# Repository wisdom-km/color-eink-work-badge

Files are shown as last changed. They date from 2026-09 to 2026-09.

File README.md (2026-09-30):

# P36 当前入口（2026-09-30）

当前新设计为3.6寸六色400×600、手机+USB更新、一体66×109×11.1mm工牌。先读[中文开始说明](docs/portrait/START_HERE.md)。源码评审候选仍有PH/SW3、FPC/C118–C121装配阻断，NFC功能尚未设计完成，未做实体测试，不可制造放行。

P36路径：hardware/portrait/、firmware/portrait36/、docs/portrait/。最终已布线KiCad10原生PCB是铜线权威源；不得运行generate.py/gen_pcb.py/旧import_route.py覆盖铜线，不用pcbnew9保存。新电气修订必须备份并重新完整验证；当前报告仅绑定当前SHA。用户已授权此次重新选型、设计和当前文档同步。

## 以下为H2历史基线范围

以下旧4.2寸/ST25/6.3mm/F2未实现及旧流程仅适用历史H2，不覆盖P36新需求/入口/证据。保留原文供追溯；不要按旧生成命令操作P36。通用中文回复、禁止未经要求PR及许可证要求仍有效。

# chroma-badge（BADGE-42C）：4.2 寸四色墨水屏 NFC 工牌

> **当前：** [状态](docs/06-current-status.md) · [交接](docs/03-handoff.md) · [流程](docs/09-process.md)（许可证 / CI / 贴胶 / 生产包）。2026-09-14 复审是**旧 564 段板**档案，不要当现板。

仓库：https://github.com/wisdom-km/chroma-badge

一块 **6.3 mm 厚**的电子工牌：4.2" 黑白红黄四色墨水屏 + ESP32-C3（Wi-Fi/BLE/原生 USB）+ ST25DV64KC NFC + ≤2 mm 超薄锂电 + USB-C。固件目前是 v0.2 上电自检；手机传图（F2）未写。

| 背面 PCB 渲染 | 外壳（FreeCAD） |
|---|---|
| pcb | 见 `hardware/enclosure/output/badge_assembly.step` |

## 在本地接着做

```bash
git clone https://github.com/wisdom-km/chroma-badge.git
cd chroma-badge
```

用 Cursor **打开这个文件夹**（本地 Agent）。根目录 `AGENTS.md` 和 `.cursor/rules/badge.mdc` 会带上约定。

## 仓库

- `LICENSE.md`：硬件 CERN-OHL-P-2.0，固件/脚本 MIT
- `AGENTS.md`：硬性约定与当前进度
- `docs/01-architecture-decisions.md`：选型
- `docs/02-bom-and-cost.md`：BOM；屏贴胶 3M 467MP
- `docs/03-handoff.md`：复现步骤与**当前板**指纹
- `docs/09-process.md`：CI、生产包、贴胶
- `hardware/pcb/`：由 `scripts/design.py` 生成
- `firmware/README.md`：v0.2 自检；不要覆盖 `output/badge-42c-v0.1*.bin`

## 快速开始

全量 ERC/DRC 需要 KiCad **10.0.6**。不要把 `gen_pcb.py` 当日常命令（会清布线）。日常检查：

```bash
cd hardware/pcb
python3 scripts/check_netlist.py
./scripts/export.sh --check-only
```

自动布线流程见 `docs/03-handoff.md` 第 3 节。

## 状态

**H2（2026-09-15）：** 58 封装，PCB **680 段 / 115 过孔**，J1.7 NC。KiCad 10.0.6 全量 ERC/DRC 0。USB **0.8 mm**。固件 **v0.2 F1**。没有生产 zip。

下一步：打样实机；F2 须选定一条传图路线。

## 第三方内容

- 乐鑫 KiCad 库（ESP32-C3-MINI-1）：CC-BY-SA 4.0
- HRO TYPE-C-31-M-14 封装：jenschr/USB-C-Connectors，公有领域
- 其余符号/封装来自 KiCad 官方库

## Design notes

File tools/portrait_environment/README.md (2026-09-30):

# 云端工具链安装与验证（2026-09-30）

本目录记录对已提交的 BADGE-42C H2 基线和本次工具安装的验证。它不是竖版新板的验证报告，也不是生产放行。

## 使用

从仓库根目录执行：

```sh
source tools/portrait_environment/env.sh
kicad-cli version
pio --version
java --version
freerouting -help
freecad-python -c 'import FreeCAD,Part; print(FreeCAD.Version())'
cadquery-python -c 'import cadquery; print(cadquery.__version__)'
```

实际程序安装在 `/workspace/scratch/200245c5fbc3/toolchain`，HOME/XDG/PlatformIO 包与构建缓存也都在该工作区内；不改系统路径、原固件输出或系统安全配置。`env.sh` 绑定当前云端路径，转移到另一台机器须重新安装并调整路径。

## 已验证

| 工具 / 检查 | 版本 / 结果 | 证据 |
|---|---|---|
| KiCad CLI | 官方 Linux Lite AppImage 10.0.6，版本命令 exit 0 | `logs/kicad10-version.log` |
| KiCad pcbnew | 系统 9.0.2，导入成功 | `logs/inventory-initial.log` |
| 原板全量 ERC | 0 violations，exit 0 | `erc-baseline-configured.json` |
| 原板全量 DRC | 0 violations / unconnected / schematic parity，exit 0 | `drc-baseline-configured.json` |
| 网表 vs design.py | 63 nets，exit 0 | `logs/netlist.log` |
| EPD 主机探针 | g++ 14.2.0，20/20 case，exit 0 | `host-probes/epd-probes.json`, `logs/host-probes.log` |
| FreeCAD Part | 1.0.0，立方体有效性、STEP 导出/回读与体积，exit 0 | `logs/freecad-part-smoke.log` |
| CadQuery | 2.7.0，实体体积/有效性，exit 0 | `logs/cadquery-smoke.log` |
| OpenSCAD | 2021.01，STL 导出，exit 0 | `logs/openscad-smoke.log` |
| Java | Temurin JRE 25.0.4.1+1，版本命令 exit 0 | `logs/java25-version.log` |
| Freerouting | 官方 2.4.1，`-help` exit 0 | `logs/freerouting-help.log` |

全量 KiCad 检查包含 warnings、errors、exclusions；DRC 开启 schematic parity。初次未初始化全局 symbol/footprint table 的运行出现配置缺库 warnings，保留在 `*-baseline.json`，**最终结果以 `*-baseline-configured.json` 为准**。全局表已从同一 KiCad 10.0.6 AppImage 自带模板复制到隔离配置目录。

FreeCAD 的 `freecadcmd` 启动在此环境崩溃；已改用官方已安装模块的系统 `/usr/bin/python3` 入口（`freecad-python` 包装器）。CadQuery 使用预装的 Python 3.12；不要与 FreeCAD 的 Python 3.13 混用。

KiCad 使用 Lite 包，不包含官方全套 3D 模型；本次 ERC/DRC 不需要这些模型。机械外观检查必须另外确认所需模型覆盖率，不能以此冒充 3D 全覆盖。

## 固件构建

PlatformIO Core 6.2.0 安装成功；安装日志为 `logs/platformio-install.log`，Python 依赖锁定快照为 `platformio-python-requirements.txt`。工程固定 espressif32@7.1.3。

两次完整编译均通过 exit 0：

1. 当前工作目录构建（包括新 `portrait_frame.cpp` 的当时版本）：`logs/platformio-build.log`
2. 从 HEAD `84f226487c97b10a132f7f11740d5ee0b5bd14c0` 导出的原固件隔离快照：`logs/platformio-baseline-build.log`

两次大小均为 RAM 15320 / 327680 B（4.7%）、Flash 284324 / 1310720 B（21.7%）。未使用的新增代码可被链接器移除，因此大小相同不代表新屏硬件行为已验证。

复现当前固件：`source tools/portrait_environment/env.sh && pio run -d firmware`。原快照使用独立 `PLATFORMIO_BUILD_DIR=$BADGE_TOOLCHAIN_ROOT/platformio-build-baseline`。实际包版本见 `platformio-packages.json`。

首次安装的部分首选包镜像下载校验不匹配，PlatformIO 拒绝后自动改用备用镜像成功；未禁用或跳过完整性校验。完整原始记录保留在构建日志。

`baseline-bin-sha256.txt` 保存原 `firmware/output/badge-42c-v0.1*.bin` 的 SHA256。原 v0.1 应用大小保持 296512 字节；三份文件构建后 SHA256 复核全部 OK，见 `logs/baseline-bin-recheck.log`。

## 来源与完整性

`download-provenance.json` 保存官方来源和哈希。Java 与 Freerouting 下载内容已与官方 API 发布 SHA256 逐字匹配。KiCad 下载自官方页面列出的 CERN 镜像，并记录本地 SHA256；该记录不是独立签名校验。

- KiCad：https://www.kicad.org/download/linux/
- Freerouting：https://github.com/freerouting/freerouting/releases/tag/v2.4.1
- Java：https://adoptium.net/temurin/releases/
- PlatformIO：https://pypi.org/project/platformio/6.2.0/

## 没有做 / 不代表通过

- 未操作实物，未烧录；USB、充电、屏幕 BUSY、NFC、休眠电流仍需真实样机
- 未运行真正 Freerouting 路由任务；后续严格遵守仓库交互 shell、相对路径、日志重定向约定
- 未生成生产 Gerber、生产 ZIP 或下单文件
- 原板 ERC/DRC 通过不意味着竖版新板通过

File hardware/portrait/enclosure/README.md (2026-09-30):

# C1 一体工牌机械评审候选

当前66×109×11.1mm，FreeCAD直接打开output/portrait_assembly_revisionB.FCStd。已保存颜色并关闭/重开验证，116对象，111显示/5审计预留隐藏。历史8.1mm A文件不是当前交付。不要再次保存已冻结native仅为截图，避免SHA链失效。

## 验证及实际范围

七个真实stage完成，execution-provenance.json状态EXECUTED_REVIEW_REQUIRED_C1_PIPELINE；STEP/STL拓扑和原生BREP有效。116对象=36机械/材料/审计/预留+80器件高度代理，81位号中J3为有来源USB盒；不是全厂家装配，不含真实FPC/电池导线/门禁凭证/螺钉实体。PCB core来自最终已布线KiCad板，名义完整0.8审计体预算铜/阻焊；不能假定每个蚀刻边缘承压高度一致。

assembly_review_gates.json保留PH插头预留与SW3、全块FPC预留与C118–C121的5条装配阻断。TP2/TP3庭院笔宽微交叠原样保留，真实铜pad bbox为0交叠。不能缩预留盒掩盖冲突。全1.2mm屏审计与前垫保守交叠仍保留；局部上部0.85/底9mm1.2模型不代表厂家批准压持。制造放行始终blocked。

实际图：portrait_native_C1_iso/front/internal.png、portrait_actual_section.png（厚度显示5倍）、portrait_layer_stack.png。旧portrait_review_overview.png文案可能误读门禁已集成，因此不交付；NFC电路/inlay当前未集成，制式和位置待设计。

## 材料候选与采购数量

- 前框1、齐平后盖1：烟灰半透PETG或经过验证的韧性聚合物，打印方向/收缩/疲劳未合格
- M2×10螺钉4枚，M2六角螺母4枚：名义对边4.0/厚1.6，槽宽4.2/高1.8；实际头部、盲孔和公差需实配，拆卸防散落
- 屏PSA：3M468MP标称0.13mm，3条；左右各0.9×70mm，上50×0.9mm，仅非AA边缘，屏厂胶相容与夹持许可未取得
- 前垫：PORON4790-92PL-09020标称0.50±0.10mm，3条；另3条0.06mm PSA为厚度预算，未锁定可买胶料MPN
- 后垫4处：各0.05mm post PSA +0.15mm PET +0.05mm foam PSA +PORON4701-30密度400、自由0.79±15%压至0.60mm（名义24.05%）。两个0.05胶层为受控预算，不能假称已锁采购MPN

25层名称/坐标在c1_config.OBJECTS和mechanical_expectation.json。后垫均2×2mm，PCB坐标[1,1,3,3]、[55,18,57,20]、[1,89.64,3,91.64]、[41.6,90.14,43.6,92.14]。原厂材料来源链接见c1_config.SOURCES；JST原图sources/JST-PH-official.pdf。

## 首件测量，不可强装

回流后先测PCB平整度、每点承压完成厚度；不要靠螺钉把翘板或玻璃压平。前垫实际间隙目标0.10–0.25mm；名义0.18/最大局部屏厚0.11，示例公差会降到−0.04，未测不可放行。座Z候选2.30..2.60且剩壁≥0.90；超范围重做。

后选PET：实测肩台到支柱H、当地板厚T、两胶a1/a2、自由泡棉f，PET=H−T−a1−a2−0.75f。名义H1.65/T0.8/a总0.10/f0.79得0.1575mm。选垫0..0.40、增量0.025/0.05候选，目标压缩20–30%；达不到则返工支柱/换受控料，不加螺钉力压板。

在全部肩台/玻璃角测含偏转侧游隙，不只中心平移。UPDATE梁0.65厚×13长×4宽、槽0.45；实际静态间隙0.10–0.20，验证行程/止挡/释放/疲劳。0.6名义止挡不证明安全过行程。原配100–102mm电池线和PH配对、FPC弯折/锁扣、USB实物均须试装。RF、温升、跌落、挂绳和磨损仍未测。

## 复现

有效配置为c1_config.configure(只读H2 PORTRAIT)。本次迁移--setup已执行。常规重新生成先c1_pipeline.py --run，再在真实FreeCAD中运行OpenC1RevisionB.FCMacro，最后--finalize。宏只用于该次headless输出，不可对已样式化文件反复执行。任何源修改都要重新验证全链；不得改冻结电气板后沿用旧报告。日常查看直接打开当前FCStd，无需宏。

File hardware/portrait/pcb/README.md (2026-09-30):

# P36 当前电气工程

KiCad10.0.6打开badge.kicad_pro。3.6E六色50针参考电路，非H2旧24针屏。原生已布线badge.kicad_pcb是最终铜线权威源；81封装、968线段、115过孔、10区，板58×92.64×0.8mm，元件B面。

最终证据在仓库根verification/visible-final：DRC/未连/原理图parity0，ignored为空；ERC0错误9条逐项审阅single_global_label警告。81元件/259连接pin/28NC对源一致，warning-review.json保留线端点证据。五页为主索引、usb_mcu、power、boost、display。

设计源scripts/design.py、readable_schematic.py与pinned库均可编辑；不要为检查调用generate.py/gen_pcb.py/import_route.py，它们可能清布线。不要用系统pcbnew9保存本10版板。任何新电气/布线修订须新备份及全量ERC/DRC/parity，原证据不能沿用。

屏关电后SPI控制脚停LOW，BUSY无上拉。独立逻辑/boost磁珠，C100在V_B。电池PH pin1GND/pin2VBAT，仍必须量来料；USB HRO额定1A、0.75对0.8板厚实配待测。充电100mA无电芯NTC。完整采购MPN候选见docs/portrait/procurement_candidates.csv；candidate_bom.csv只是五列工程导出。

当前NFC功能未设计/未集成。PH/SW3和FPC/C118–121空间阻断仍需修订或实物几何证明，EDA0不能放行制造。参见docs/portrait/START_HERE.md。

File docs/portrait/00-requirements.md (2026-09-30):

# P36 已确认需求与决策

2026-09-30；原仓库基线84f2264。用户明确旧显示/尺寸/稳定性不满意，重新选型；选定3.6英寸六色竖向400×600；中等科技公司工牌尺寸；参考一体透明结构，无外卡套；手机与USB均可更新；所有建模、PCB和测试在云电脑可见操作。希望合法门禁但不知道系统。

工程方案为Waveshare32651裸屏、50P0.5FPC、ESP32-C3-MINI-1-N4X、保护500mAh原型电池；板58×92.64×0.8，C1外壳66×109×11.1。厚度从历史8.1增加以容纳有来源保护电池和空间预算；不照抄参考TFT/麦克风/扬声器/50g指标。

放弃旋转旧4.2屏、规格矛盾的GDEH037E01以及外卡套方案。当前NFC功能尚未设计完成，无电路或inlay集成；待确定系统和合法发行方式，不能承诺通用门禁。完整现状和制造阻断见START_HERE.md。

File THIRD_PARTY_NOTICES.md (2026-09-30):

# 第三方归属与修改

补充根LICENSE.md，项目硬件CERN-OHL-P-2.0，项目固件/脚本MIT，第三方保持原许可。

KiCad Community符号/封装来自本机官方库快照，安装资料登记Copyright2025，CC-BY-SA4.0附KiCad Libraries Exception。设计例外不把再分发库集合改成MIT；保留LICENSES的原版权许可。P36修改了Connector过滤器等，不能称未修改官方库。https://www.kicad.org/libraries/license/

Espressif符号/ESP32-C3封装和STEP继承自项目快照，CC-BY-SA4.0及上游KiCad例外，含工程net-tie/路径适配；原获取commit未知，只记录实际文件SHA。https://github.com/espressif/kicad-libraries 。当前官方许可另附，不捏造原下载版本。

HRO TYPE-C-31-M-14封装源jenschr/USB-C-Connectors为Unlicense，现有courtyard/属性/工程路径修改；USB/JST简化STEP为尺寸工程包络，不是厂商精细CAD或实配证据。https://github.com/jenschr/USB-C-Connectors

Waveshare3.6E序列按其MIT许可适配，原版权和固定SHA见firmware/portrait36/THIRD_PARTY_NOTICES.md及随包vendor源。Freerouting补丁保持GPL3，全文/commit/重建见tools/portrait_environment/freerouting-offline；不附router JAR。厂家规格书/商标归原权利人，不构成背书或制造认证。

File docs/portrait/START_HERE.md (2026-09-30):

# P36 六色竖版工牌：先读这里

2026-09-30。当前交付是可编辑源码评审候选，仍有明确装配阻断，禁止据此下单或强行装配。没有实屏、无线、电池、门禁或实体试装通过的声明。

## 当前设计

用户选定 Waveshare 3.6英寸六色裸屏 SKU32651，竖向400×600，50针FPC。显示为静态工牌用途，厂家预计全刷约15秒。屏外形56×86.6mm；新PCB58×92.64×0.8mm；C1一体烟灰外壳名义66×109×11.1mm，无外部卡套。Adafruit1578保护500mAh电池为原型选型，31×38×5.6mm只是工程预算，非供应商最大值/老化膨胀保证。

NFC/门禁功能尚未设计完成：系统制式、合法发行凭证及安装位置均未知；当前没有NFC电路或内置inlay集成，普通NDEF不等于门禁卡。历史overview图及其生成文案不代表已实现门禁，本次不交付该图。

## 打开文件

- KiCad10.0.6：hardware/portrait/pcb/badge.kicad_pro；主图加四子页，已布线board是铜线权威源
- FreeCAD1.0：hardware/portrait/enclosure/output/portrait_assembly_revisionB.FCStd，已保存颜色/可见性，直接打开；不要选历史A文件
- CAD尺寸源：hardware/portrait/enclosure/c1_config.py、c1_geometry.py、build_enclosure.py
- 固件：firmware/portrait36；手机页面：tools/portrait_display/phone
- 采购：docs/portrait/procurement_candidates.csv、procurement_offboard_candidates.csv、procurement_candidates.md；78个装配位置和3个采购数量0的测试焊盘
- 机械材料与装配门槛：hardware/portrait/enclosure/README.md

## 已实际完成的电脑验证

KiCad板含81封装、968线段、115过孔、10区。全量DRC、未连接、原理图一致性均0，忽略规则为空。ERC为0错误、9条single_global_label警告，均有逐项线端点与网表审阅，不称全量ERC0。网表81元件/259已连接pin/28NC与电气源核对。

软件整套host测试与真实PlatformIO编译通过。驱动387案例及5适配模型；USB469短包边界、100000字节畸形输入与11发送器测试；图像48611672像素核对、141060旋转、470中断模型、256调色板和56位损坏测试；手机协议43、服务/电源模型23、DOM8模拟场景。ASan/UBSan启用，LSan因环境ptrace限制关闭。DOM模拟不是真实浏览器或手机WiFi联调。最近编译RAM45932B、Flash784080B，最终以随包pio.log为准。

CAD116对象保存并重开验证，STEP/STL拓扑通过；116=36机械/材料/审计/预留对象+80器件高度代理，81位号中的J3是有来源USB盒。并非116个采购件或81个厂家精细模型；未包含真实FPC、导线、门禁凭证和螺钉实体。保留25层软材料与真实板core、名义铜/阻焊堆叠。

证据路径从仓库根算：电气 verification/visible-final；软件 hardware/portrait/verification/visible-final；机械 hardware/portrait/enclosure/validation。SHA绑定具体源文件，旧中间报告不替代最终报告。

## 手机更新

首次需给新板烧录此目标并完成电源/屏台架验收；本包不含可直接烧录镜像。长按UPDATE约2秒进入最长10分钟本地热点，屏显示临时SSID、密码和连接码。手机连接此热点，按屏上地址打开本地页面，手动输入临时连接码，选择图片、检查六色预览、上传并等待同一任务完成。没有配对二维码；不收集既有家庭/公司WiFi密码；页面无远端字体/CDN。接收有效帧后才单独SHOW，刷新中保持供电；90秒超时表示屏状态未知，不自动再刷。页面生成的RGB预览不是实屏色度测量。

仅支持一名热点客户端。上传前可取消，SHOW后不能保证取消；USB与手机共享单120000B缓冲和来源锁，禁止并发覆盖。成功后保留30秒状态窗口再关热点。短按UPDATE用于从深睡唤醒USB；插USB本身不保证唤醒。

## USB更新

先用手机页面下载原生120000B帧，或用附带样帧。不是portrait-indexed.bin，也不是固件镜像。仓库根执行：

    python3 tools/portrait_display/send_frame.py tools/portrait_display/output/preview400x600/panel-3in6e-native.bin --dry-run
    python3 tools/portrait_display/send_frame.py tools/portrait_display/output/preview400x600/panel-3in6e-native.bin --port /dev/ttyACM0

真实端口须用户/操作员确认，Windows可用实际COM号；需要pyserial3.5。脚本先RESET/HELLO再BEGIN、完整长度/颜色/CRC校验，收到FRAME后才SHOW。它不扫描端口、不烧录。DISPLAY OK仅为设备驱动报告，仍需观察实体屏。

## 必须保留的局限

单帧RAM没有旧帧回滚，也没有Flash/NVS图像持久化；重启状态EMPTY。坏包不会触发屏刷新，但旧RAM可被覆盖。进入热点配对页也会覆盖先前工牌画面。不能把host双缓冲模型测试写成固件掉电原子提交。

assembly_review_gates.json保留PH插头预留与SW3，以及FPC整块预留与C118–C121冲突。必须取得实际配对/折返几何证明或开新设计修订解决，不能缩盒凑PASS。TP2/TP3庭院笔宽代理微交叠另有真实铜pad包围盒0交叠证据，原代理保留。全1.2mm屏厚保守审计也保留，不能用局部0.85/1.2模型声称厂商批准压持。

电池无NTC，MCP73831仅芯片温控；原型受控室温监督充电，需验证密闭温升。还须测高压轨/有效电容/峰值电流、低电及USB切换、ADC阈值、BUSY时序、颜色/二维码、FPC/线束、玻璃夹持/公差、按键寿命、人体RF、ESD和跌落。未做这些实体测试，不承诺续航、门禁或量产安全。

## 复现及许可

已安装KiCad10.0.6、FreeCAD1.0、CadQuery2.7、PlatformIO6.2等，版本和来源见tools/portrait_environment。其他电脑先调整env.sh和visible_final_checks.sh工作区绝对路径。

    source tools/portrait_environment/env.sh
    bash tools/portrait_driver/visible_final_checks.sh
    pio run -d firmware/portrait36

包内vendor oracle可用：bash tools/portrait_driver/run_tests.sh third_party/waveshare-3in6e-ESP32/EPD_3in6e.cpp。

严禁为检查而运行gen_pcb.py、generate.py、旧import_route.py重建最终铜线。系统pcbnew9不可保存最终KiCad10板。固件与旧H2的24针屏不兼容。首次烧录需按实际分区/bootloader配置完整烧录，不能把样帧.bin当固件或盲目写0地址。

硬件CERN-OHL-P-2.0、项目固件/脚本MIT，第三方保持原许可，见LICENSE.md与THIRD_PARTY_NOTICES.md。没有购买、下单、生产Gerber放行、固件烧录或Git远端提交。

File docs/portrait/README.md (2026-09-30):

# P36 当前工程入口

请先读 [中文开始说明](START_HERE.md)。当前为3.6寸六色400×600、66×109×11.1mm一体工牌源码评审候选；手机和USB功能源码已实现并通过host测试/真实编译。装配阻断和实体测试仍未闭合。

采购候选见 [完整MPN清单](procurement_candidates.csv) 与 [采购说明](procurement_candidates.md)。电气、软件、CAD证据路径及使用方法均在开始说明中。H2旧文件仅为历史，不代表P36功能或尺寸。

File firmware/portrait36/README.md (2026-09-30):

# P36 手机与USB六色更新固件

400×600、每像素4bit，单缓冲120000B，颜色黑0白1黄2红3蓝5绿6；不兼容H2屏。完整用户流程见docs/portrait/START_HERE.md。

长按UPDATE(GPIO1)约2秒启动限时本地SoftAP；屏上给临时SSID/密码/32hex连接码，手动输入，没有配对QR。页面处理图片、六色量化、CRC和≤4096B分块；全部API临时token校验，最多1客户端10分钟，不使用用户既有WiFi凭据。上传合法完整后独立SHOW，成功后30秒状态窗口再关AP。USB同一会话锁，send_frame.py先校验再SHOW。

单缓冲无旧RAM回滚、无Flash/NVS图片持久化，重启EMPTY；无效包不刷新屏但可覆盖RAM。配对页会覆盖先前画面。手机真实浏览器/WiFi/堆峰值未实测；DOM8场景是模拟。

GPIO：电源2 LOW开；SCK6、MOSI7、CS10、DC20、RST21、BUSY3 LOW忙；UPDATE1 RTC唤醒；VBUS ADC4；电池ADC0；BOOT9仅维护。SPI mode0 MSB-first1MHz。所有返回硬断屏电源，控制线LOW，BUSY INPUT无上拉；04/12/02操作要求有界LOW→HIGH。无SPI物理ACK，超时边界待实屏温区验证。

60秒无USB/AP/上传且UPDATE释放后深睡；短按UPDATE唤醒USB，插USB本身不保证唤醒。电源阈值电池估算≥3.6V或VBUS ADC≥1000mV，真实ADC/峰值需校准。初次仅受控台架测试。

仓库根source tools/portrait_environment/env.sh，然后pio run -d firmware/portrait36。完整host套件bash tools/portrait_driver/visible_final_checks.sh。最新编译RAM45932B、Flash784080B；最终以pio.log为准。测试为host/adapter模型、真实编译，不代表硬件成功。本源码包不附固件镜像；样帧.bin绝不是烧录文件。厂商序列与许可见THIRD_PARTY_NOTICES.md。

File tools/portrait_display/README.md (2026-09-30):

# 当前范围说明（2026-09-30）

手机与USB的单帧固件已在firmware/portrait36实现并通过host测试/真实编译，详见docs/portrait/START_HERE.md。下文是图像工具与双缓冲/提交模型测试的模块说明；其旧“未来/未集成”表述不再描述整个P36项目。模型的旧帧/断电原子性不能用于声称当前固件有Flash持久化或旧RAM回滚。下文保留作算法测试范围记录。

# P1 竖版显示与帧完整性探针

此目录是新增、隔离的显示工具，不改 H2 的 `epd.cpp`、`main.cpp`、引脚或 NFC 协议。
P1 软件基线是 Waveshare **3.6inch e-Paper (E)，400×600 原生竖版、六色、4 bit/pixel**。
屏幕颜色来自厂商色码；PNG 的 RGB 仅用于排版预览，**不是实屏色彩、反射率、刷新速度或可读性测量**。

## 文件与边界

- `firmware/include/portrait_frame.h` / `firmware/src/portrait_frame.cpp`：无 Arduino、无堆分配的借用缓冲区视图；通用 1/2/4/8-bit 像素访问、90°/180°/270° 旋转；3.6E 完整帧合法色码检查和 CRC-32/ISO-HDLC
- `render_preview.py`：占位中文姓名、职位、公司，白底黑字，少量六色强调；按参数生成原始像素 PNG、通用索引帧、旋转帧；仅主规格额外导出官方色码原生帧
- `frame_cli.cpp`：调用实际 C++ 模块做旋转和原生帧校验，供 Python 交叉检查
- `test_frame.cpp`：独立逐位 oracle、逐像素双射和往返证明、缓冲区哨兵、非法尺寸/位深/颜色/坐标/重叠测试
- `test_transaction.cpp`：**主机双缓冲内存模型**，验证完整接收且色码/CRC 正确之前不切换当前帧；不是固件传输栈、Flash 事务、线程原子操作或断电恢复实现

没有实现 NFC 图传、门禁卡模拟、访问凭证、BLE 配对或新屏硬件引脚集成。

## 原生格式

400×600 像素，共 **120,000 字节**。行主序，每个字节高四位在前，两像素一字节，无行填充；主屏原生就是竖版，因此 **不旋转**。

| 颜色 | 原生 nibble |
|---|---:|
| 黑 | 0x0 |
| 白 | 0x1 |
| 黄 | 0x2 |
| 红 | 0x3 |
| 蓝 | 0x5 |
| 绿 | 0x6 |

0x4 及 0x7–0xF 均拒绝。CRC 使用反射多项式 0xEDB88320，初值/终值异或均为 0xFFFFFFFF；标准向量 `123456789` 得 `CBF43926`。CRC 仅检测意外损坏，**不认证发送方**。

Python 排版器内部语义索引是黑/白/红/黄/蓝/绿 = 0/1/2/3/4/5，因此必须经显式映射 **0/1/3/2/5/6** 后才能送屏。`portrait-indexed.bin` 不可直接送屏；400×600 六色输出里的 `panel-3in6e-native.bin` 才使用厂商编码。两种格式刻意使用不同文件名，防止黄红互换和非法色码 4。

官方来源（已检视源文件，固定版本）：

- [Waveshare EPD_3in6e.h](https://github.com/waveshareteam/e-Paper/blob/a794fbc39656b0f93938d1ffb3fdc77eaed9e9fc/E-paper_Separate_Program/3.6inch_e-Paper_E/ESP32/EPD_3in6e.h)
- [Waveshare EPD_3in6e.cpp](https://github.com/waveshareteam/e-Paper/blob/a794fbc39656b0f93938d1ffb3fdc77eaed9e9fc/E-paper_Separate_Program/3.6inch_e-Paper_E/ESP32/EPD_3in6e.cpp)

通用旋转遵循像素中心坐标：顺时针 `(x, y) → (H−1−y, x)`，逆时针 `(x, y) → (y, W−1−x)`，半转 `(x, y) → (W−1−x, H−1−y)`。毫米板框的边界坐标变换不可直接拿来当像素索引。

## 复现

仓库根目录运行，依赖 C++17 g++、Python、Pillow、reportlab、libzbar 和 NotoSansCJK Regular/Bold。字体位置可通过 `--regular-font` / `--bold-font` 指定；manifest 记录实际字体 SHA256。相同参数、字体和依赖生成相同像素与文件哈希，不写入时间戳。

```sh
python tools/portrait_display/run_tests.py --out tools/portrait_display/output/tests
python tools/portrait_display/render_preview.py --out tools/portrait_display/output/preview400x600
# 可选：检查排版尺寸参数，不把它们宣称为已选硬件
python tools/portrait_display/render_preview.py --width 480 --height 720 --out /tmp/portrait480x720
python tools/portrait_display/render_preview.py --width 300 --height 400 --colors 4 --out /tmp/portrait300x400
```

`run_tests.py` 打开 AddressSanitizer 和 UndefinedBehaviorSanitizer，编译警告视为错误。容器 ptrace 下 LeakSanitizer 不可用，所以显式关闭漏检并记录；不能宣称完成了内存泄漏检测。

预览输出：

- `portrait.png`：1:1 原始像素，主规格 400×600
- `portrait-2x.png`：严格最近邻 2× 放大，仅供看排版
- `portrait-indexed.bin` / `landscape-cw90-indexed.bin`：通用语义索引帧
- `panel-3in6e-native.bin`：仅 400×600 六色主规格；120,000 B 厂商原生编码
- `manifest.json`：规格、字体哈希、帧 CRC/SHA256、独立 QR 解码、Python/C++ 逐像素旋转一致性

二维码是固定版本 3、纠错 M、四模块白色留边，整数像素模块。内容为保留的不可解析演示地址 `https://example.invalid/badge-demo`，不是门禁凭证或真实员工链接。libzbar 必须能独立读出原图和旋转图；无法解码时生成命令失败，不静默标通过。

## 稳定性验证能说明什么

- 尺寸/深度有效时，通用读写及旋转不越界；负坐标、短缓冲、非法色值、重叠旋转直接拒绝
- 1–13 像素的每组宽高、每个位深均使每种颜色到达每个位置；300×400×2、400×600×4、480×720×4 对所有颜色和所有像素检查三种旋转及逆变换
- 完整帧检查拒绝错误长度、非法 nibble、CRC 不匹配
- 内存模型覆盖每个 256 字节边界处中断、乱序/重复/过长包、取消、重试和二次提交；最后确认的旧帧在失败前保持不变

仍然**没有**测过真实总线、显示故障回滚、Flash 掉电、长时间运行、天线、供电电流、温度或整机。也没有实现把内存模型部署到设备。

400×600×4 的双帧占 240,000 B；480×720×4 的双帧占 345,600 B。ESP32-C3 的可用堆还要留给系统、协议栈和驱动，主机模型不能直接当作可用固件 RAM 方案。生产实现需依据实际最大空闲块评估暂存到 Flash/外部存储、单帧渲染或分块输出；生产刷新前仍须完整校验，不能收到半帧就刷屏。

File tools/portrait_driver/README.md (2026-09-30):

# P36 驱动及完整软件验证

真实最终证据：hardware/portrait/verification/visible-final。可见运行visible_final_checks.sh：驱动387例（日志386是中间轮，不能相加）+5GPIO/SPI模型；USB469接收边界/100000畸形字节/11sender例；手机协议43、服务电源模型23、DOM8；完整图像测试及PIO编译。最新RAM45932、Flash784080，最终看pio.log。ASan/UBSan启用，LSan受ptrace限制。

驱动逐字对照固定Waveshare源120061SPI字节；适配模型与故障注入不代表实体SPI/屏BUSY/RF。完整固件使用单120000B缓冲，已实现手机和USB传输；未实机。工具链来源见tools/portrait_environment。包内oracle命令：bash tools/portrait_driver/run_tests.sh third_party/waveshare-3in6e-ESP32/EPD_3in6e.cpp。

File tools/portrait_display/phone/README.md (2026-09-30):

# 手机浏览器前端

长按新板 UPDATE 键（GPIO1）2 秒进入限时配网；BOOT（GPIO9）只用于维护，不作为更新入口。

无框架、无外部字体/CDN。图片缩放、白底透明合成、六色量化、可选 Floyd–Steinberg 抖色和 CRC 都在手机浏览器里运行。
原生 400×600×4-bit 编码固定为黑0/白1/黄2/红3/蓝5/绿6；可直接下载 120KB bin，交给同一 USB 发送脚本。
RGB 是软件预览近似，不代表实屏色度测量。

接口由隔离目标的 phone 服务实现：

- GET `/api/status`
- POST `/api/reset`，空 body
- POST `/api/begin`，JSON `{size:120000,crc:"8位hex"}`
- POST `/api/chunk?offset=N`，最多4096字节二进制
- POST `/api/show`，JSON `{crc:"8位hex"}`，202返回后查询同一个 job 的真实终态

全部 API 带 `X-P36-Token` 32位临时随机hex；页面从链接片段 `#token=...` 读取后立即清除地址栏片段，只保存在页面内存，不写入localStorage。网页自身可无认证访问。不能将测试模拟器的全零 token 用于固件。

只有同 job 的 `display_status=done` 且 `result=Ok` 才报告设备完成。刷新时服务可能暂时无响应，前端限时重试查询；90秒后提示屏面状态未知，绝不自动重发 SHOW。
上传取消仅在发送 SHOW 前有效；刷新开始后隐藏取消按钮，提示保持供电。

## 生成固件资产

```sh
python tools/portrait_display/build_phone_page.py
node tools/portrait_display/phone/test_core.js
```

生成 `firmware/portrait36/include/phone_page.h`，`epd36::kPhoneIndexHtml` 为 Flash/PROGMEM 内联资源，不需要上传 SPIFFS 文件系统。
修改 HTML/JS 后必须重新生成，不手改生成头文件。

## 验证范围

当前交付不含mock服务器或运行时凭据。test_app.js的8个DOM场景和test_core.js为host模型，真实浏览器访问本地模拟器曾被环境阻止，未绕过。没有Safari/Chrome/真实热点联调通过声明。生产页面没有固定token，手动输入屏上临时连接码。

测试图片可用tools/portrait_display/output/preview400x600/portrait.png。JS对原始RGBA的量化输出已与C++校验的原生bin逐字核对。详细使用步骤见docs/portrait/START_HERE.md。

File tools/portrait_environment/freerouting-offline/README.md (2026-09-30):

# Freerouting 2.4.1 网络行为审计与本地候选

日期：2026-09-30。审计固定官方 commit `ae3d377740b6ffa744bed1bab26625fe0278fa90`。这是软件源代码与编译产物审计，不是一次用户PCB路由。

## 原版结论

1. CLI 的布线计算在本地进程完成，并非把原始 DSN 提交云端路由。
2. **默认遥测启用**，会向 `https://api.freerouting.app/v1/analytics/identify` 与 `/track` 发 POST。原 CLI 并不等于零外联。
3. `-da` 或 `--usage_and_diagnostic_data.disable_analytics=true` 可关闭遥测；`--profile.allow_telemetry=false` 也会关闭同一发送开关。
4. **找不到关闭版本检查的官方设置**。版本检查无条件查询 GitHub releases/latest，甚至 `-help` 也先启动该线程。因此不能把这些参数称为“严格离线模式”。
5. 本次源码审计没有运行原版或新候选JAR，没有执行任何用户DSN，也没有复试原被拒绝的命令。

### 原版调用路径与精确行号

所有行号对应上面的未修改官方 commit，基址：
https://github.com/freerouting/freerouting/blob/ae3d377740b6ffa744bed1bab26625fe0278fa90/

- `src/main/java/app/freerouting/Freerouting.java:80–163`：创建本地 Session/Job，读取文件，等待本地 scheduler
- `src/main/java/app/freerouting/core/RoutingJob.java:446–453`：FileInputStream/readAllBytes
- `src/main/java/app/freerouting/management/jobs/RoutingJobScheduler.java:90–96,236–241`：加载本地 DSN 对象、创建/启动线程
- `src/main/java/app/freerouting/management/jobs/RoutingJobSchedulerActionThread.java:99–167`：RoutingPipeline.createForHeadless(job)，pipeline.run()
- `src/main/java/app/freerouting/Freerouting.java:197–224`：Files.write 保存输出
- `src/main/java/app/freerouting/settings/UsageAndDiagnosticDataSettings.java:10–12`：disableAnalytics 默认 false
- `src/main/java/app/freerouting/settings/UserProfileSettings.java:17–19`：allow_telemetry 默认 true
- `src/main/java/app/freerouting/Freerouting.java:1269–1270,1318–1319,1360–1386`：先读取env/CLI，再设置遥测enabled；关闭参数在首次identify之前生效
- `src/main/java/app/freerouting/settings/GlobalSettings.java:516–555,814–817`：通用 `--key=value` 与 `-da` 解析
- `src/main/java/app/freerouting/analytics/FreeroutingAnalyticsClient.java:24,75–115,158–190`：HTTP发送端点、enabled guard、POST JSON、identify/track
- `src/main/java/app/freerouting/Freerouting.java:1416–1426`：无条件版本线程早于帮助退出
- `src/main/java/app/freerouting/util/VersionChecker.java:18–19,69–89`：固定GitHub URL、User-Agent=Freerouting-Version-Checker、无body的GET请求；没有设置开关

### 默认可能传送的内容

- identify：配置生成的profile ID、email（如有）、OS/版本/语言、同意设置。`FRAnalytics.java:274–293`
- appStarted：原始命令行字符串（可含输入/输出文件名）、软件/Java/OS、CPU/RAM/语言等。`FRAnalytics.java:388–428`；调用处 `Freerouting.java:1397–1414` 传的是 `String.join(" ",args)`
- fileLoaded：board statistics JSON，含尺寸/bounding box、元件/层/网/走线等统计；不等同于完整DSN。`HeadlessBoardManager.java:759–779`、`FRAnalytics.java:549–575`、`core/scoring/BoardStatistics.java:35–78`
- routing/optimizer：全局settings JSON、运行时间、最终board hash/未连网/间距统计等。`FRAnalytics.java:466–540`
- 异常：异常消息、异常文字、stacktrace。`FRAnalytics.java:592–610`

源码可以证明“有尝试发送的路径”，**不能证明先前某次请求实际已被远端接收**。先前只带 `-help` 的安装烟雾测试没有输入PCB文件，但原版仍可能尝试发应用元数据遥测及版本GET；不能回溯声称那次严格零外联。

### 原版降低风险参数，不是完整离线保证

`-da --profile.allow_telemetry=false --gui.enabled=false --api_server.enabled=false --mcp_server.enabled=false --mcp_server.stdio=false`

它们可关闭遥测与服务器/GUI；仍无法禁用上述GitHub版本请求。没有使用假代理、放宽TLS或规避既有安全限制来掩盖这个缺口。

## 独立本地候选修改

工作副本：`/workspace/scratch/200245c5fbc3/toolchain/freerouting-offline-source`

`local-only.patch` 是针对官方固定commit的补丁；未修改原始clone或原始官方JAR。仅6个Java文件改变：

- `FRAnalytics.setAccessKey` 不构造backend，analytics保持null
- FreeroutingAnalyticsClient、SegmentClient、BigQueryClient 的发送方法为no-op
- BigQuery service创建返回null，不解析凭据、刷新token或连接Google
- VersionChecker不构建HTTP client，run()为no-op；main不再启动版本线程
- main在解析CLI/env后强制禁用GUI/API/MCP/telemetry，参数不能重新开启
- REST/MCP工厂均直接返回null，防止监听器/代理分支意外开启
- 启动文字明确包含 LOCAL-ONLY PATCHED BUILD

`verify_offline_source.py` 验证上述静态条件，并确认277个routing/board/geometry/core/rules/io/drc/management文件与官方逐字相同。结果在 `static-verification.json`。注意：归档仍含不可达的服务器/GUI与第三方依赖类，不能用字符串搜索“仍有https”判断是否调用；也不能把源码证明替代为运行时网络隔离证明。

GPL-3.0保留，见 `FREEROUTING-GPL-LICENSE.txt` 与原始source `LICENSE`。这不是badge项目的MIT脚本代码重新许可。保留官方源commit、完整本地副本、patch、编译与封装脚本，不伪称官方发布版本。

## 构建状态与替代路径

- Temurin JDK25.0.4.1+1 官方包校验成功
- 官方 Gradle9.7.1 distribution与原wrapper内SHA256匹配
- 官方 executableJar构建尝试失败：当前Java/Gradle对foojay插件解析失败，未进入编译；见gradle日志。未禁用TLS校验或添加信任证书
- 经任务负责人确认，改用JDK25 javac对6个修改类编译，以哈希固定的官方v2.4.1 fat JAR作classpath，退出0
- `package_overlay.py` 验证官方JAR SHA，替换6个类及其旧inner classes，保留其他归档项逐字一致；写新版本标记/patch hash
- 明确这是**javac overlay候选，不是通过官方Gradle的完整源码构建**

最终候选、SHA、所有替换类和原封装对照数量见 `artifact-manifest.json`。反编译证据在 `candidate-bytecode.txt`。没有运行候选。

## 下一步仅限审查后的无用户数据烟雾测试

1. 先审核patch、源码静态结果、javap no-op方法与候选SHA
2. 若获准执行新候选，使用本目录单独生成的 `synthetic.dsn`，新空配置目录、相对SES输出、交互shell、日志重定向；不传用户板
3. 先-help再synthetic一轮，观察网络系统调用；期望没有外部HTTP/DNS/connect，生成非空synthetic.ses
4. 核实输出可解析、程序正常退出，检查日志明确LOCAL-ONLY；仍不能以exit0替代DRC或路由完成指标
5. 任何外部网络尝试、未知开关、artifact hash不一致或审查拒绝即停止，不试原始遥测命令
6. 用户板的后续执行由负责人在审查证据后单独决定，本次没有授权运行它

这份文档不批准原来被拒绝的上传路径，也不批准改变系统网络/安全设置。

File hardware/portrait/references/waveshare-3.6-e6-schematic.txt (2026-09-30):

             1                                                            2                                                                                         3                                                                                                                4                                                                       5                                                               6                                                                         7                                                            8

    COJ1
    J1                        0
                        GND PIJ100

                           1
                     NC PIJ101           NLTFT0VCOM       COC1
                           2             TFT_VCOM         C1           4.7uF/25V                                                                                                                                                                                                          COD1
                                                                                                                                                                                                                                                                                           D1
            TFT_VCOM PIJ102              NLFPL0VCOM
                                                           PIC101 PIC102                                             V_B                                     COL1                                                                                                                                                                            COR1
                           3             FPL_VCOM                                                                                                            L1                                                                                                                                                                              R1
             FPL_VCOM    PIJ103                   PIR2001  PIR2002 PIC201 PIC202
                                                                 COC2                                                                                  PIL101                             PIL102                                                                                    PID101 PID102          VPH                       PIR102         PIR101   VGH             3V3_OUT
                           4                        COR20        C2
                     NC PIJ104           NLGDRH     R20 0R                                                                                                    10uH
                           5             GDRH                      470nF/25V                                                                                                                                                                                                                                                                 0R
                  GDRH PIJ105
                           6             NLRESEH
                                         RESEH                                                                                                                                                               PIQ103 COQ1                           PIC302 COC3                            MBR0530                         PIC402                                                              COL3
                                                                                                                                                                                                                                                                                                                                                                                              L3
                                                                                                                                                                                                                                                                                                                                                                                                                          EPD_3V3

                                                                                                                                                                                                           3
A                RESEH   PIJ106                                                                                                                                                                                                                             C3                                                                       COC4                                                                                                                                                                                                                                                A
                           7                                                                                                                                                                                                                                                                                                          C4                                                 PIL301                  PIL302
                  GDRL PIJ107
                           8
                                                                                                                                                                                 1
                                                                                                                                                                               PIQ101                                    Q1                        PIC301   10uF/25V
                                                                                                                                                                                                                                                                                                                          PIC401 10uF/25V                                                     BLM18PG121SN1D
                    GND PIJ108                                                                                                                                                                                           AO3400                                                          COD2
                                                                                                                                                                                                                                                                                         D2
                           9             NLGDRC
                                         GDRC                                                                         PIC502                                                                                                                                                                                                                                                                                                V_B
                  GDRC PIJ109
                           10            NLRESEC
                                         RESEC                                                                                   COC5
                                                                                                                                 C5                                                                          PIQ102                                                                 PID202 PID201    VGL                                                                                      COL4
                                                                                                                                                                                                                                                                                                                                                                                              L4
                                                                                                                                                                                                                                                                                                                                                                                                                                                                                     BCMWPi                     COP1
                                                                                                                                                                                                                                                                                                                                                                                                                                                                                                                 P1                                                           BCMWPi

                                                                                                                                                                                                           2
                 RESEC PIJ1010                                                                                                                                                                                                                                                                                                                                                           PIL401                  PIL402
                           11
                    VPC PIJ1011
                                         NLVPC
                                         VPC                                                                          PIC501 4.7uF/25V                                   GDRH                                   RESEH                                                                                                                                                                         BLM18PG121SN1D                                                                  1                    RPI_3V3PIP101 3V3         5V PIP102
                                                                                                                                                                                                                                                                                                                                                                                                                                                                                                                                      NLRPI05V
                                                                                                                                                                                                                                                                                                                                                                                                                                                                                                                                      RPI_5V                             2
                           12
                    GND PIJ1012                                                                                                                                      PIR202                                  PIR302
                                                                                                                                                                                                                                                                                          MBR0530       PIC602                                                                                                               PIC2902                                          3       2     8             PIP103
                                                                                                                                                                                                                                                                                                                                                                                                                                                                                                                   SDA1      5V PIP104
                                                                                                                                                                                                                                                                                                                                                                                                                                                                                                                                      RPI_5V                             4
                           13            NLVGL
                                         VGL                                                                                                                                  COR2                                    COR3                                                                                       COC6
                                                                                                                                                                                                                                                                                                                 C6                                                                                                                    COC29
                                                                                                                                                                                                                                                                                                                                                                                                                                       C29                                    5       3     9                                         GND                                6
                    VGL  PIJ1013
                                         NLVPH                                                                                                                                 R2                                     R3                                                                                PIC601 10uF/25V                                                                                                      PIC2901 100uF/6.3V                                                           PIP105 SCL1      GND  PIP106
                           14            VPH                                                                                                                                   1MΩ                                    0.2Ω                                                               COD3
                                                                                                                                                                                                                                                                                         D3                                                                                                                                                                                   7       4     7                                                                            8     14   15
                    VPH PIJ1014          NLVSH                     COC7
                                                                                                                                                                                                                                                                                                                                                                                                                                                                                                          PIP107 GPIO7     TXD PIP108
                           15            VSH                       C7       10uF/25V                                                                                 PIR201                                  PIR301                                                                                                                                                                                                                                                           9                    GND PIP109                                                            10    15   16
                    VSH PIJ1015          NLVSH0LV
                                                                    PIC701 PIC702
                                                                   COC8                                                                                                                                                                                                                                                                                                                                                                                                                                            GND     RXD PIP1010
                           16
                         PIJ1016         VSH_LV                    C8         10uF/25V
                                                                    PIC801 PIC802
                                                                                                                                                                                                                                                                                PID301      PID302                                                                                                                                                                            11      17    0      EPD_RST'
                                                                                                                                                                                                                                                                                                                                                                                                                                                                                                          PIP1011                     PWR                                12    18   1
                VSH_LV                   NLVSH0LV2                 COC9                                                                                                                                                                                                                                                                                                                                                                                                                                            GPIO0  GPIO1 PIP1012
                           17            VSH_LV2                   C9         10uF/25V                                                                                                                                                                                                                                                                                                                                                                                        13      27    2                                         GND                                14
               VSH_LV2 PIJ1017           NLVSL
                                                                    PIC901 PIC902
                                                                   COC10                                                                                                                                                                                                                 MBR0530                                                                                                                            GND                                                                           PIP1013 GPIO2    GND PIP1014
                           18            VSL                       C10        10uF/25V                                                                                                                                                                                                                                                                                                                                                                                        15      22    3                                                                            16    23   4
                    VSL PIJ1018          NLVSL0LV
                                                                    PIC1001 PIC1002
                                                                   COC11
                                                                                                                                                                                                                                                                                                                                                                                                                                                                                                          PIP1015 GPIO3   GPIO4 PIP1016
                           19
                         PIJ1019         VSL_LV                    C11        10uF/25V
                                                                    PIC1101 PIC1102                                                                                                                                                                                                                                                                                                                                                                                           17                   RPI_3V3PIP1017 3V3                 EPD_BUSY'
                                                                                                                                                                                                                                                                                                                                                                                                                                                                                                                                PIP1018                                  18    24   5
                VSL_LV                   NLVSL0LV2                 COC12                                             GND                                                                                   GND                                                                                                          GND                                                                                                                                                                                               GPIO5
                           20            VSL_LV2                   C12        10uF/25V                                                                                                                                                                                                                                                                                                                                                                                        19      10    12     EPD_DIN'                           GND                                20
               VSL_LV2 PIJ1020                                      PIC1201 PIC1202                                                                                                                                                                                                                                                                                                                                                                                                                       PIP1019 MOSI     GND PIP1020
                           21                                                                                                                                                                                                                                                                                                                                                                                                                                                 21      9     13                                        EPD_DC'                            22    25   6
           GNDA+(GND) PIJ1021                                      COC30
                                                                                                                                                                                                                                                                                                                                                                                                                                                                                                          PIP1021 MISO    GPIO6 PIP1022
                           22                                      C30        1uF/50V                                                                                                                                                                                                                                                                                                                                                                                         23      11    14     EPD_SCK'                           EPD_CS'                            24    8    10
                  REFN   PIJ1022                                    PIC3001 PIC3002
                                                                   COC31
                                                                                                                                                                                                                                                                                                                                                                                                                                                                                                          PIP1023 SCLK      CE0 PIP1024
                           23                                      C31        1uF/50V                                                                                                                                                                                                                                                                                                                                                                                         25                   GND PIP1025                                                           26    7    11
                   REFP PIJ1023                                     PIC3101 PIC3102
                                                                                                                                                                                                                                                                                                                                                                                                                                                                                                   NLSDA0          GND      CE1 PIP1026
                           24                                                                                                                                                                                                                                                                                                                                                                                                                                                 27      0     30     SDA0 PIP1027                       SCL0                               28    1    31
                   TSCL PIJ1024                                                                                                                                                                                                                                                                                                                                                                                                                                                                                    SDA0    SCL0 PIP1028
                           25                                                                                                                                                                                                                                                                                                                                                                                                                                                 29      5     21                                        GND                                30
                  TSDA   PIJ1025
                                         NLBS0                                                                                                                                                                                                                                                                                                                                 VDD                                                                                                                        PIP1029 GPIO21   GND PIP1030
                           26            BS0                                                                                                                                                                                                                                                                                                                          1 PIJ201                                                                                                31      6     22                                                                           32    12   26
                     BS0 PIJ1026                                                                                                                                                                                                                                                                                                                                               BS0                                                                                                                        PIP1031 GPIO22 GPIO26 PIP1032
                           27                                                                                                                                                                                                                                                                                                                                     BS PIJ202                                                                                                   33      13    23                                        GND                                34
                     BS1 PIJ1027         NLEPD0RST'
                                                                                                                                                                                                                                                                                                                                                                                                                                                                                                          PIP1033 GPIO23   GND PIP1034
                           28            EPD_RST'                                                                                                                                                                                                                                                                                                                     0 PIJ203                                                                                                35      19    24                                                                           36    16   27
                 RST_N   PIJ1028
                                         NLEPD0BUSY'                                                                                                     V_B                                                                                                                                                                                                                                                                                                                                                    GPIO24 GPIO27
                                                                                                                                                                                                                                                                                                                                                                                                                                                                                                             PIP1035                     PIP1036
                           29            EPD_BUSY'                                                                                                                                                                                                                                                                                                               COJ2                                                                                                         37      26    25                                                                           38    20   28
                BUSY_N PIJ1029           NLEPD0DC'                                                                                                                                                                                                                                                                                                               J2                                                                                                                                     PIP1037 GPIO25 GPIO28 PIP1038
                           30            EPD_DC'                                                                                                                                                                                                                                                                                                                                                                                                                              39                    GND PIP1039                                                          40    21   29
                     DC PIJ1030          NLEPD0CS'                                                                                                                                                                                                                                                                                                                              GND                                                                                                                             GND    GPIO29 PIP1040
                           31            EPD_CS'
                   CSB1 PIJ1031
                           32            NLEPD0SCK'
                                         EPD_SCK'
                                                                                                                                                          PIR402                                                             PIC1302                                                                                                                                                                                                                                                                                    RPI GPIO
                    SCL PIJ1032                                                                                                                                    COR4
                                                                                                                                                                    R4                                                                 COC13
                           33            NLEPD0DIN'
                                         EPD_DIN'                                                                                                                  1MΩ
                                                                                                                                                                                                                                       C13
                     SI0 PIJ1033                                                                                                                                                                                                                                                                                          BS                                         VCC                   GND
                           34
                     SI1 PIJ1034                                                                                                                          PIR401                                                             PIC1301 4.7uF/25V
B                          35                                                                                                                                                                                                                                                                                                                                                                                                                                                                                                                                                            B
                     SI2 PIJ1035
                           36                                                                                                                                                                     PIQ202                                                                                                                Interface                                3-line SPI            4-line SPI                                                                                                                VCC_INT                RPI_5V

                                                                                                                                                                                             2
                     SI3 PIJ1036                                   COC14
                           37                                      C14          2.2uF/6.3V    EPD_3V3                                                                                                       Q2 GND
                                                                                                                                                                                                            COQ2
                VDDDO PIJ1037            NLVDD     COR21
                                                                    PIC1401 PIC1402                                                     GDRC                           1
                           38
                         PIJ1038         VDD       R21
                                                    PIR2101        0R
                                                               PIR2102
                                                                                                                                                                    PIQ201
                                                                                                                                                                                                            SI2301CDS-T1-E3
                    VDD
                           39
                    GND PIJ1039
                           40            NLVDDIO
                                         VDDIO COR22
                                                 R22               0R                                                                                                                             PIQ203                                                                                             Type                          BS1                             BS0                SPI mode

                                                                                                                                                                                             3
                 VDDIO PIJ1040                   PIR2201       PIR2202                                                                                                                                                                    COD4
                                                                                                                                                                                                                                          D4
                           41            NLVCP2
                                         VCP2                      COC15
                                                                   C15          1uF/50V
                   VCP2  PIJ1041
                                         NLCP2N
                                                                    PIC1501 PIC1502                                                                                                                                                                              VPC
                           42            CP2N                                                                                                                                                                                PID402 PID401
                   CP2N PIJ1042          NLCP2P           COC17
                           43            CP2P             C17          1uF/50V
                   CP2P PIJ1043          NLVCP1
                                                           PIC1701 PIC1702
                                                          COC18                                                                                                                                                                            MBR0530                                                    1                                  0                            0               4-wire SPI
                   VCP1
                           44
                         PIJ1044         VCP1             C18          1uF/50V
                                                           PIC1801 PIC1802                                                                                                                        PIL202                                                          PIC1602
                           45            NLCP1N
                                         CP1N                                                                                                                                                              COL2
                                                                                                                                                                                                           L2                                                               COC16
                   CP1N PIJ1045                                                                                                                                                                                                                                              C16
                           46
                   CP1P PIJ1046
                                         NLCP1P
                                         CP1P             COC20
                                                          C20          1uF/50V                  PIC1902                                                                                                    10uH
                                                                                                                                                                                                                                                                  PIC1601 10uF/25V
                 CGH1N
                           47
                         PIJ1047
                                                           PIC2001 PIC2002
                                                                                                          COC19
                                                                                                          C19                                                                                                                                                                                         2                                  0                            1               3-wire SPI
                           48
                 CGH1P PIJ1048
                                                                                                PIC1901 100nF/50V
                           49
                    VGH PIJ1049
                                         NLVGH
                                         VGH         COR23
                                                      R23
                                                                         COC21
                                                                         C21                                                                                                                      PIL201
                           50
               VCOMBD PIJ1050
                                         NLVCOMBD
                                         VCOMBD PIR2301    PIR2302 PIC2101 PIC2102                                                                      RESEC
                                                                                                                                                                                                                         COR5
                                                                                                                                                                                                                          R5                                                                          3                                  1                            0          Standard 4-wire
                                                                                                                                                                                                                  PIR502               PIR501
                                                              0R
    FPC 0.5 50P 4.37inch                                                 470nF/25V                                                                                                                                        0.2Ω                                                                                                                                                   SPI/Dual SPI/Quad SPI
                                                                                                                                                                                                                                                                 GND
                                                                                                                                                                                                                                                                                                      4                                  1                            1
                                     GND                                                GND

                                                                                                                                                                                                            COQ3
                                                                                                                                                                                                            Q3
C                                                                                                                                                                                                                                                                                                                                                                                                                                                                                                                                                                                        C
                                                                                                          VCC_INT                                                                                 2                           3
                                                                                                                                                                                          PIQ302                         PIQ303                  VCC
                                                                                                                                                        C22PIC2 02
                                                                                                                                                       COC22                             PIR602COR6
                                                                                                                                                                                                  R6
                                                                                                                               PIR702 100nF/50VPIC2 01                                                                   SI2301CDS-T1-E3
                                                                                                                                                                                                  47K
                                                                                                                                                                                                                PIQ301                                                                                                                                                                                                                                                                                                                 GND
                                                                                                                                                                                                             1
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

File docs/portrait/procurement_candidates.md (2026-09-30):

# P36 采购候选与询价清单

2026-09-30。81个PCB位号全部映射：78个装配位置，TP2/TP3/TP4三个制造测试焊盘采购数量为0。完整MPN、厂家、询价渠道、来源链接见 procurement_candidates.csv；屏和电池见 procurement_offboard_candidates.csv。数量不含损耗、备件、起订量。

SELECTED表示用户或受托工程选定，SOURCE_SPECIFIED表示电气源明确料号，REFERENCE_EXACT表示参考电路指定，CANDIDATE表示有来源的采购候选。全部装配件均待首件验证；未核现货、报价或交期，未下单。不能把本表直接当成贴片厂可替代料的生产BOM。

C1/C2/C4明确选16V替代原10V最低值，C123选16V替代原6.3V最低值。R101/R103为Panasonic ERJ-6DSFR20V，0.2欧1%0805，0.5W@70°C；5秒过载指标不是重复boost脉冲资格。Q2保持SI2301CDS-T1-E3，不按通用符号名误买AO3401A。SW1/2/3为2.5mm高度PTS810候选，不能沿用1.5mm旧描述。

采购前逐项核完整后缀、生命周期、封装、可追溯渠道和当前规格书；不接受仅容值或近似型号的静默替代。测量MLCC直流偏压后的有效电容、各高压轨峰值/纹波、电感峰值/RMS/饱和/温升、采样电阻脉冲、MOS和二极管应力。额定值不等于系统裕量已通过。

Adafruit1578的31×38×5.6mm是工程预算，非厂家保证最大值或老化膨胀保证。保留原配线并验证PH极性、批次尺寸及配对空间。两线电池无NTC，MCP73831只调节芯片温度，无电芯温度输入和安全计时器；原型须受控室温、监督充电和密闭壳温升验证。

机械胶带、PET、PORON、螺钉等见C1参数源与机械说明。当前PH预留与SW3、FPC预留与C118–121仍有装配阻断；采购候选表不消除这些冲突。门禁系统未知，不采购或承诺通用门禁模块。

本脚本只核数据覆盖、CSV读回和受保护源SHA不变，不调用KiCad/硬件生成器，不代表电气、热、RF或机械验收通过。

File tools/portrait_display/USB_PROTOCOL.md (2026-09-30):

# P1 USB 完整图片更新

仅用于新 **3.6E 400×600 六色** 独立目标，不适用于旧 H2 4.2 寸板。这里只增加 USB 数据传输，不执行硬件烧录。

## 使用

先生成或从手机页面下载厂商原生色码文件，不要发送语义索引文件：

```sh
python tools/portrait_display/send_frame.py --dry-run tools/portrait_display/output/preview400x600/panel-3in6e-native.bin
# 用户已核对新屏/新板供电并自行烧录匹配固件后，再指定真实串口：
python tools/portrait_display/send_frame.py --port COM5 badge-400x600-native.bin
# Linux 示例：--port /dev/ttyACM0；macOS：实际 /dev/cu.* 设备
```

实际发送依赖 `pyserial==3.5`；`--dry-run` 不依赖串口库，不枚举或打开任何设备。
发送脚本不搜索串口、不烧录固件、不访问网络、不保存密码或凭证。
打开串口可能影响个别开发板的复位接线，需首件确认；程序不主动切换 DTR/RTS。

## 双阶段协议 P36V1

命令是严格 ASCII 行，以 LF 或 CRLF 结束；数据阶段是固定长度的二进制，**没有**行结束符。

1. `RESET` → `RESET`：清理待上传状态；不刷新、不擦屏
2. `HELLO` → `P36V1 EMPTY`，或已有有效 USB 待刷帧时 `P36V1 READY <CRC>`
3. `BEGIN 120000 <8位十六进制CRC>` → `READY 120000`
4. 恰好 120000 字节原生帧 → 长度/色码/CRC 合格才返回 `FRAME <CRC>`
5. 单独发送 `SHOW <相同CRC>` → `DISPLAYING <CRC>`，驱动完成后 `DISPLAY OK <CRC>` 或 `ERR DISPLAY <原因> PANEL_STATE_UNKNOWN`

单独收到完整帧不会启动高压；只有显式 SHOW 才调用显示驱动。重启后状态 EMPTY，默认电源关闭，不自动刷新。
旧单数字纯色串口快捷键已移除，避免随机字符误触发。驱动仍保留 `refresh_solid` 供明确的诊断调用。

### 失败处理

- 错误长度、非法字段、色码、CRC、过长命令：拒绝，要求 RESET
- 接收间隔 3 秒或总时长 30 秒到限：丢弃待上传状态，要求 RESET
- 未结束命令 1 秒到限：拒绝，要求 RESET
- 待刷帧 120 秒过期：释放来源锁，需重新上传
- 分配不到完整 120 KB 连续缓冲：NO_MEMORY，不进入接收或刷新
- SHOW 前再次完整校验，检测接收完成后到刷新前的意外数据变化
- 驱动 BUSY 未应答/超时：硬断电并报告具体阶段；不会自动重刷

串口发送端只在准确收到本帧 FRAME 确认后发送 SHOW；设备拒绝、CRC 不符或超时都不会自动再发 SHOW。
发送 SHOW 后任何响应丢失都按“物理屏面状态未知”处理，不把缺少确认当作刷新成功。

## 单缓冲与手机来源锁

`FrameSession` 是单主循环使用的公用状态机；USB 和本地 HTTP 都使用同一块 **120000 B** 借用缓冲，没有第二帧副本。

- `begin(source,size,crc,now)` 获取 USB 或 Phone 来源锁
- `append(source,offset,data,count,now)` 严格连续偏移，拒绝重复、跳号、超长块；达到完整长度时自动校验
- `finish(source)` 检查是否已完成；`show(source,crc,now)` 才刷新
- 另一个来源的 begin/append/finish/show/reset 返回 Busy，不改原会话；HTTP 应映射为 409
- 超时释放锁；有效帧由原来源持有至 reset 或 120 秒过期
- 实体 UPDATE 键长按 2 秒专用 `prepare_local_frame` 可替换已完成的待刷帧，但不能打断正在接收的帧；它用于把临时配网信息画到屏上，不可暴露成网络 API
- 以上对象不支持并发线程/中断调用；HTTP 必须在同一 Arduino loop 中处理

错误或半帧不会触发新刷新，因此不要求屏幕改变当前画面。**这不是旧帧软件回滚**：新上传会覆盖唯一 RAM 缓冲；没有上一帧可重发副本、Flash 历史、掉电事务或断电恢复保证。刷新一旦开始后失败，屏幕可能停在中间状态。

固件打印启动时的空闲堆和最大 8-bit 连续块，然后检查 `heap_caps_malloc(120000)` 结果。链接器的静态 RAM 数字不含运行期这 120 KB、USB 缓冲及手机 Wi-Fi 开销，不能拿编译成功替代真实最大连续堆测量。

## 验证

```sh
bash tools/portrait_display/run_usb_tests.sh
bash tools/portrait_driver/run_tests.sh
source tools/portrait_environment/env.sh
PLATFORMIO_BUILD_DIR="$BADGE_TOOLCHAIN_ROOT/platformio-build-portrait36-usb" pio run -d firmware/portrait36
```

主机仿真直接编译实际 FrameSession、USB parser、CRC 与屏驱动：

- 469 个不完整接收边界保持不触发新刷新；完整接收单独不刷新
- 错误长度/字段/色码/CRC、越长数据、重复/跳号块、命令超时、时钟回绕、无缓冲、重启、随机串口噪声
- USB/Phone 双向来源互斥，以及实体配网画面接口只在非接收状态接管
- 已生成的真实 120KB 原生文件经串口 parser 进入驱动后，SPI 图像逐字节相同
- 未插屏 BUSY 常高、刷新 BUSY 超时：返回失败并断电；正常重试必须明确 SHOW
- Python 发送端部分写入、拒绝响应、断连、错误应答与安全停止

ASan/UBSan 开启；LeakSanitizer 因执行环境 ptrace 限制未运行。没有真实 USB 设备、无线电、供电电压、实屏或 Flash 掉电测试。

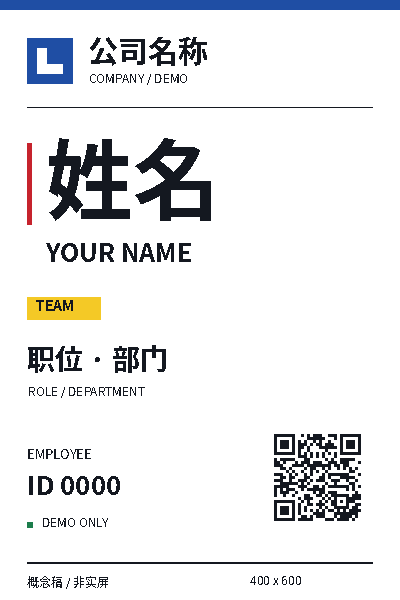
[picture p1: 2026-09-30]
hardware/portrait/enclosure/assets/firmware_demo_400x600.png

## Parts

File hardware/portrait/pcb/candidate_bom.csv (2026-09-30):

Reference | Value | Footprint | Description | DNP
J3 | USB-C 16P 沉板 (TYPE-C-31-M-14) | badge:TYPE-C-31-M-14 | HRO TYPE-C-31-M-14, 16P USB 2.0 mid-mount receptacle | False
R1 | 5.1k | Resistor_SMD:R_0402_1005Metric | 5.1k 0402 1% | False
R2 | 5.1k | Resistor_SMD:R_0402_1005Metric | 5.1k 0402 1% | False
C1 | 4.7u | Capacitor_SMD:C_0603_1608Metric | 4.7uF 10V X5R 0603 | False
U3 | MCP73831T-2ACI/OT | Package_TO_SOT_SMD:SOT-23-5 | Microchip MCP73831 4.2V charger; 10k PROG nominal100mA; protected single-cell LiPo only | False
R3 | 10k | Resistor_SMD:R_0402_1005Metric | MCP73831 RPROG10k -> nominal100mA, verify actual cell rating | False
R4 | 1k | Resistor_SMD:R_0402_1005Metric | 1k 0402 1% | False
D4 | RED | LED_SMD:LED_0603_1608Metric | LED 0603 red, charging indicator | False
C2 | 4.7u | Capacitor_SMD:C_0603_1608Metric | 4.7uF 10V X5R 0603 | False
J2 | JST PH2.0 battery | Connector_JST:JST_PH_S2B-PH-SM4-TB_1x02-1MP_P2.00mm_Horizontal | JST S2B-PH-SM4-TB; Adafruit1578 keyedPHR2 mate: contact1GND/contact2VBAT; verify incoming lot keyedface+voltage beforepower; retain original lead | False
U4 | XC6220B331MR-G | Package_TO_SOT_SMD:SOT-23-5 | LDO 3.3V Iq 8uA 1A SOT-25 VIN/GND/CE/NC/VOUT. Torex 3.0-3.5V pair: CIN=10uF CL=4.7uF near U4. | False
C3 | 10u | Capacitor_SMD:C_0603_1608Metric | 10uF 6.3V X5R 0603 LDO CIN (Torex table, 3.3V with CL=4.7uF) | False
C4 | 4.7u | Capacitor_SMD:C_0603_1608Metric | 4.7uF 10V X5R 0603 LDO CL near VOUT (Torex 3.00-3.50V + CIN=10uF) | False
R5 | 1M | Resistor_SMD:R_0402_1005Metric | 1M 0402 1% | False
R6 | 1M | Resistor_SMD:R_0402_1005Metric | 1M 0402 1% | False
C5 | 100n | Capacitor_SMD:C_0402_1005Metric | 100n 0402 | False
TP4 | VBAT | TestPoint:TestPoint_Pad_D1.0mm | test pad | False
TP2 | 3V3 | TestPoint:TestPoint_Pad_D1.0mm | test pad | False
TP3 | GND | TestPoint:TestPoint_Pad_D1.0mm | test pad | False
U1 | ESP32-C3-MINI-1-N4X | badge:ESP32-C3-MINI-1 | Espressif current C3 MINI1 N4X; module antenna clearance and RF on-body test required | False
C6 | 10u | Capacitor_SMD:C_0603_1608Metric | 10uF 6.3V X5R 0603 | False
C7 | 100n | Capacitor_SMD:C_0402_1005Metric | 100n 0402 | False
R7 | 10k | Resistor_SMD:R_0402_1005Metric | 10k 0402 1% | False
C8 | 1u | Capacitor_SMD:C_0402_1005Metric | 1u 0402 | False
R8 | 10k | Resistor_SMD:R_0402_1005Metric | 10k 0402 1% | False
R10 | 10k | Resistor_SMD:R_0402_1005Metric | 10k 0402 1% | False
R9 | 1k | Resistor_SMD:R_0402_1005Metric | 1k 0402 1% | False
D5 | GREEN | LED_SMD:LED_0603_1608Metric | LED 0603 green, status | False
SW1 | RESET | Button_Switch_SMD:SW_SPST_PTS810 | C&K PTS810; nominalheight2.5mm(+.2/-.1); travel.15+/-.1mm; actuator/flexure must be tested | False
SW2 | BOOT/USER | Button_Switch_SMD:SW_SPST_PTS810 | C&K PTS810; nominalheight2.5mm(+.2/-.1); travel.15+/-.1mm; actuator/flexure must be tested | False
Q10 | AO3401A | Package_TO_SOT_SMD:SOT-23 | P-MOS battery load-share, sourceVSYS/drainVBAT; body diode VBAT->VSYS; AN1149 topology | False
R20 | 100k | Resistor_SMD:R_0402_1005Metric | 100k 0402 1% | False
D10 | SS14 | Diode_SMD:D_SMA | USB to VSYS Schottky40V1A; evaluate thermal and droop | False
C30 | 22u | Capacitor_SMD:C_0805_2012Metric | 22uF10V X5R0805 | False
J1 | EPD50 FH34SRJ | badge:FH34SRJ-50S-0.5SH | Hirose FH34SRJ-50S-0.5SH(50); .5pitch50P dualcontact .3FPC; pending footprint drawing verification | False
Q20 | AO3401A | Package_TO_SOT_SMD:SOT-23 | 3V3 panel hard powergate; default10k gatepullup OFF; SPI pins hi-Z before poweroff | False
C100 | 100u/6.3V | Capacitor_SMD:C_1210_3225Metric | 100uF6.3V X5R1210; effectivecap/inrush verify | False
C101 | 100n | Capacitor_SMD:C_0402_1005Metric | 100n 0402 | False
FB1 | BLM18PG121SN1D | Inductor_SMD:L_0603_1608Metric | Murata BLM18PG121SN1D from vendorboost reference | False
L1 | 10uH | Inductor_SMD:L_Changjiang_FNR4018S | 10uH shielded4x4x1.8; Isat>=1A target pending vendor peak-current test; no47uH substitute | False
L2 | 10uH | Inductor_SMD:L_Changjiang_FNR4018S | 10uH shielded4x4x1.8; Isat>=1A target pending vendor peak-current test; no47uH substitute | False
Q1 | AO3400A | Package_TO_SOT_SMD:SOT-23 | N-MOS as vendorAO3400 stage | False
Q2 | SI2301CDS-T1-E3 | Package_TO_SOT_SMD:SOT-23 | Vishay P-MOS exactly vendor negative-boost stage | False
R100 | 1M | Resistor_SMD:R_0603_1608Metric | 1M; vendorstage; sense resistors0.2ohm>=0.25W | False
R101 | 0.2R | Resistor_SMD:R_0805_2012Metric | 0.2R; vendorstage; sense resistors0.2ohm>=0.25W | False
R102 | 1M | Resistor_SMD:R_0603_1608Metric | 1M; vendorstage; sense resistors0.2ohm>=0.25W | False
R103 | 0.2R | Resistor_SMD:R_0805_2012Metric | 0.2R; vendorstage; sense resistors0.2ohm>=0.25W | False
R104 | 0R | Resistor_SMD:R_0603_1608Metric | 0R; vendorstage; sense resistors0.2ohm>=0.25W | False
D1 | MBR0530 | Diode_SMD:D_SOD-123 | 30V0.5A Schottky as vendor reference; pin1K pin2A | False
D2 | MBR0530 | Diode_SMD:D_SOD-123 | 30V0.5A Schottky as vendor reference; pin1K pin2A | False
D3 | MBR0530 | Diode_SMD:D_SOD-123 | 30V0.5A Schottky as vendor reference; pin1K pin2A | False
D6 | MBR0530 | Diode_SMD:D_SOD-123 | 30V0.5A Schottky as vendor reference; pin1K pin2A | False
C110 | 4.7u/25V | Capacitor_SMD:C_0805_2012Metric | 4.7u/25V X7R/X5R0805; voltage-rated; DC-bias capacitance vendor verification required | False
C111 | 470n/25V | Capacitor_SMD:C_0805_2012Metric | 470n/25V X7R/X5R0805; voltage-rated; DC-bias capacitance vendor verification required | False
C112 | 10u/25V | Capacitor_SMD:C_0805_2012Metric | 10u/25V X7R/X5R0805; voltage-rated; DC-bias capacitance vendor verification required | False
C113 | 10u/25V | Capacitor_SMD:C_0805_2012Metric | 10u/25V X7R/X5R0805; voltage-rated; DC-bias capacitance vendor verification required | False
C114 | 4.7u/25V | Capacitor_SMD:C_0805_2012Metric | 4.7u/25V X7R/X5R0805; voltage-rated; DC-bias capacitance vendor verification required | False
C115 | 10u/25V | Capacitor_SMD:C_0805_2012Metric | 10u/25V X7R/X5R0805; voltage-rated; DC-bias capacitance vendor verification required | False
C116 | 10u/25V | Capacitor_SMD:C_0805_2012Metric | 10u/25V X7R/X5R0805; voltage-rated; DC-bias capacitance vendor verification required | False
C117 | 10u/25V | Capacitor_SMD:C_0805_2012Metric | 10u/25V X7R/X5R0805; voltage-rated; DC-bias capacitance vendor verification required | False
C118 | 10u/25V | Capacitor_SMD:C_0805_2012Metric | 10u/25V X7R/X5R0805; voltage-rated; DC-bias capacitance vendor verification required | False
C119 | 10u/25V | Capacitor_SMD:C_0805_2012Metric | 10u/25V X7R/X5R0805; voltage-rated; DC-bias capacitance vendor verification required | False
C120 | 10u/25V | Capacitor_SMD:C_0805_2012Metric | 10u/25V X7R/X5R0805; voltage-rated; DC-bias capacitance vendor verification required | False
C121 | 10u/25V | Capacitor_SMD:C_0805_2012Metric | 10u/25V X7R/X5R0805; voltage-rated; DC-bias capacitance vendor verification required | False
C122 | 4.7u/25V | Capacitor_SMD:C_0805_2012Metric | 4.7u/25V X7R/X5R0805; voltage-rated; DC-bias capacitance vendor verification required | False
C123 | 2.2u/6.3V | Capacitor_SMD:C_0805_2012Metric | 2.2u/6.3V X7R/X5R0805; voltage-rated; DC-bias capacitance vendor verification required | False
C124 | 1u/50V | Capacitor_SMD:C_0805_2012Metric | 1u/50V X7R/X5R0805; voltage-rated; DC-bias capacitance vendor verification required | False
C125 | 10u/25V | Capacitor_SMD:C_0805_2012Metric | 10u/25V X7R/X5R0805; voltage-rated; DC-bias capacitance vendor verification required | False
C126 | 1u/50V | Capacitor_SMD:C_0805_2012Metric | 1u/50V X7R/X5R0805; voltage-rated; DC-bias capacitance vendor verification required | False
C127 | 1u/50V | Capacitor_SMD:C_0805_2012Metric | 1u/50V X7R/X5R0805; voltage-rated; DC-bias capacitance vendor verification required | False
C128 | 1u/50V | Capacitor_SMD:C_0805_2012Metric | 1u/50V X7R/X5R0805; voltage-rated; DC-bias capacitance vendor verification required | False
C129 | 470n/25V | Capacitor_SMD:C_0805_2012Metric | 470n/25V X7R/X5R0805; voltage-rated; DC-bias capacitance vendor verification required | False
C130 | 1u/50V | Capacitor_SMD:C_0805_2012Metric | 1u/50V X7R/X5R0805; voltage-rated; DC-bias capacitance vendor verification required | False
C131 | 1u/50V | Capacitor_SMD:C_0805_2012Metric | 1u/50V X7R/X5R0805; voltage-rated; DC-bias capacitance vendor verification required | False
U5 | USBLC6-2SC6 | Package_TO_SOT_SMD:SOT-23-6 | ST USBLC6-2SC6; DS4260pinmap; short GNDreturn; systemESDtest pending | False
FB2 | BLM18PG121SN1D | Inductor_SMD:L_0603_1608Metric | Separate logic ferrite branch as vendor reference; EPD_SUPPLY is gated3V3 | False
SW3 | UPDATE | Button_Switch_SMD:SW_SPST_PTS810 | C&K PTS810; nominalheight2.5mm(+.2/-.1); travel.15+/-.1mm; actuator/flexure must be tested | False
R21 | 100k | Resistor_SMD:R_0402_1005Metric | External100kRTCwakepullup; sleep only afterrelease | False
R22 | 1M | Resistor_SMD:R_0402_1005Metric | 1M 0402 1% | False
R23 | 330k | Resistor_SMD:R_0402_1005Metric | 330k 0402 1% | False
C32 | 100n | Capacitor_SMD:C_0402_1005Metric | 100n 0402 | False

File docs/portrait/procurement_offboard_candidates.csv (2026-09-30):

Item | Manufacturer | ManufacturerMPN | ProcurementChannel | PurchaseQtyPerBadge | SourceURL | Notes | EngineeringStatus | QualificationStatus | StockVerified | PhysicalValidationComplete | ResearchDate
3.6inch E6 raw display | Waveshare | 32651 | Waveshare direct | 1 | https://www.waveshare.com/3.6inch-e-paper-hat-plus-e.htm?sku=32651 | Vendor600x400 used portrait400x600;exact50pin panel;verify incoming FPC,marking and dimensions. | SELECTED | FIRST_ARTICLE_PENDING | False | False | 2026-09-30
Protected500mAh pack | Adafruit | 1578 | Adafruit direct | 1 | https://www.adafruit.com/product/1578 | Original PH lead100-102mm retained;31x38x5.6 is engineering budget not supplier maximum or swelling allowance;incoming polarity/dimensions mandatory;100mA charge/500mA discharge delivered-pack and thermal qualification pending. | SELECTED | FIRST_ARTICLE_PENDING | False | False | 2026-09-30
NPTH holes and slots | N/A | N/A | PCB fabrication artwork | 0 | N/A | Fabrication features only;no fitted hardware implied. | FAB_ONLY | FABRICATION_FEATURE | False | False | 2026-09-30

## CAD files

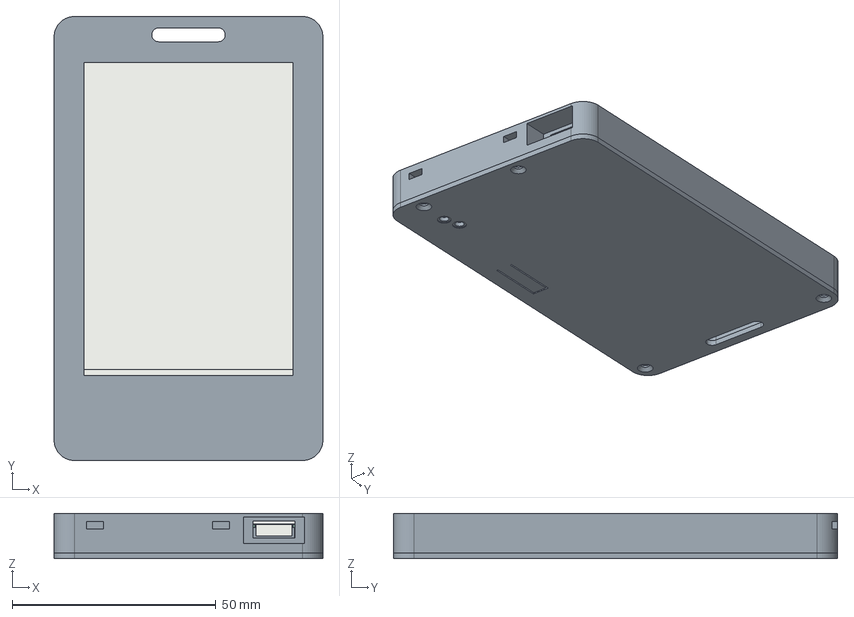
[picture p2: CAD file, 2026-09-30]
hardware/portrait/enclosure/output/portrait_assembly.step
66.0 x 109.0 x 11.1 mm
FrontFrame
BackCover
Display_Local_Max_Envelope
PCB_KiCad_Core_In_Mechanical_Frame
Battery_Adafruit1578_Envelope
USB_HRO_Body_Envelope
ScreenPSA_Left
FrontFoam_Left
FrontPSA_Left
ScreenPSA_Right
FrontFoam_Right
FrontPSA_Right
ScreenPSA_Top
FrontFoam_Top
FrontPSA_Top
RearPostPSA_1
RearPET_1
RearFoamPSA_1
RearFoam_1
RearPostPSA_2
RearPET_2
RearFoamPSA_2
RearFoam_2
RearPostPSA_3
RearPET_3
RearFoamPSA_3
RearFoam_3
RearPostPSA_4
RearPET_4
RearFoamPSA_4
RearFoam_4

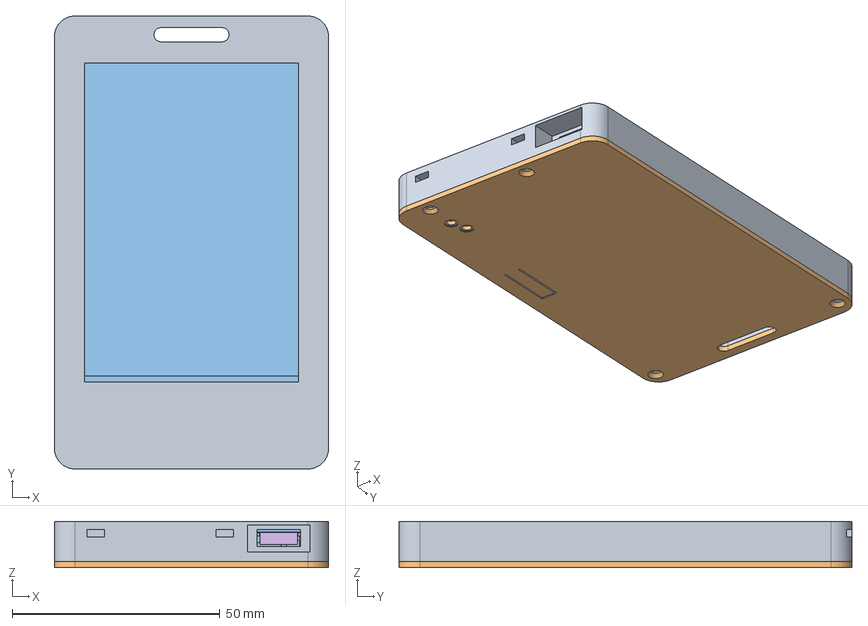
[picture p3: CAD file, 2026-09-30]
hardware/portrait/enclosure/output/portrait_assembly_revisionB.FCStd
66.0 x 109.0 x 11.1 mm
FrontFrame
BackCover
Display_Local_Max_Envelope
PCB_KiCad_Core_In_Mechanical_Frame
Battery_Adafruit1578_Envelope
USB_HRO_Body_Envelope
ScreenPSA_Left
FrontFoam_Left
FrontPSA_Left
ScreenPSA_Right
FrontFoam_Right
FrontPSA_Right
ScreenPSA_Top
FrontFoam_Top
FrontPSA_Top
RearPostPSA_1
RearPET_1
RearFoamPSA_1
RearFoam_1
RearPostPSA_2
RearPET_2
RearFoamPSA_2
RearFoam_2
RearPostPSA_3
RearPET_3
RearFoamPSA_3
RearFoam_3
RearPostPSA_4
RearPET_4
RearFoamPSA_4
RearFoam_4
C1 [height envelope]
C100 [height envelope]
C101 [height envelope]
C110 [height envelope]
C111 [height envelope]
C112 [height envelope]
C113 [height envelope]
C114 [height envelope]
C115 [height envelope]
C116 [height envelope]
C117 [height envelope]
C118 [height envelope]
C119 [height envelope]
C120 [height envelope]
C121 [height envelope]
C122 [height envelope]
C123 [height envelope]
C124 [height envelope]
C125 [height envelope]
C126 [height envelope]
C127 [height envelope]
C128 [height envelope]
C129 [height envelope]
C130 [height envelope]
C131 [height envelope]
C2 [height envelope]
C3 [height envelope]
C30 [height envelope]
C32 [height envelope]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

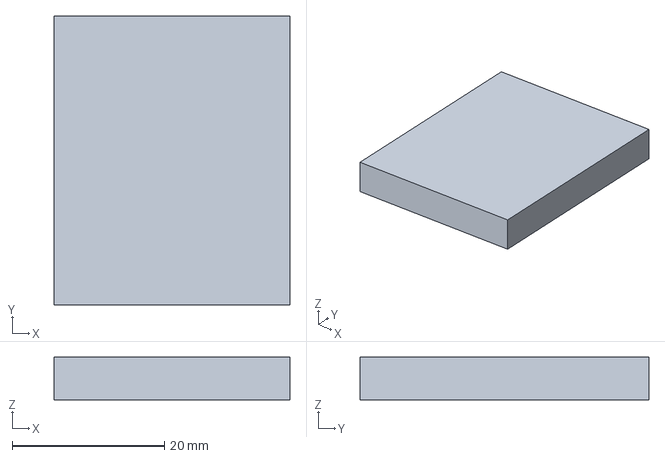
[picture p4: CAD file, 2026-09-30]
hardware/portrait/enclosure/output/reference_battery_envelope.step
31.0 x 38.0 x 5.60 mm

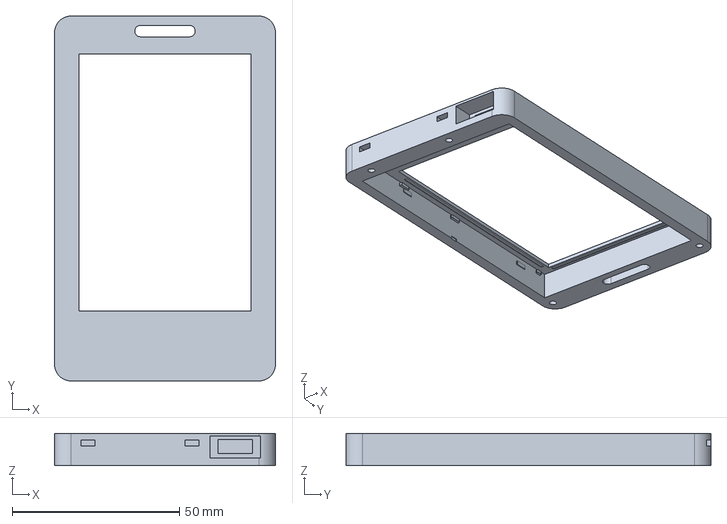
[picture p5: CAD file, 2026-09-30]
hardware/portrait/enclosure/output/portrait_front_frame.step
66.0 x 109.0 x 9.70 mm

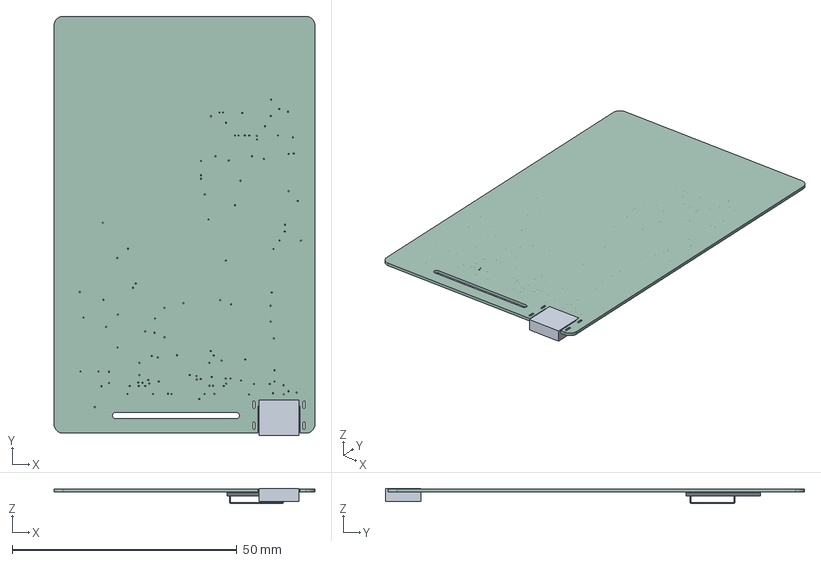
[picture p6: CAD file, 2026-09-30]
hardware/portrait/enclosure/output/pcb_actual_export.step
58.0 x 93.2 x 3.25 mm
DFN1006.STEP^DFN1006.STEP_Submodel-SOD882_part_DesignRootModel_PCB_ ESP32-C3-MINI-1_V1(2)_PCB_ESP32-C3-MINI-1_V1
R0201_20210301.STEP^R0201_20210301.STEP_Submodel-R0201_part_ DesignRootModel_PCB_ESP32-C3-MINI-1_V1(2)_PCB_ESP32-C3-MINI-1_V1 x 3
placementOutline^Submodel-noModelForPart_MINI-ANT-TYPED-H_1968823293_ Submodel-MINI-ANT-TYPED-H_1968823293_part_DesignRootModel_PCB_ ESP32-C3-MINI-1_V1(2)_PCB_E
placementOutline-0^Submodel-noModelForPart_MINI-ANT-TYPED-H_1968823293_ Submodel-MINI-ANT-TYPED-H_1968823293_part_DesignRootModel_PCB_ ESP32-C3-MINI-1_V1(2)_PCB
placementOutline-1^Submodel-noModelForPart_MINI-ANT-TYPED-H_1968823293_ Submodel-MINI-ANT-TYPED-H_1968823293_part_DesignRootModel_PCB_ ESP32-C3-MINI-1_V1(2)_PCB
placementOutline-2^Submodel-noModelForPart_MINI-ANT-TYPED-H_1968823293_ Submodel-MINI-ANT-TYPED-H_1968823293_part_DesignRootModel_PCB_ ESP32-C3-MINI-1_V1(2)_PCB
placementOutline-3^Submodel-noModelForPart_MINI-ANT-TYPED-H_1968823293_ Submodel-MINI-ANT-TYPED-H_1968823293_part_DesignRootModel_PCB_ ESP32-C3-MINI-1_V1(2)_PCB
placementOutline-4^Submodel-noModelForPart_MINI-ANT-TYPED-H_1968823293_ Submodel-MINI-ANT-TYPED-H_1968823293_part_DesignRootModel_PCB_ ESP32-C3-MINI-1_V1(2)_PCB
placementOutline-5^Submodel-noModelForPart_MINI-ANT-TYPED-H_1968823293_ Submodel-MINI-ANT-TYPED-H_1968823293_part_DesignRootModel_PCB_ ESP32-C3-MINI-1_V1(2)_PCB
trace_4^Submodel-MINI-ANT-TYPED-H_1968823293_part_DesignRootModel_PCB_ ESP32-C3-MINI-1_V1(2)_PCB_ESP32-C3-MINI-1_V1
trace_1^Submodel-MINI-ANT-TYPED-H_1968823293_part_DesignRootModel_PCB_ ESP32-C3-MINI-1_V1(2)_PCB_ESP32-C3-MINI-1_V1
C0402_20210301.STEP^C0402_20210301.STEP_Submodel-C0402_part_ DesignRootModel_PCB_ESP32-C3-MINI-1_V1(2)_PCB_ESP32-C3-MINI-1_V1
C0201_20210301.STEP^C0201_20210301.STEP_Submodel-C0201_part_ DesignRootModel_PCB_ESP32-C3-MINI-1_V1(2)_PCB_ESP32-C3-MINI-1_V1 x 11
L0201_20210301.STEP^L0201_20210301.STEP_Submodel-L0201_part_ DesignRootModel_PCB_ESP32-C3-MINI-1_V1(2)_PCB_ESP32-C3-MINI-1_V1 x 2
XTAL3225_20210301.STEP^XTAL3225_20210301.STEP_Submodel-XTAL3225_part_ DesignRootModel_PCB_ESP32-C3-MINI-1_V1(2)_PCB_ESP32-C3-MINI-1_V1
ESP32-C3_20210301.STEP^ESP32-C3_20210301.STEP_Submodel-QFN32_0P5_5_ part_DesignRootModel_PCB_ESP32-C3-MINI-1_V1(2)_PCB_ESP32-C3-MINI-1_V1
uid__4^DesignRootModel_PCB_ESP32-C3-MINI-1_V1(2)_PCB_ESP32-C3-MINI-1_ V1
uid__4-22^DesignRootModel_PCB_ESP32-C3-MINI-1_V1(2)_PCB_ ESP32-C3-MINI-1_V1
uid__4-23^DesignRootModel_PCB_ESP32-C3-MINI-1_V1(2)_PCB_ ESP32-C3-MINI-1_V1
uid__4-24^DesignRootModel_PCB_ESP32-C3-MINI-1_V1(2)_PCB_ ESP32-C3-MINI-1_V1
uid__4-25^DesignRootModel_PCB_ESP32-C3-MINI-1_V1(2)_PCB_ ESP32-C3-MINI-1_V1
uid__4-26^DesignRootModel_PCB_ESP32-C3-MINI-1_V1(2)_PCB_ ESP32-C3-MINI-1_V1
uid__4-27^DesignRootModel_PCB_ESP32-C3-MINI-1_V1(2)_PCB_ ESP32-C3-MINI-1_V1
uid__4-28^DesignRootModel_PCB_ESP32-C3-MINI-1_V1(2)_PCB_ ESP32-C3-MINI-1_V1
uid__4-29^DesignRootModel_PCB_ESP32-C3-MINI-1_V1(2)_PCB_ ESP32-C3-MINI-1_V1
uid__4-30^DesignRootModel_PCB_ESP32-C3-MINI-1_V1(2)_PCB_ ESP32-C3-MINI-1_V1
uid__4-31^DesignRootModel_PCB_ESP32-C3-MINI-1_V1(2)_PCB_ ESP32-C3-MINI-1_V1
uid__4-32^DesignRootModel_PCB_ESP32-C3-MINI-1_V1(2)_PCB_ ESP32-C3-MINI-1_V1
uid__4-33^DesignRootModel_PCB_ESP32-C3-MINI-1_V1(2)_PCB_ ESP32-C3-MINI-1_V1
uid__4-34^DesignRootModel_PCB_ESP32-C3-MINI-1_V1(2)_PCB_ ESP32-C3-MINI-1_V1
uid__4-35^DesignRootModel_PCB_ESP32-C3-MINI-1_V1(2)_PCB_ ESP32-C3-MINI-1_V1
uid__4-36^DesignRootModel_PCB_ESP32-C3-MINI-1_V1(2)_PCB_ ESP32-C3-MINI-1_V1
uid__4-37^DesignRootModel_PCB_ESP32-C3-MINI-1_V1(2)_PCB_ ESP32-C3-MINI-1_V1
uid__4-38^DesignRootModel_PCB_ESP32-C3-MINI-1_V1(2)_PCB_ ESP32-C3-MINI-1_V1
uid__4-39^DesignRootModel_PCB_ESP32-C3-MINI-1_V1(2)_PCB_ ESP32-C3-MINI-1_V1
uid__4-40^DesignRootModel_PCB_ESP32-C3-MINI-1_V1(2)_PCB_ ESP32-C3-MINI-1_V1
uid__4-41^DesignRootModel_PCB_ESP32-C3-MINI-1_V1(2)_PCB_ ESP32-C3-MINI-1_V1
uid__4-42^DesignRootModel_PCB_ESP32-C3-MINI-1_V1(2)_PCB_ ESP32-C3-MINI-1_V1
uid__4-43^DesignRootModel_PCB_ESP32-C3-MINI-1_V1(2)_PCB_ ESP32-C3-MINI-1_V1
uid__4-44^DesignRootModel_PCB_ESP32-C3-MINI-1_V1(2)_PCB_ ESP32-C3-MINI-1_V1
uid__4-45^DesignRootModel_PCB_ESP32-C3-MINI-1_V1(2)_PCB_ ESP32-C3-MINI-1_V1
uid__4-46^DesignRootModel_PCB_ESP32-C3-MINI-1_V1(2)_PCB_ ESP32-C3-MINI-1_V1
uid__4-47^DesignRootModel_PCB_ESP32-C3-MINI-1_V1(2)_PCB_ ESP32-C3-MINI-1_V1
uid__4-48^DesignRootModel_PCB_ESP32-C3-MINI-1_V1(2)_PCB_ ESP32-C3-MINI-1_V1
uid__4-49^DesignRootModel_PCB_ESP32-C3-MINI-1_V1(2)_PCB_ ESP32-C3-MINI-1_V1
uid__4-50^DesignRootModel_PCB_ESP32-C3-MINI-1_V1(2)_PCB_ ESP32-C3-MINI-1_V1
uid__4-51^DesignRootModel_PCB_ESP32-C3-MINI-1_V1(2)_PCB_ ESP32-C3-MINI-1_V1
uid__4-52^DesignRootModel_PCB_ESP32-C3-MINI-1_V1(2)_PCB_ ESP32-C3-MINI-1_V1
uid__4-53^DesignRootModel_PCB_ESP32-C3-MINI-1_V1(2)_PCB_ ESP32-C3-MINI-1_V1
uid__4-54^DesignRootModel_PCB_ESP32-C3-MINI-1_V1(2)_PCB_ ESP32-C3-MINI-1_V1
uid__4-55^DesignRootModel_PCB_ESP32-C3-MINI-1_V1(2)_PCB_ ESP32-C3-MINI-1_V1
uid__4-56^DesignRootModel_PCB_ESP32-C3-MINI-1_V1(2)_PCB_ ESP32-C3-MINI-1_V1
uid__4-57^DesignRootModel_PCB_ESP32-C3-MINI-1_V1(2)_PCB_ ESP32-C3-MINI-1_V1
uid__4-58^DesignRootModel_PCB_ESP32-C3-MINI-1_V1(2)_PCB_ ESP32-C3-MINI-1_V1
uid__4-59^DesignRootModel_PCB_ESP32-C3-MINI-1_V1(2)_PCB_ ESP32-C3-MINI-1_V1
uid__4-60^DesignRootModel_PCB_ESP32-C3-MINI-1_V1(2)_PCB_ ESP32-C3-MINI-1_V1
uid__4-61^DesignRootModel_PCB_ESP32-C3-MINI-1_V1(2)_PCB_ ESP32-C3-MINI-1_V1
uid__4-62^DesignRootModel_PCB_ESP32-C3-MINI-1_V1(2)_PCB_ ESP32-C3-MINI-1_V1
uid__4-63^DesignRootModel_PCB_ESP32-C3-MINI-1_V1(2)_PCB_ ESP32-C3-MINI-1_V1
uid__4-64^DesignRootModel_PCB_ESP32-C3-MINI-1_V1(2)_PCB_ ESP32-C3-MINI-1_V1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

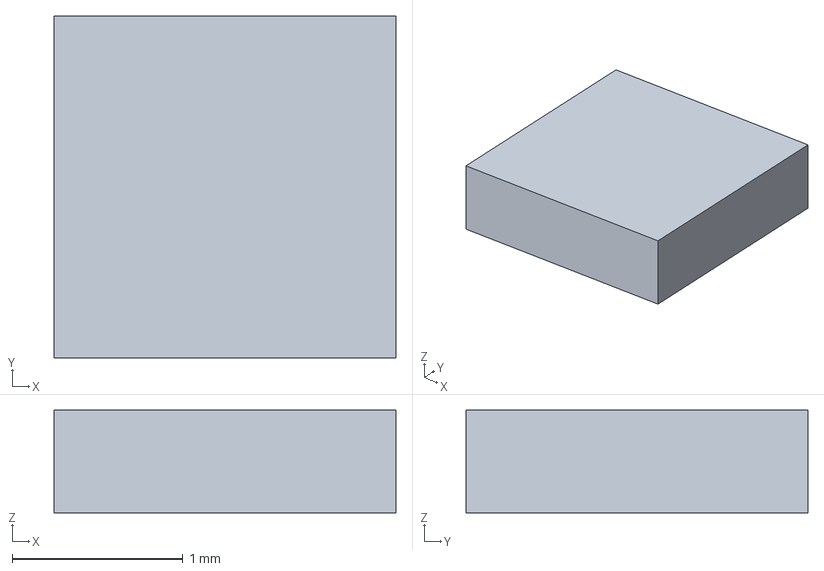
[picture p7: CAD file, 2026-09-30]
hardware/portrait/enclosure/output/reference_RearFoam_4.step
2.00 x 2.00 x 0.6 mm

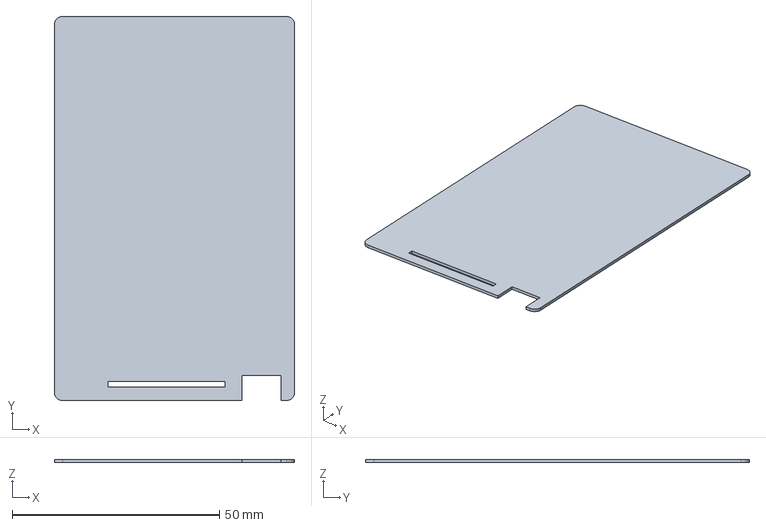
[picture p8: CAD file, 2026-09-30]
hardware/portrait/enclosure/output/reference_pcb_placeholder.step
58.0 x 92.6 x 0.8 mm

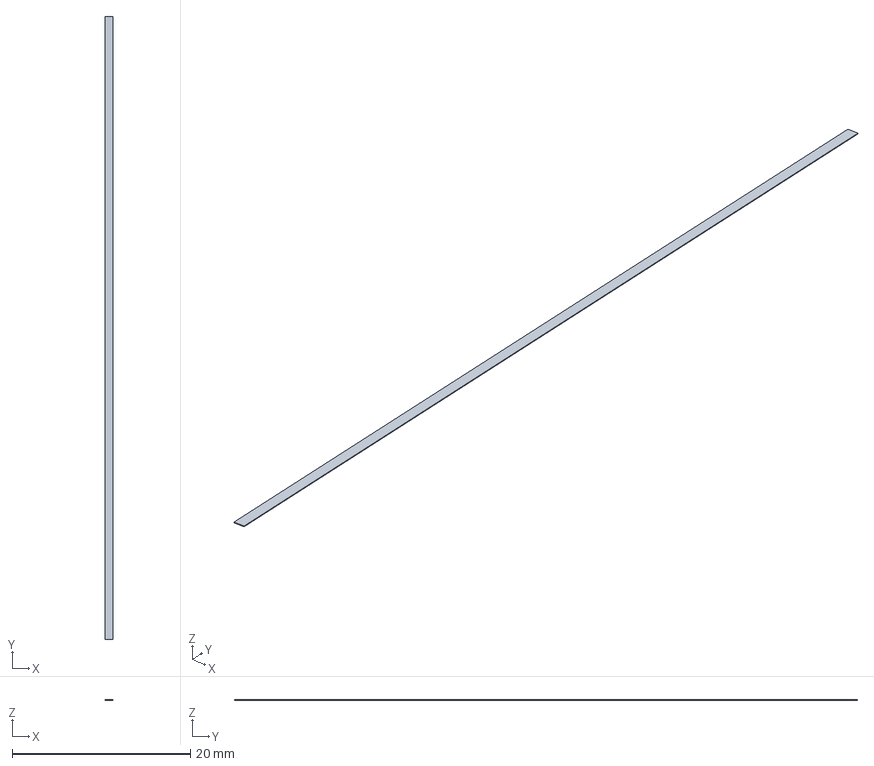
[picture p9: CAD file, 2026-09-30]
hardware/portrait/enclosure/output/reference_FrontPSA_Left.step
0.9 x 70.0 x 0.06 mm

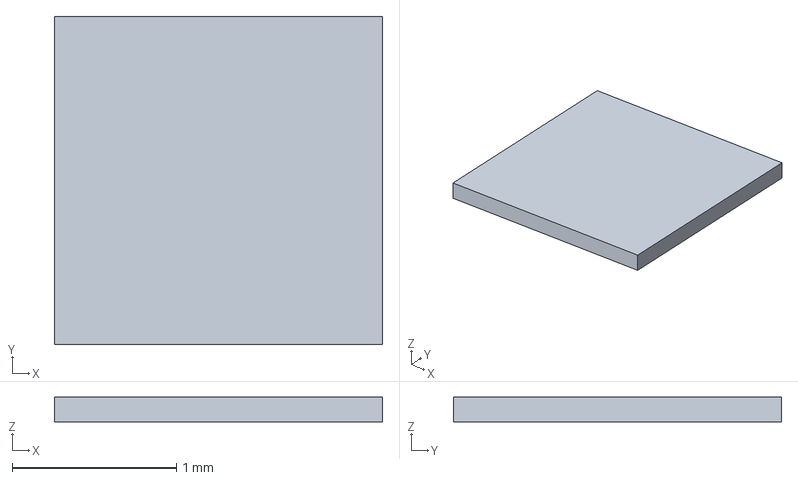
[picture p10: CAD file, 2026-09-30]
hardware/portrait/enclosure/output/reference_RearPET_2.step
2.00 x 2.00 x 0.15 mm

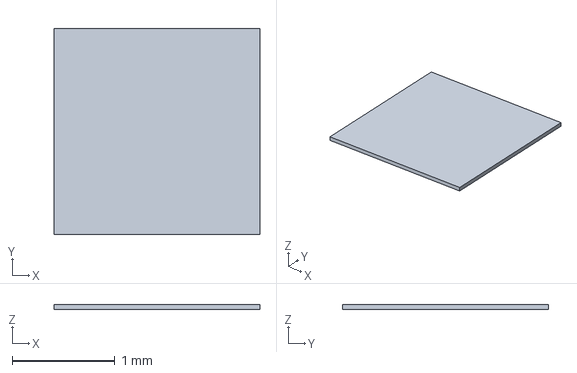
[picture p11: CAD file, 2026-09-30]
hardware/portrait/enclosure/output/reference_RearFoamPSA_4.step
2.00 x 2.00 x 0.05 mm

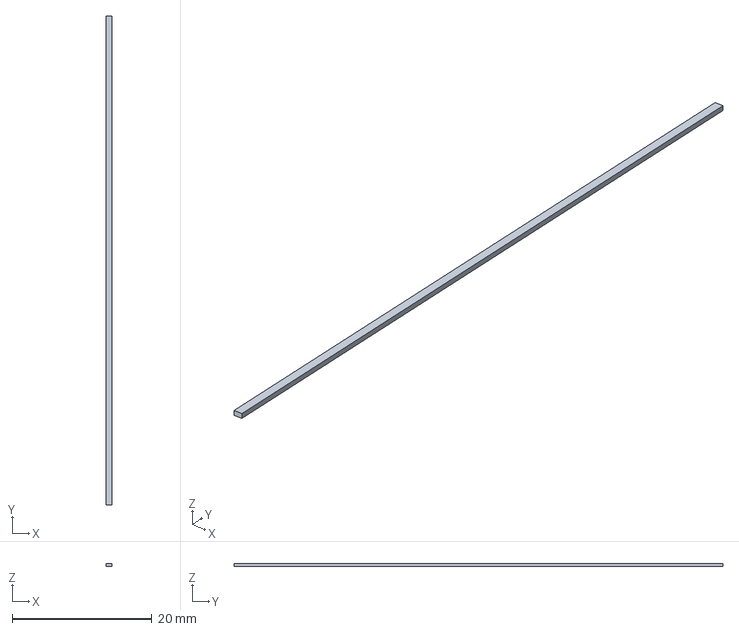
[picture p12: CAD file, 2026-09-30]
hardware/portrait/enclosure/output/reference_FrontFoam_Left.step
0.9 x 70.0 x 0.5 mm

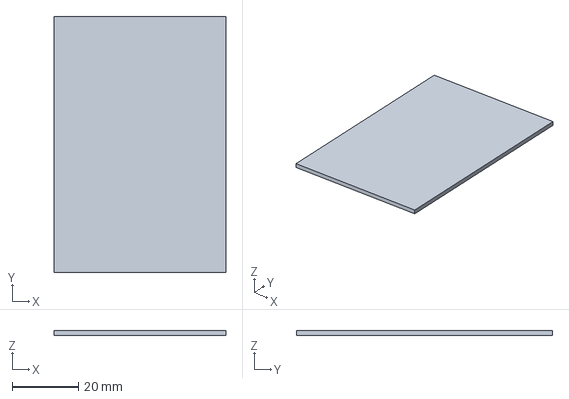
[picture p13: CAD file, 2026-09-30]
hardware/portrait/enclosure/output/reference_aa_no_press_audit.step
51.8 x 77.2 x 1.50 mm

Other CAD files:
hardware/portrait/enclosure/output/portrait_assembly_with_envelopes.step
hardware/portrait/enclosure/output/reference_RearPostPSA_2.step
hardware/portrait/enclosure/output/reference_RearFoam_3.step
hardware/portrait/enclosure/output/reference_RearFoam_2.step
hardware/portrait/enclosure/output/reference_RearFoamPSA_1.step
hardware/portrait/enclosure/output/reference_FrontPSA_Right.step
hardware/portrait/enclosure/output/pcb_board_body.step
hardware/portrait/enclosure/output/pcb_copper_audit.step
hardware/portrait/enclosure/output/portrait_back_cover.step
hardware/portrait/enclosure/output/portrait_back_cover.stl
hardware/portrait/enclosure/output/portrait_front_frame.stl
hardware/portrait/enclosure/output/reference_FrontFoam_Right.step
hardware/portrait/enclosure/output/reference_FrontFoam_Top.step
hardware/portrait/enclosure/output/reference_FrontPSA_Top.step
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

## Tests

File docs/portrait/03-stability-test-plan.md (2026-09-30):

# 首件稳定性验收计划（尚未实测）

当前电脑测试结果见START_HERE.md，以下是将来实物验收要求，不是已通过记录。

1. 先解决assembly_review_gates.json的PH/SW3和FPC/C118–121空间阻断；来料核电池、PH极性、USB厚度、FPC pin1和锁扣，再制作试装量规。
2. 无屏限流上电，核短路、USB识别、3V3、100mA充电和load-share；测电池与密闭壳温升。两线无NTC，禁止把芯片温控当电芯温控。
3. 断电插屏，核官方波形、BUSY低忙/高就绪、双10uH boost轨峰值/纹波/有效电容、MOS/二极管/采样电阻和电感热应力。
4. 测六色、方向、四角、细字、二维码quiet zone、温区刷新时长；SPI只写没有物理ACK，驱动返回不是画面验收。
5. 满电/低电/USB切换/WiFi与刷新峰值测VBAT和3V3，校准电池3.6V与VBUS ADC阈值及睡眠电流，不凭编译RAM估运行堆余量。
6. 手机iOS/Android实际浏览器和USB实测短包、超长、CRC/色码错、并发、取消、超时、重试、热点过期和设备重启。断电后EMPTY且可重新上传；当前没有Flash图像持久化/旧RAM回滚承诺。
7. 记录真实一次刷新能量和待机电流，注明板号、批次、温度、仪器、采样；无数据不写续航天数。
8. 测玻璃夹持区/胶相容、实际前间隙0.10–0.25、后泡棉压缩20–30%、侧游隙含偏转、回流平整度、按键间隙0.10–0.20及力/行程/寿命、挂绳拉力、螺钉扭矩和跌落；不靠螺钉强压玻璃。
9. NFC需先确定公司系统、取得合法发行凭证，再设计内部安装与天线隔离，并比较裸凭证/整机、满电/更新/低电、距离/偏角重复读卡。现阶段没有NFC功能测试通过。

放行必须同时满足采购规格/追溯、全量EDA审阅、软件编译与故障注入、空间冲突闭合、首件尺寸/电源/显示/热/RF/ESD/机械记录。禁止把源码评审包当生产包，不做破坏性电池试验。

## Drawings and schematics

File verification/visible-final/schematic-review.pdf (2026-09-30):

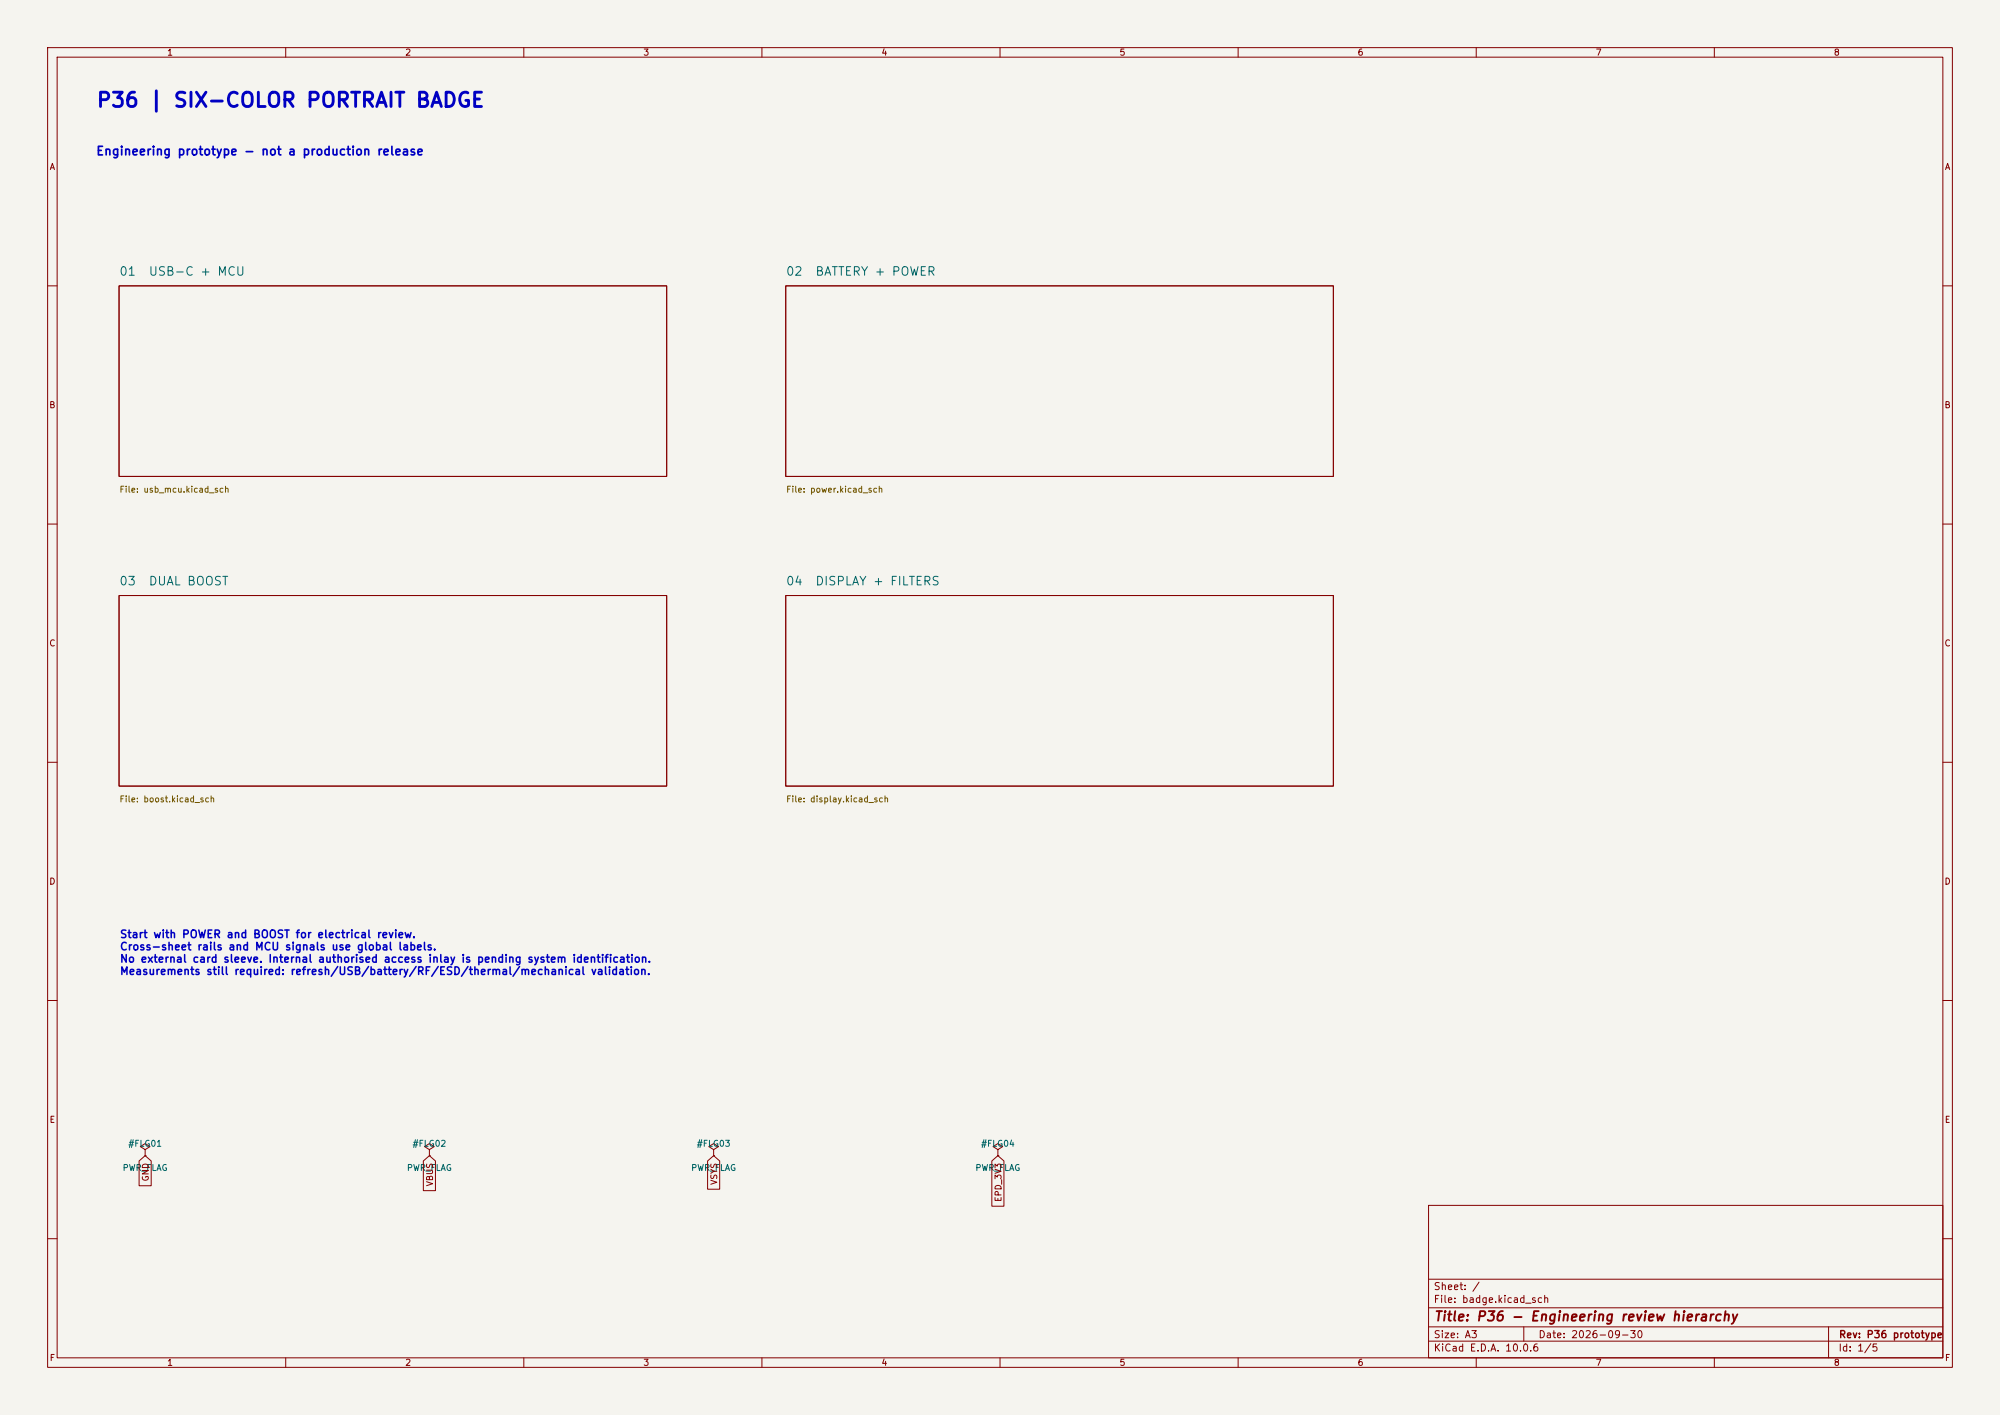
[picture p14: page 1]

P36 | SIX-COLOR PORTRAIT BADGE

Engineering prototype - not a production release

Start with POWER and BOOST for electrical review.
Cross-sheet rails and MCU signals use global labels.
No external card sleeve. Internal authorised access inlay is pending system identification.
Measurements still required: refresh/USB/battery/RF/ESD/thermal/mechanical validation.

Sheet: /
File: badge.kicad_sch
Title: P36 - Engineering review hierarchy

Size: A3 | Rev: P36 prototype | F Date: 2026-09-30
KiCad E.D.A. 10.0.6 | Id: 1/5

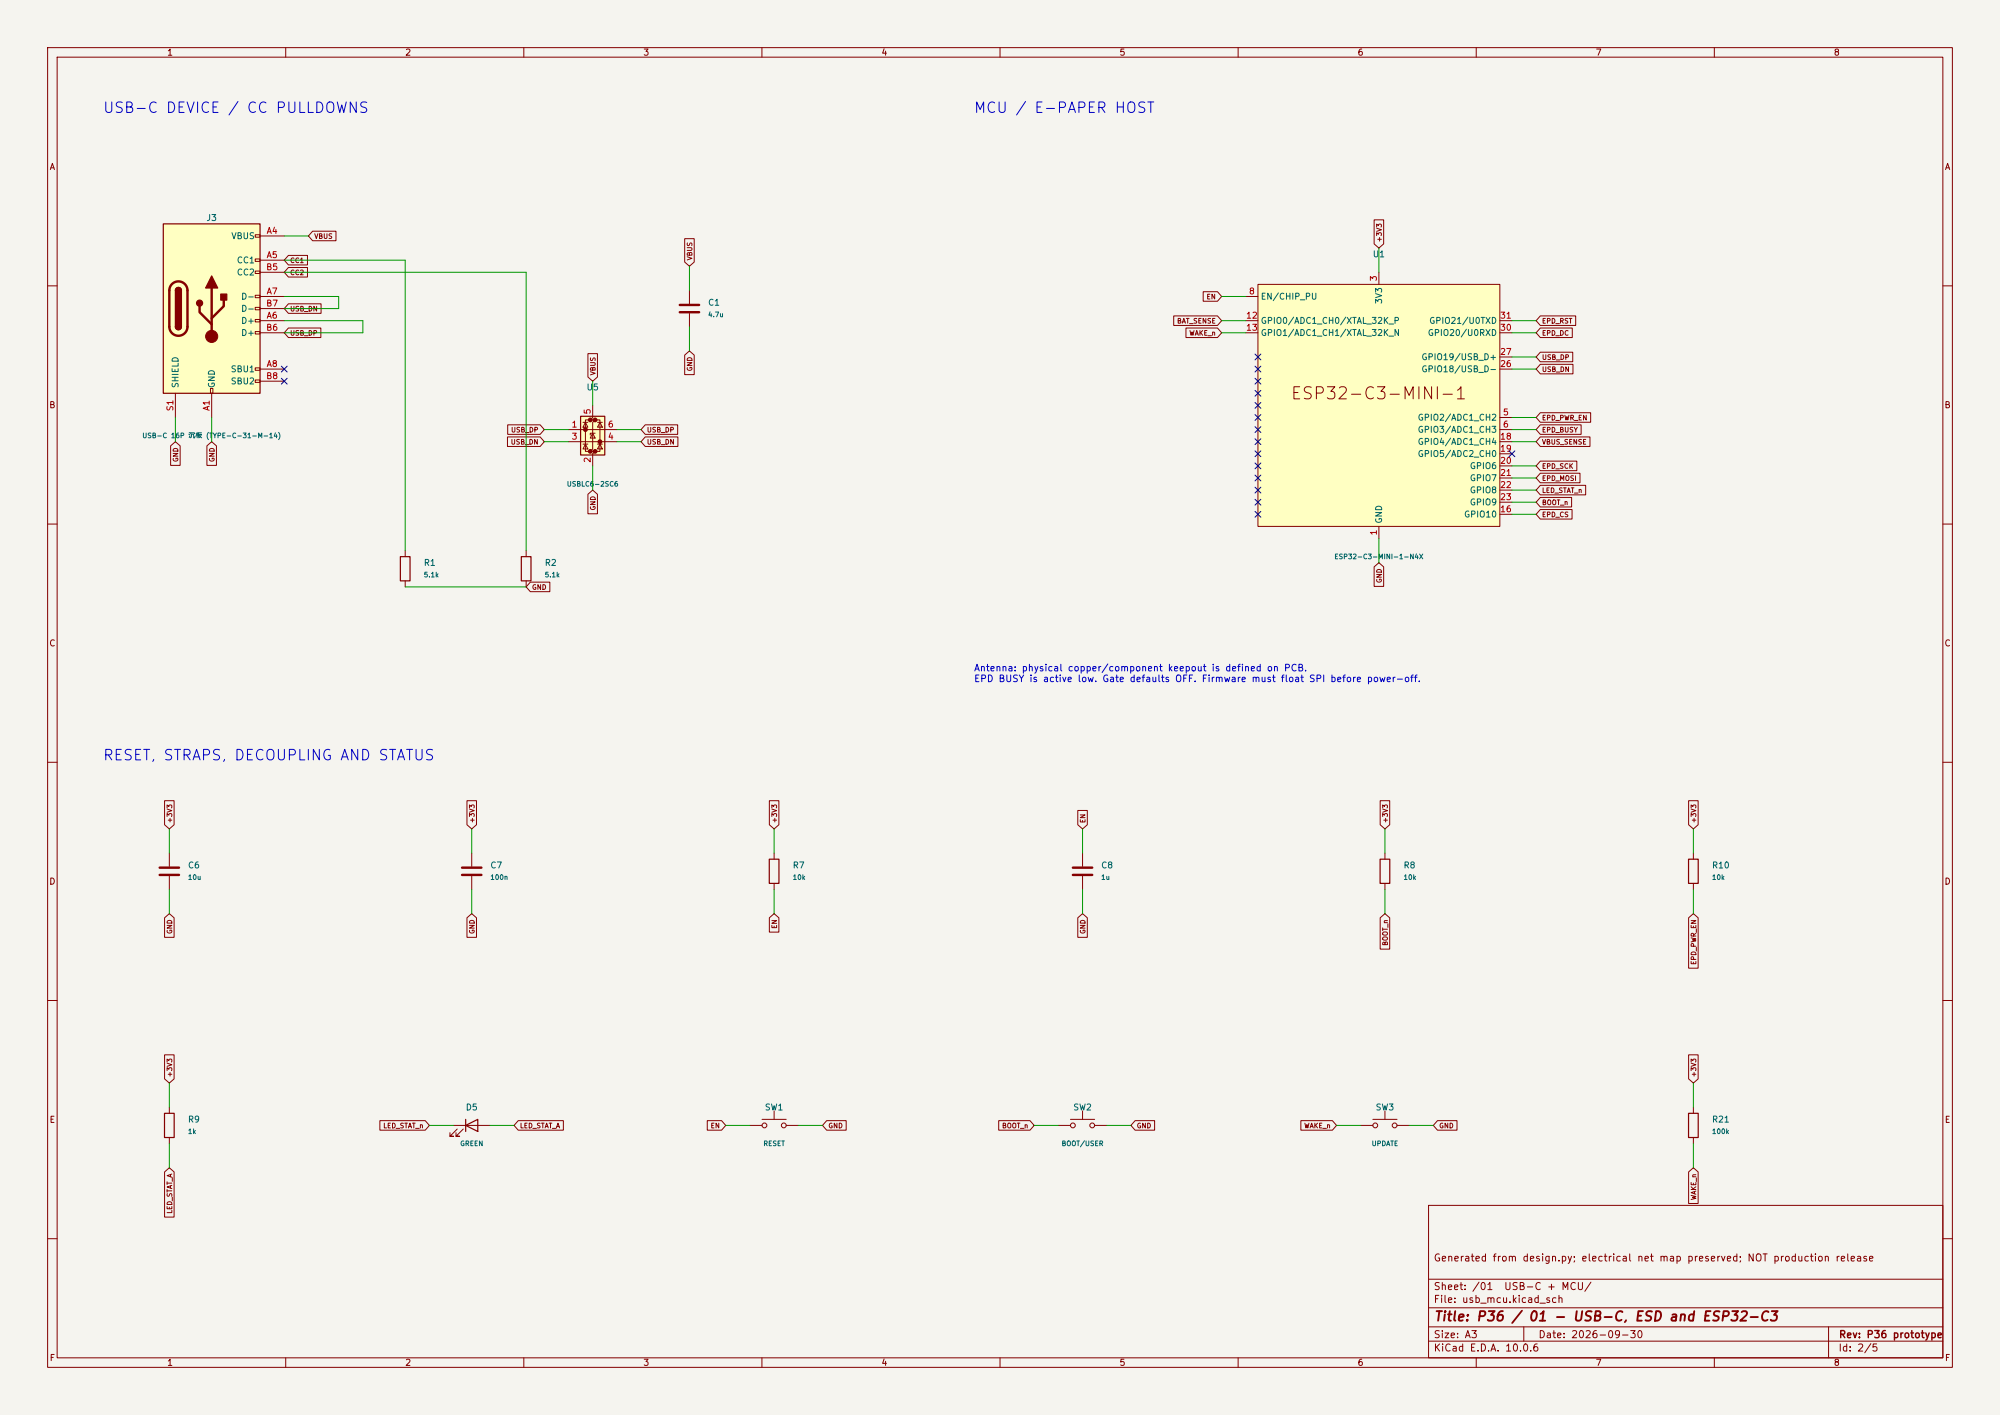
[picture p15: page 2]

VBUS_SENSE USB-C DEVICE / CC PULLDOWNS

Antenna: physical copper/component keepout is defined on PCB. EPD BUSY is active low. Gate defaults OFF. Firmware must float SPI before power-off.

RESET, STRAPS, DECOUPLING AND STATUS

Generated from design.py; electrical net map preserved; NOT production release

Sheet: /01 USB-C + MCU/
File: usb_mcu.kicad_sch
Title: P36 / 01 - USB-C, ESD and ESP32-C3

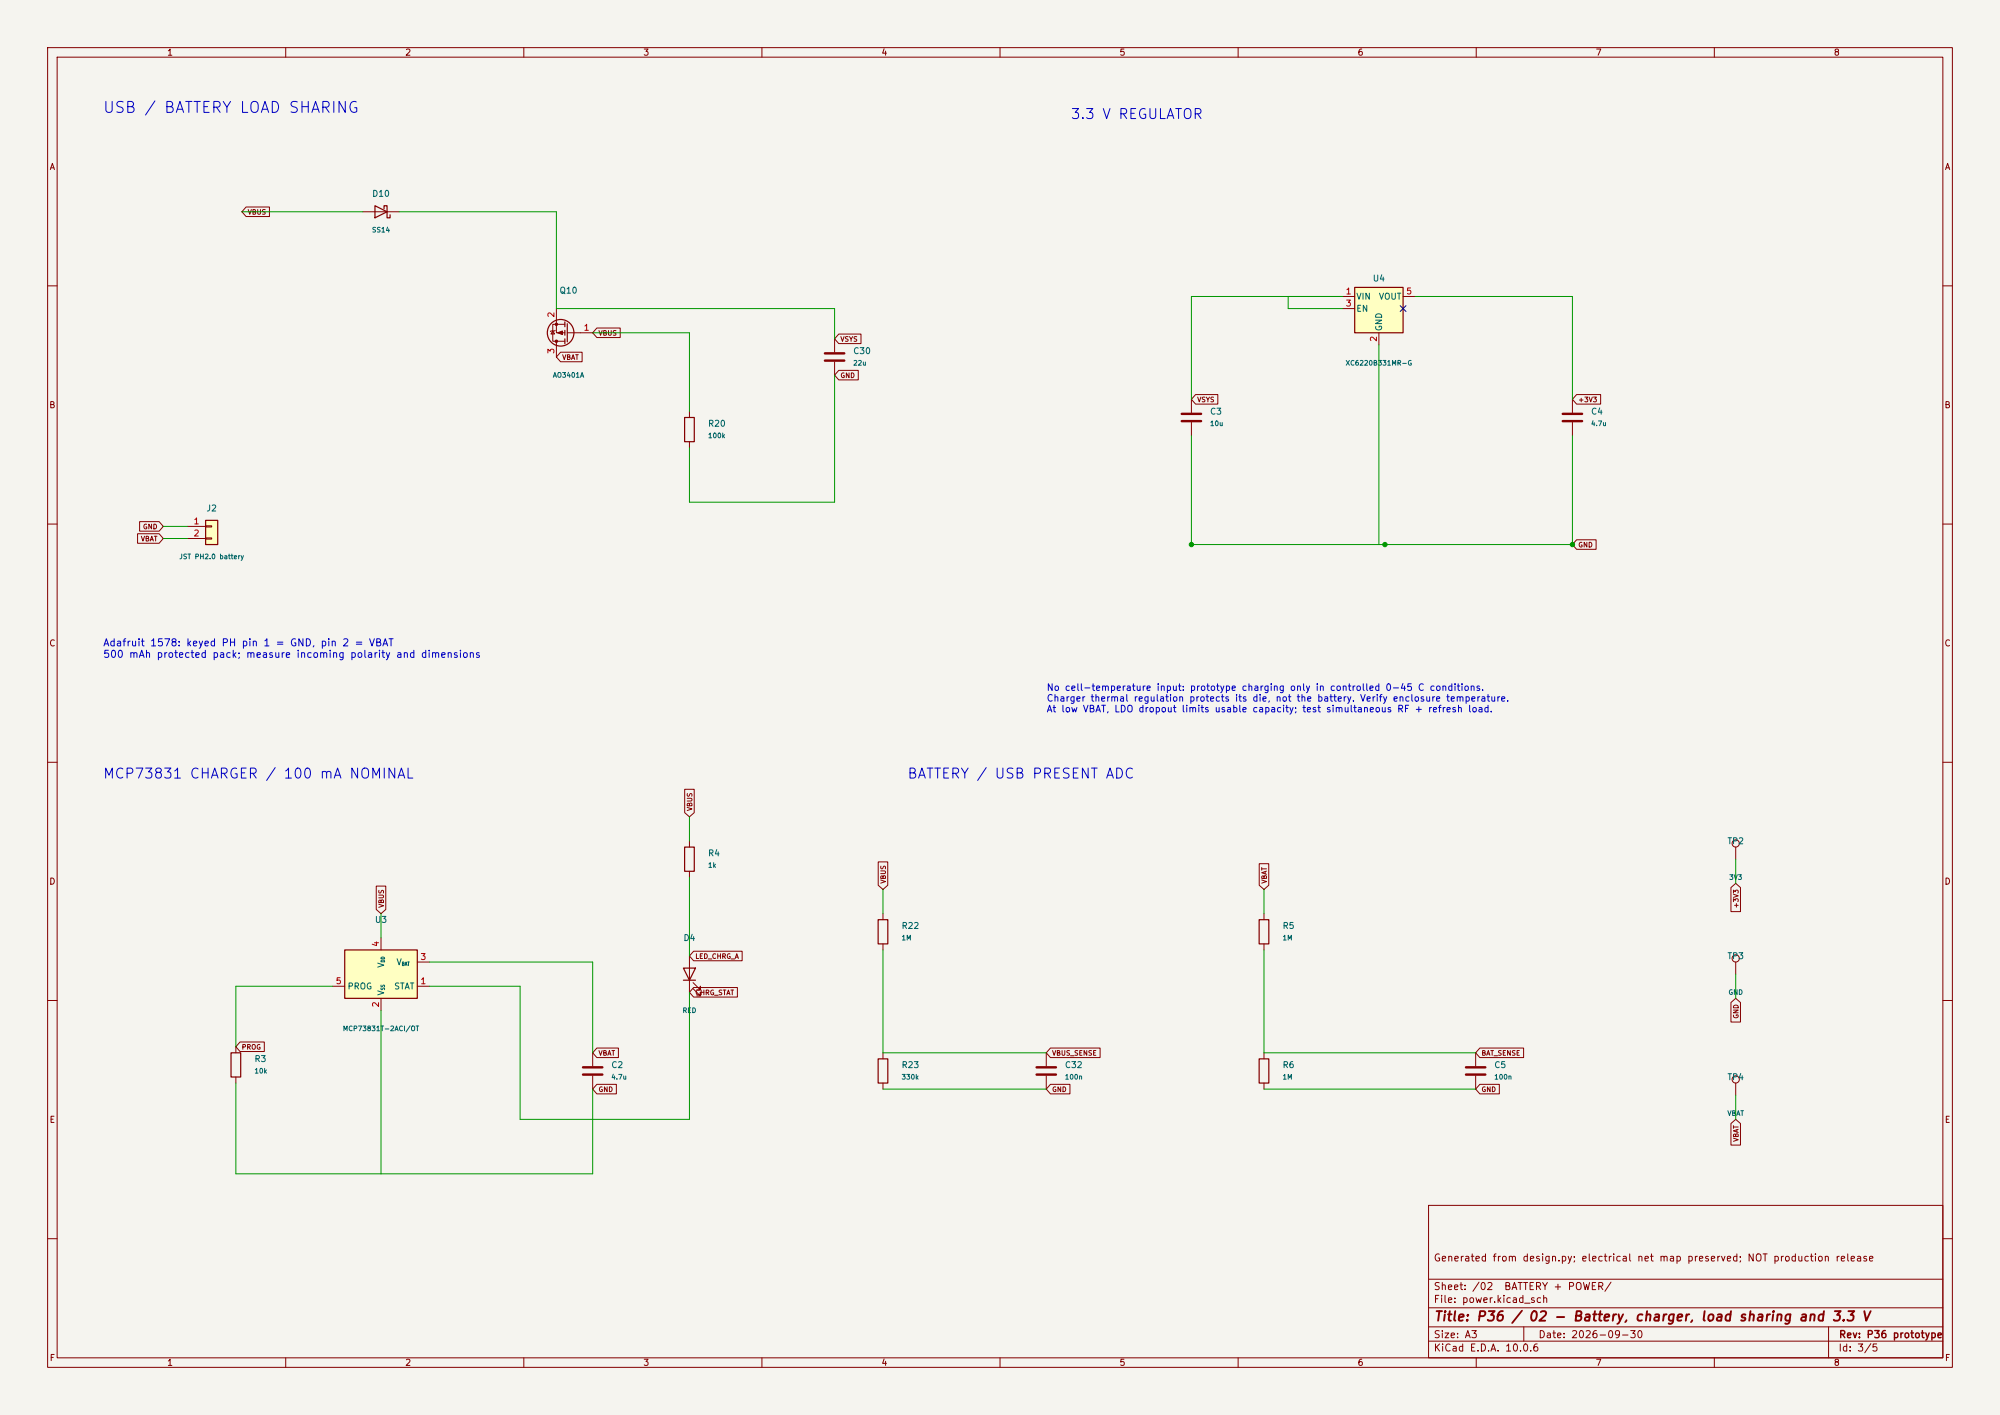
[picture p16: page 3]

Adafruit 1578: keyed PH pin 1 = GND, pin 2 = VBAT
500 mAh protected pack; measure incoming polarity and dimensions

No cell-temperature input: prototype charging only in controlled 0-45 C conditions. Charger thermal regulation protects its die, not the battery. Verify enclosure temperature. At low VBAT, LDO dropout limits usable capacity; test simultaneous RF + refresh load.

Generated from design.py; electrical net map preserved; NOT production release

Sheet: /02 BATTERY + POWER/
File: power.kicad_sch
Title: P36 / 02 - Battery, charger, load sharing and 3.3 V

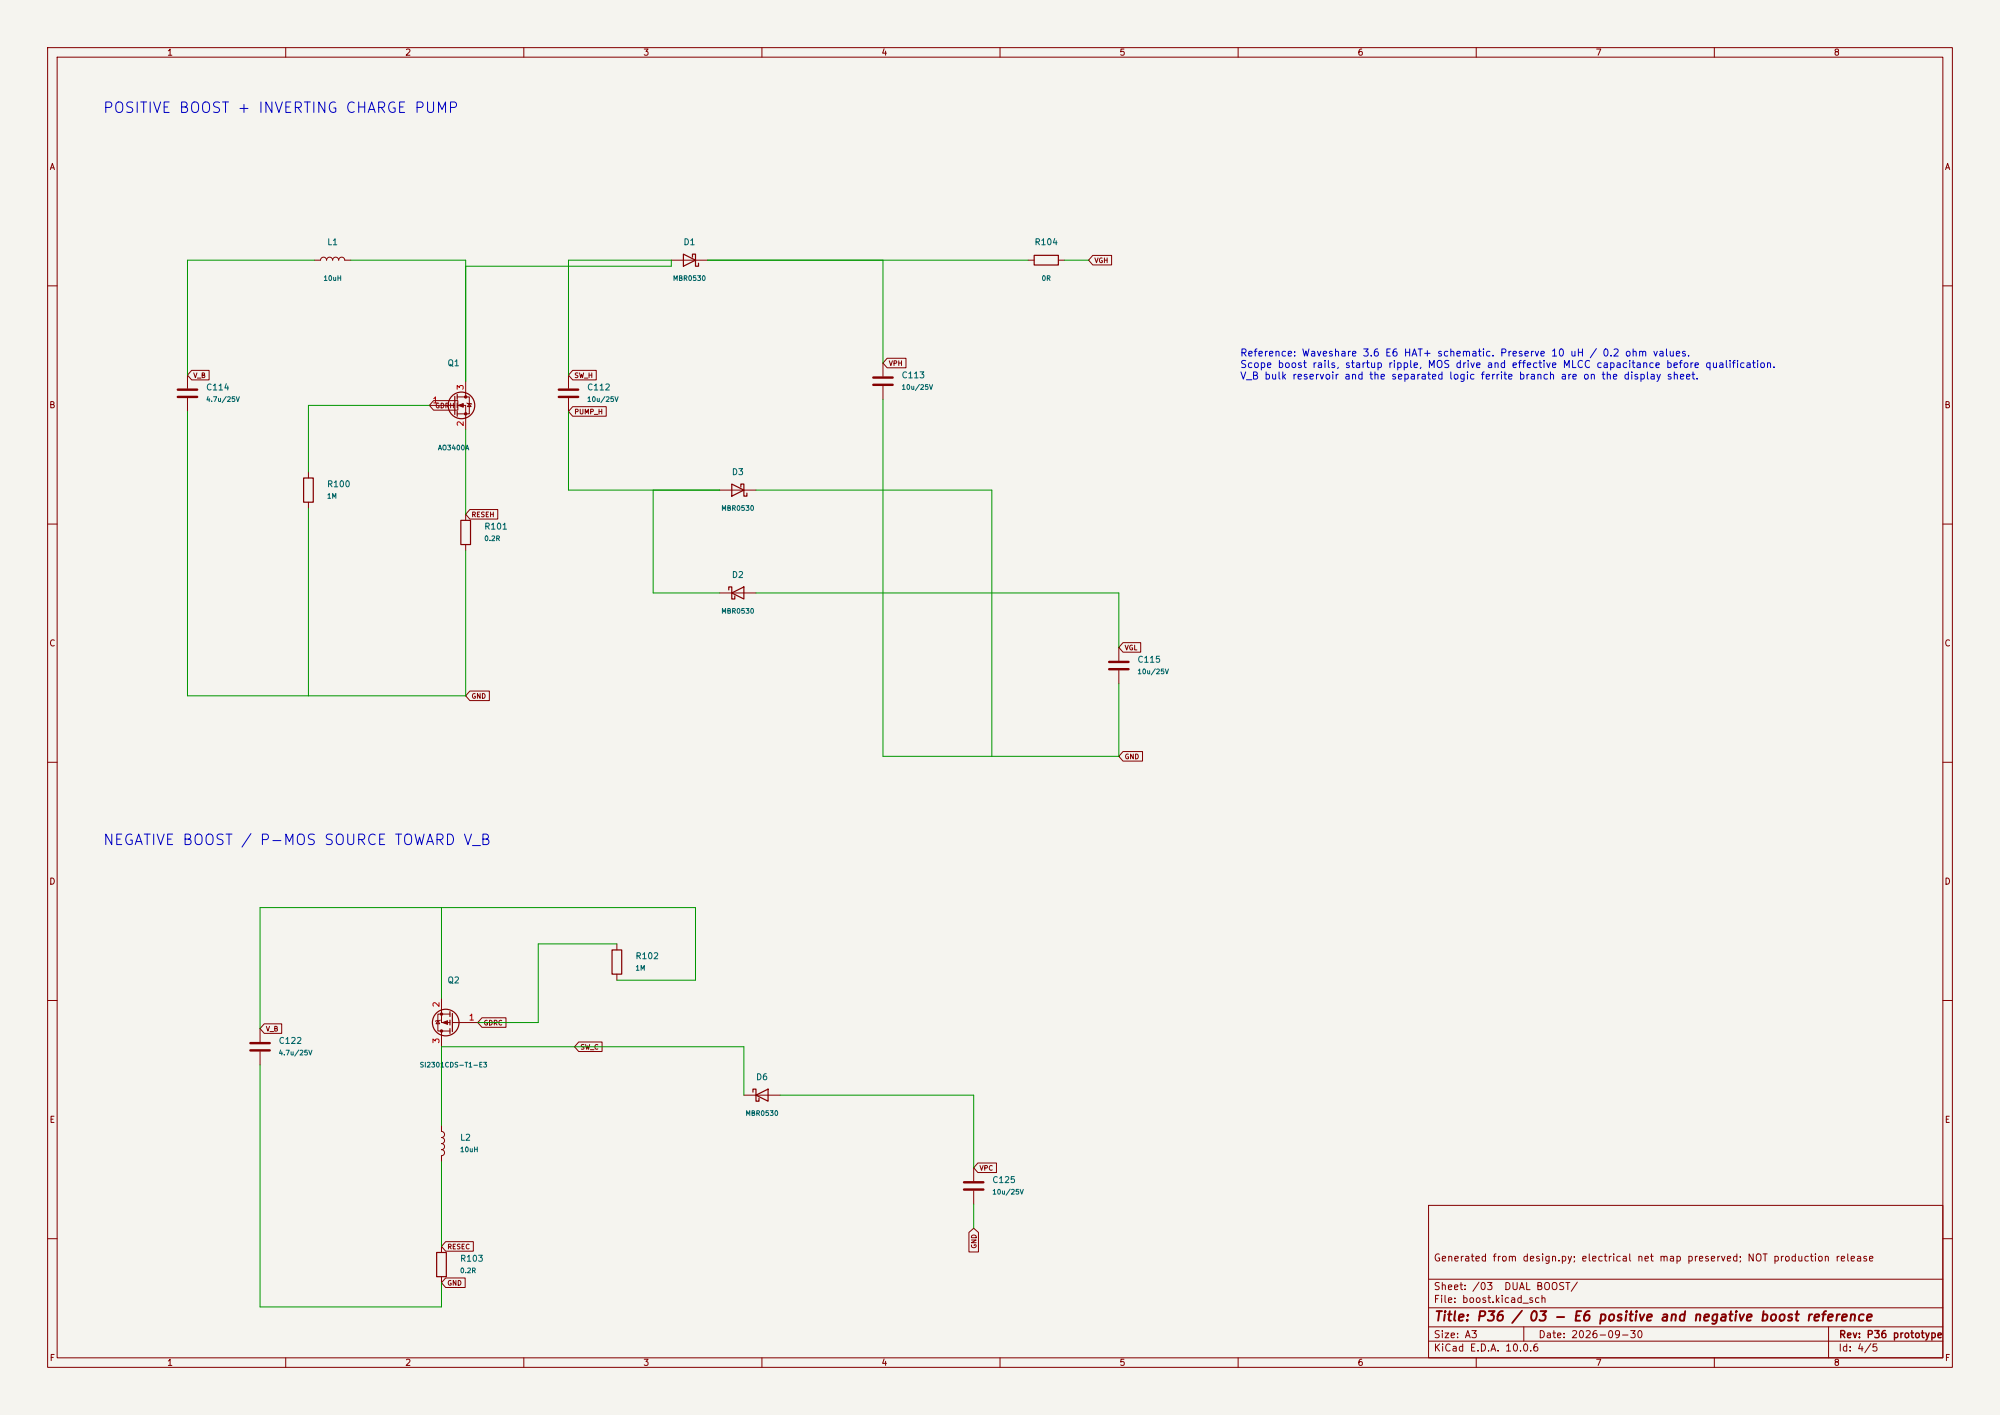
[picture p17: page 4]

POSITIVE BOOST + INVERTING CHARGE PUMP

Reference: Waveshare 3.6 E6 HAT+ schematic. Preserve 10 uH / 0.2 ohm values.
Scope boost rails, startup ripple, MOS drive and effective MLCC capacitance before qualification.
V_B bulk reservoir and the separated logic ferrite branch are on the display sheet.

NEGATIVE BOOST / P-MOS SOURCE TOWARD V_B

Generated from design.py; electrical net map preserved; NOT production release

Sheet: /03 DUAL BOOST/
File: boost.kicad_sch
Title: P36 / 03 - E6 positive and negative boost reference

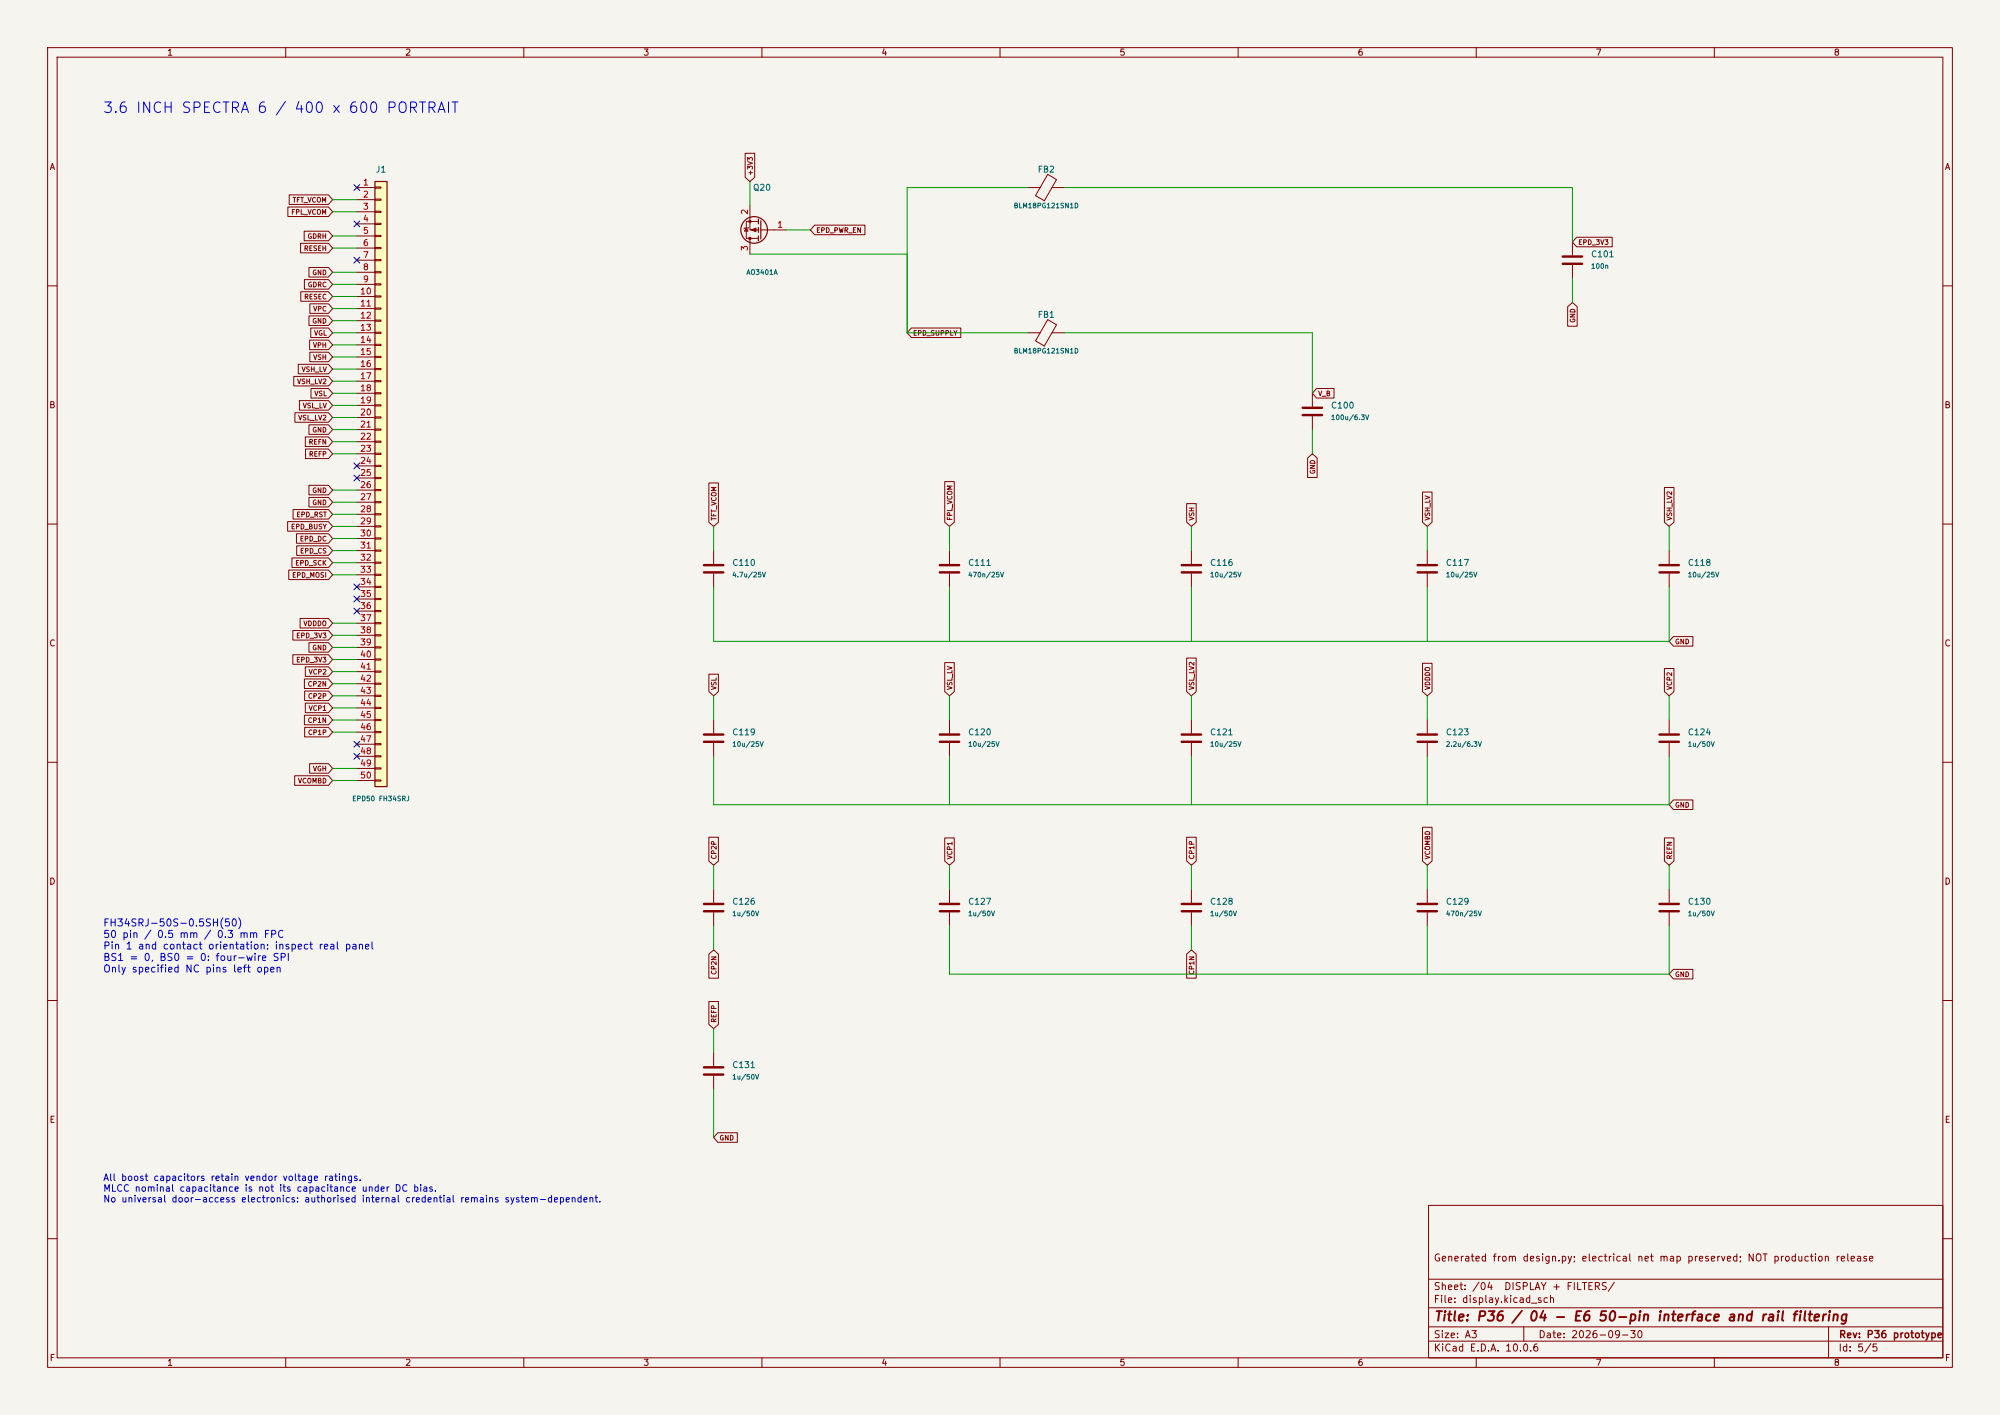
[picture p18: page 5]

FH34SRJ-50S-0.5SH(50)
50 pin / 0.5 mm / 0.3 mm FPC
Pin 1 and contact orientation: inspect real panel
BS1 = 0, BS0 = 0: four-wire SPI
Only specified NC pins left open

All boost capacitors retain vendor voltage ratings. MLCC nominal capacitance is not its capacitance under DC bias. No universal door-access electronics: authorised internal credential remains system-dependent.

Generated from design.py; electrical net map preserved; NOT production release

Sheet: /04 DISPLAY + FILTERS/
File: display.kicad_sch
Title: P36 / 04 - E6 50-pin interface and rail filtering

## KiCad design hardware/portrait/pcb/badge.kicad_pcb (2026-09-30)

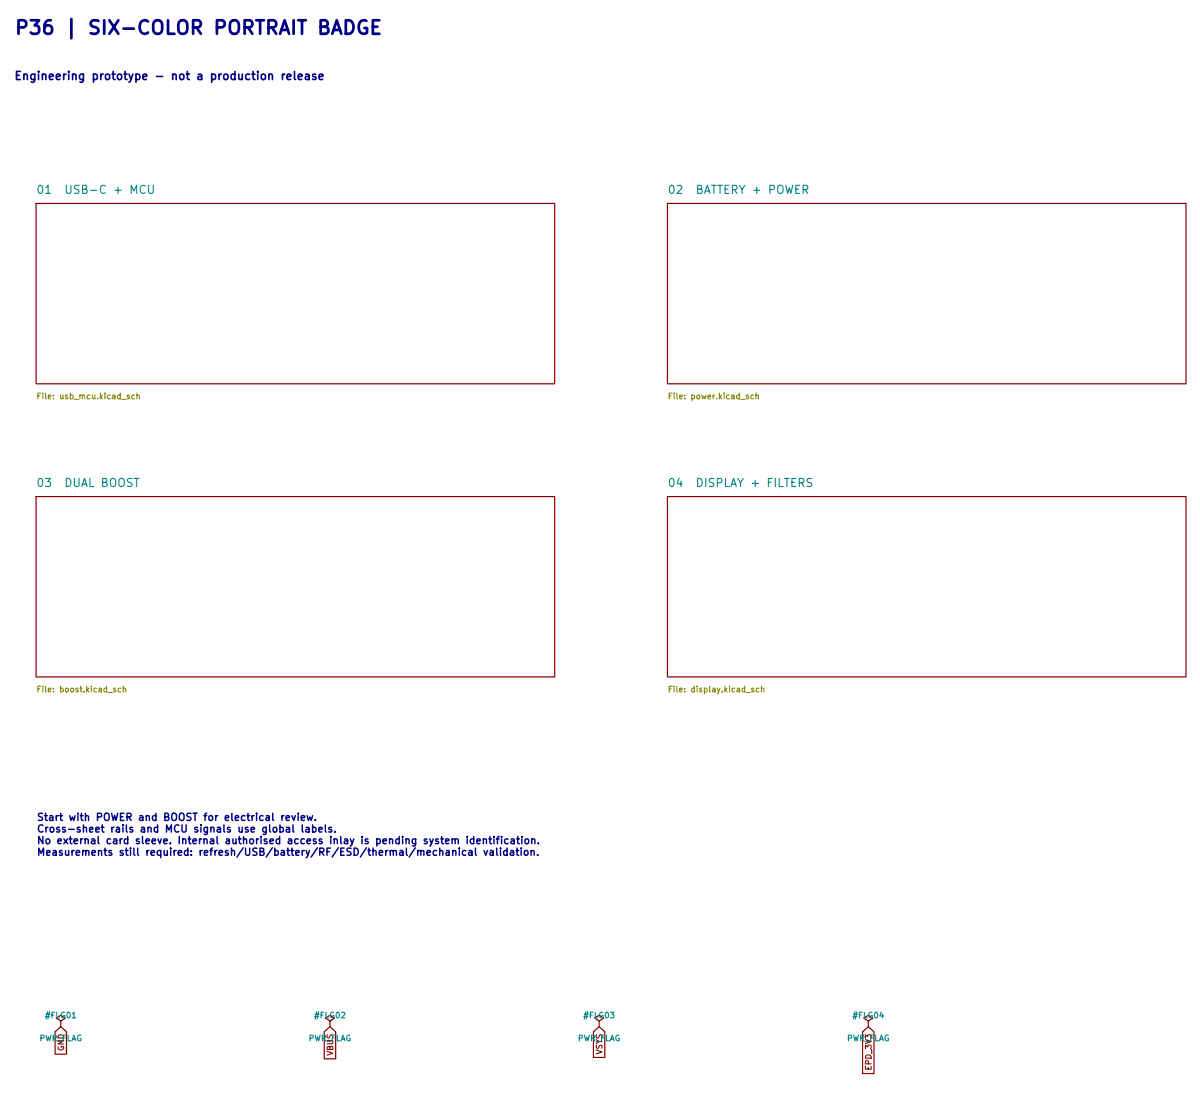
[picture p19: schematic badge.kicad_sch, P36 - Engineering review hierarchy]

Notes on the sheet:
P36 | SIX-COLOR PORTRAIT BADGE
Engineering prototype - not a production release
Start with POWER and BOOST for electrical review. Cross-sheet rails and MCU signals use global labels. No external card sleeve. Internal authorised access inlay is pending system identification. Measurements still required: refresh/USB/battery/RF/ESD/thermal/mechanical validation.

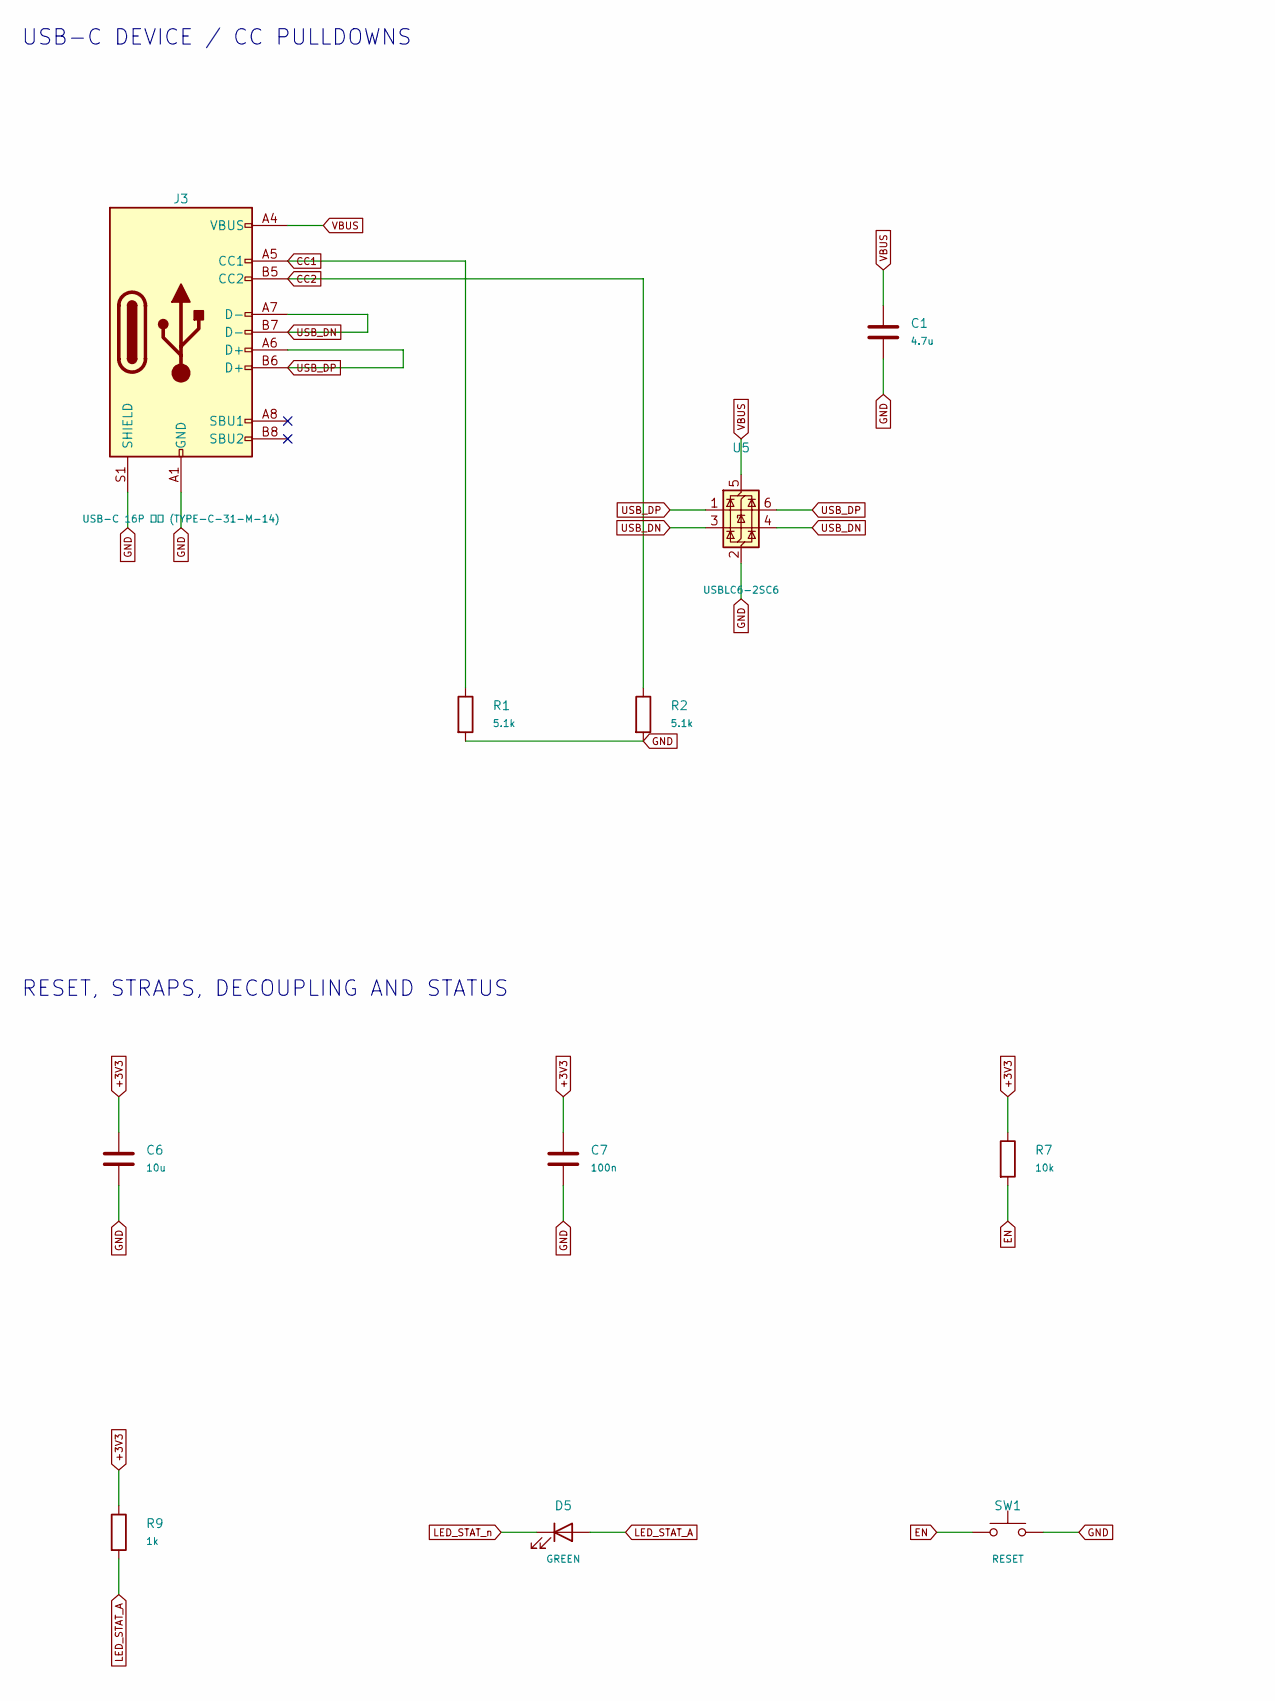
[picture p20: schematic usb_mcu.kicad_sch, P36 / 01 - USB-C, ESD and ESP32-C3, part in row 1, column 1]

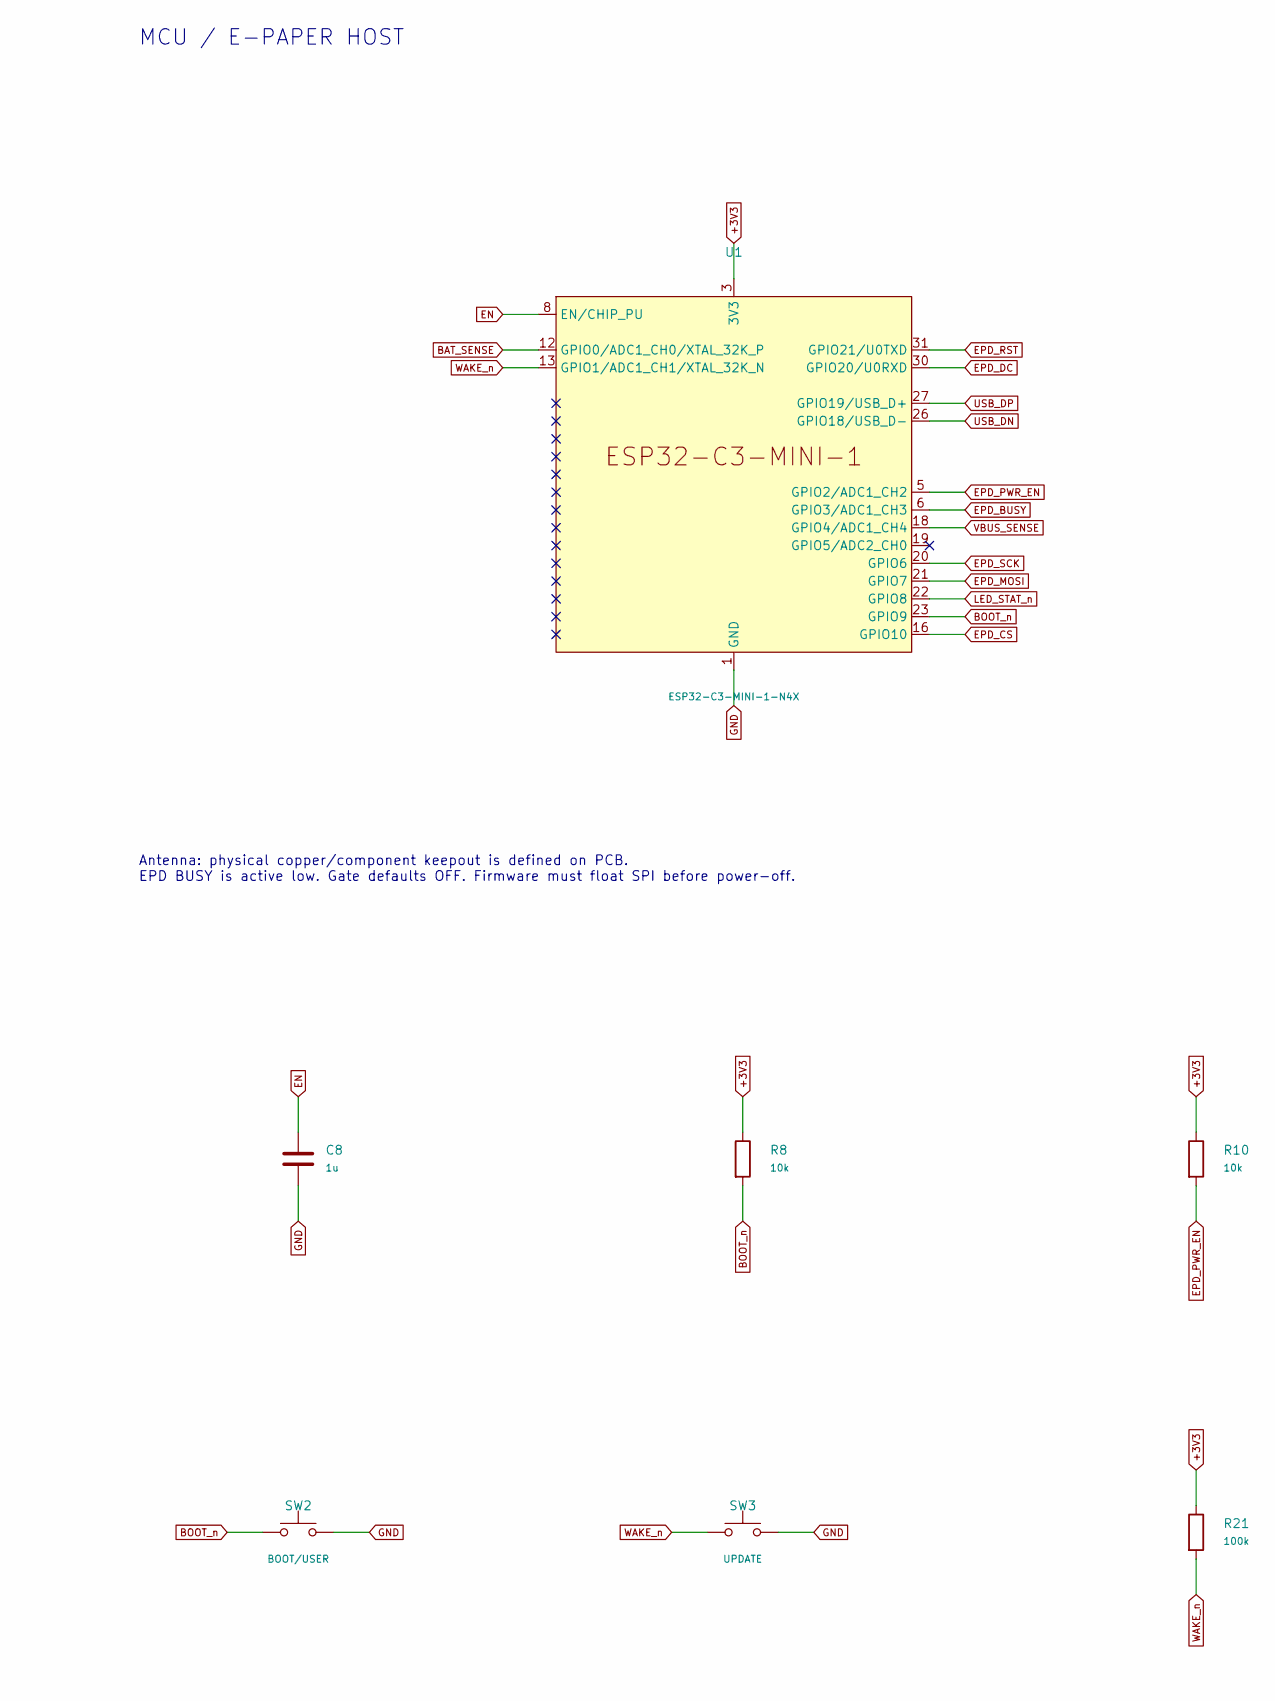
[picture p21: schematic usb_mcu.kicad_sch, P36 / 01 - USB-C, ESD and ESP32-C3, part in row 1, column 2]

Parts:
C1: 4.7u; C_0603_1608Metric
C6: 10u; C_0603_1608Metric
C7: 100n; C_0402_1005Metric
C8: 1u; C_0402_1005Metric
D5: GREEN; LED_0603_1608Metric
J3: USB-C 16P 沉板 (TYPE-C-31-M-14); TYPE-C-31-M-14; LCSC C223907
R1, R2: 5.1k; R_0402_1005Metric
R7, R8, R10: 10k; R_0402_1005Metric
R9: 1k; R_0402_1005Metric
R21: 100k; R_0402_1005Metric
SW1: RESET; SW_SPST_PTS810; LCSC C221929
SW2: BOOT/USER; SW_SPST_PTS810; LCSC C221929
SW3: UPDATE; SW_SPST_PTS810
U1: ESP32-C3-MINI-1-N4X; ESP32-C3-MINI-1
U5: USBLC6-2SC6; SOT-23-6

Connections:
+3V3: C6.1, C7.1, R7.1, R8.1, R9.1, R10.1, R21.1, U1.3 (3V3); also elsewhere on the board
BAT_SENSE: U1.12 (GPIO0/ADC1_CH0/XTAL_32K_P); also elsewhere on the board
BOOT_n: R8.2, SW2.1, U1.23 (GPIO9)
CC1: J3.A5 (CC1), R1.1
CC2: J3.B5 (CC2), R2.1
EN: C8.1, R7.2, SW1.1, U1.8 (EN/CHIP_PU)
EPD_BUSY: U1.6 (GPIO3/ADC1_CH3); also elsewhere on the board
EPD_CS: U1.16 (GPIO10); also elsewhere on the board
EPD_DC: U1.30 (GPIO20/U0RXD); also elsewhere on the board
EPD_MOSI: U1.21 (GPIO7); also elsewhere on the board
EPD_PWR_EN: R10.2, U1.5 (GPIO2/ADC1_CH2); also elsewhere on the board
EPD_RST: U1.31 (GPIO21/U0TXD); also elsewhere on the board
EPD_SCK: U1.20 (GPIO6); also elsewhere on the board
GND: C1.2, C6.2, C7.2, C8.2, J3.A1 (GND), J3.A12 (GND), J3.B1 (GND), J3.B12 (GND), J3.S1 (SHIELD), R1.2, R2.2, SW1.2, SW2.2, SW3.2, U1.1 (GND), U1.2 (GND), U1.11 (GND), U1.14 (GND), U1.36 (GND), U1.37 (GND), U1.38 (GND), U1.39 (GND), U1.40 (GND), U1.41 (GND), U1.42 (GND), U1.43 (GND), U1.44 (GND), U1.45 (GND), U1.46 (GND), U1.47 (GND), U1.48 (GND), U1.49 (GND), U1.50 (GND), U1.51 (GND), U1.52 (GND), U1.53 (GND), U5.2 (GND); also elsewhere on the board
LED_STAT_A: D5.2 (A), R9.2
LED_STAT_n: D5.1 (K), U1.22 (GPIO8)
USB_DN: J3.A7 (D-), J3.B7 (D-), U1.26 (GPIO18/USB_D-), U5.3 (I/O2), U5.4 (I/O2)
USB_DP: J3.A6 (D+), J3.B6 (D+), U1.27 (GPIO19/USB_D+), U5.1 (I/O1), U5.6 (I/O1)
VBUS: C1.1, J3.A4 (VBUS), J3.A9 (VBUS), J3.B4 (VBUS), J3.B9 (VBUS), U5.5 (VBUS); also elsewhere on the board
VBUS_SENSE: U1.18 (GPIO4/ADC1_CH4); also elsewhere on the board
WAKE_n: R21.2, SW3.1, U1.13 (GPIO1/ADC1_CH1/XTAL_32K_N)

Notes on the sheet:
USB-C DEVICE / CC PULLDOWNS
MCU / E-PAPER HOST
Antenna: physical copper/component keepout is defined on PCB. EPD BUSY is active low. Gate defaults OFF. Firmware must float SPI before power-off.
RESET, STRAPS, DECOUPLING AND STATUS

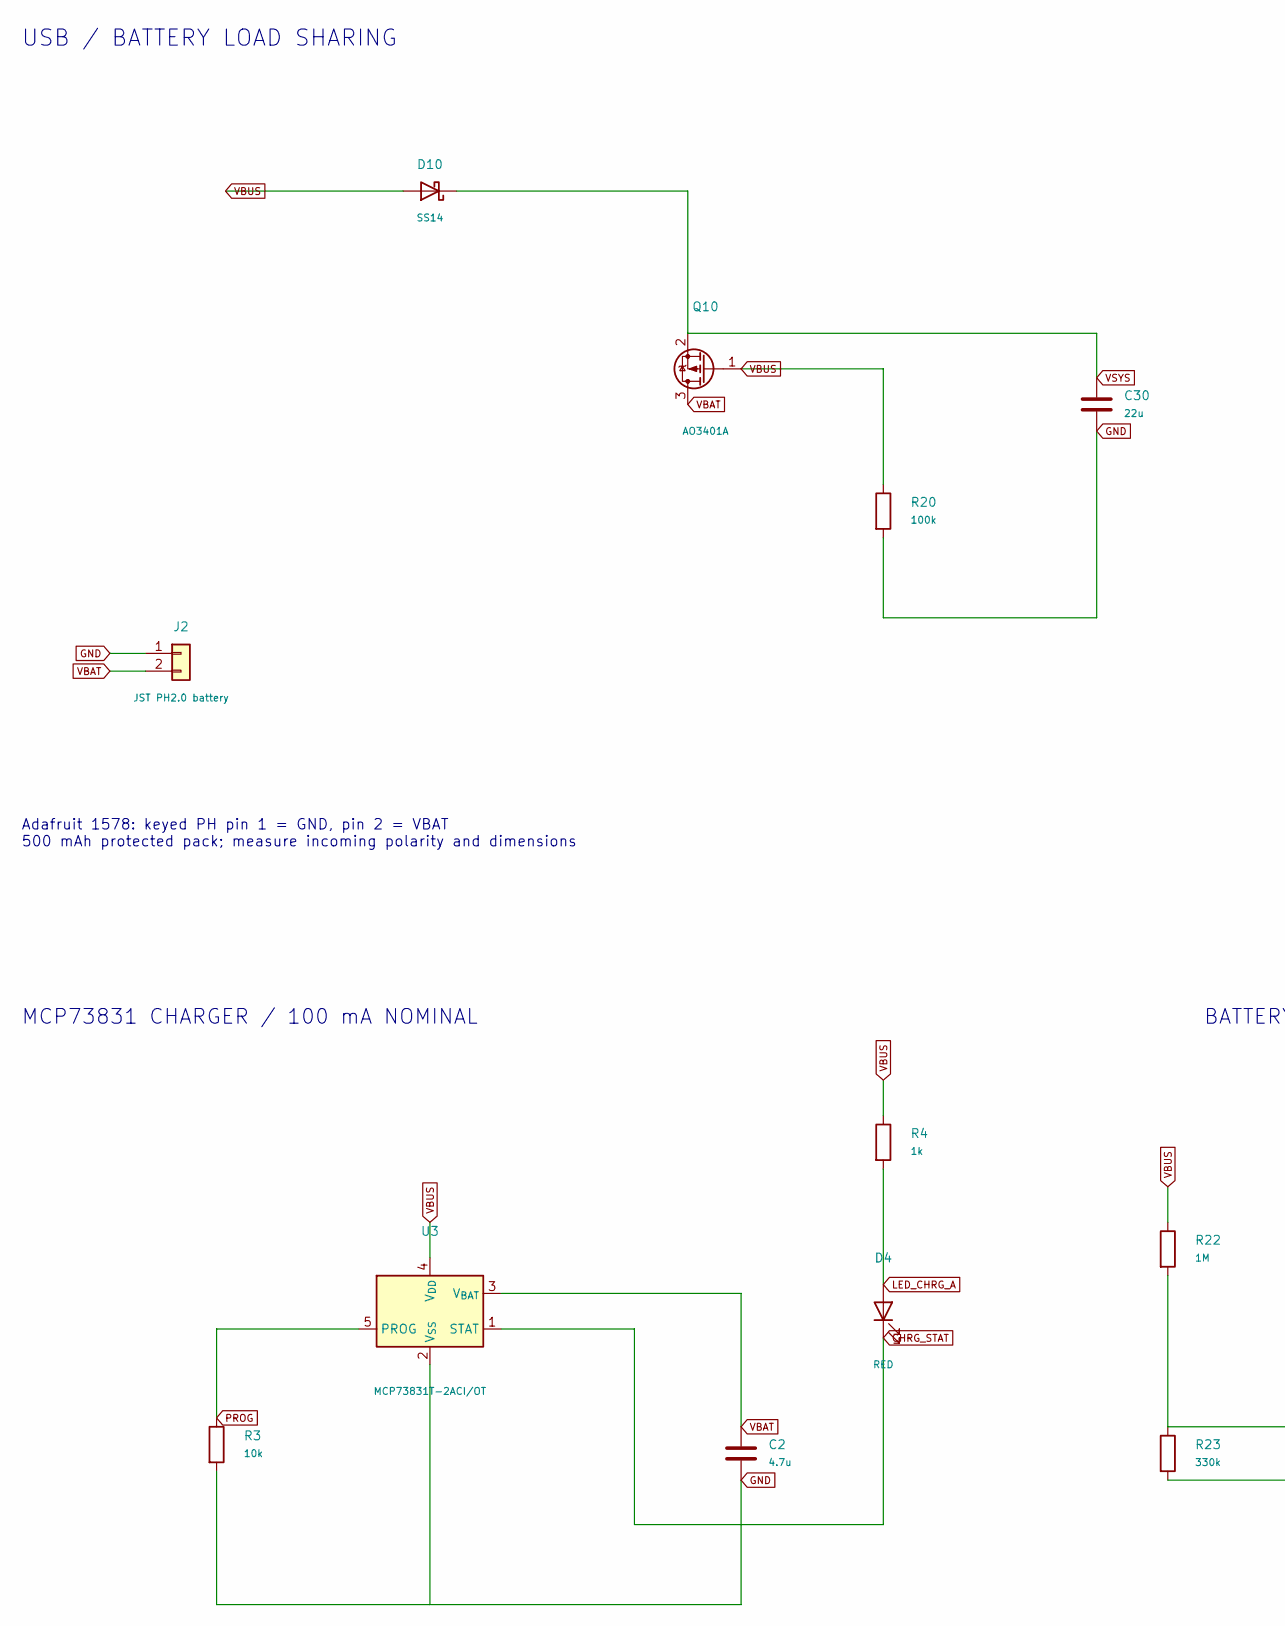
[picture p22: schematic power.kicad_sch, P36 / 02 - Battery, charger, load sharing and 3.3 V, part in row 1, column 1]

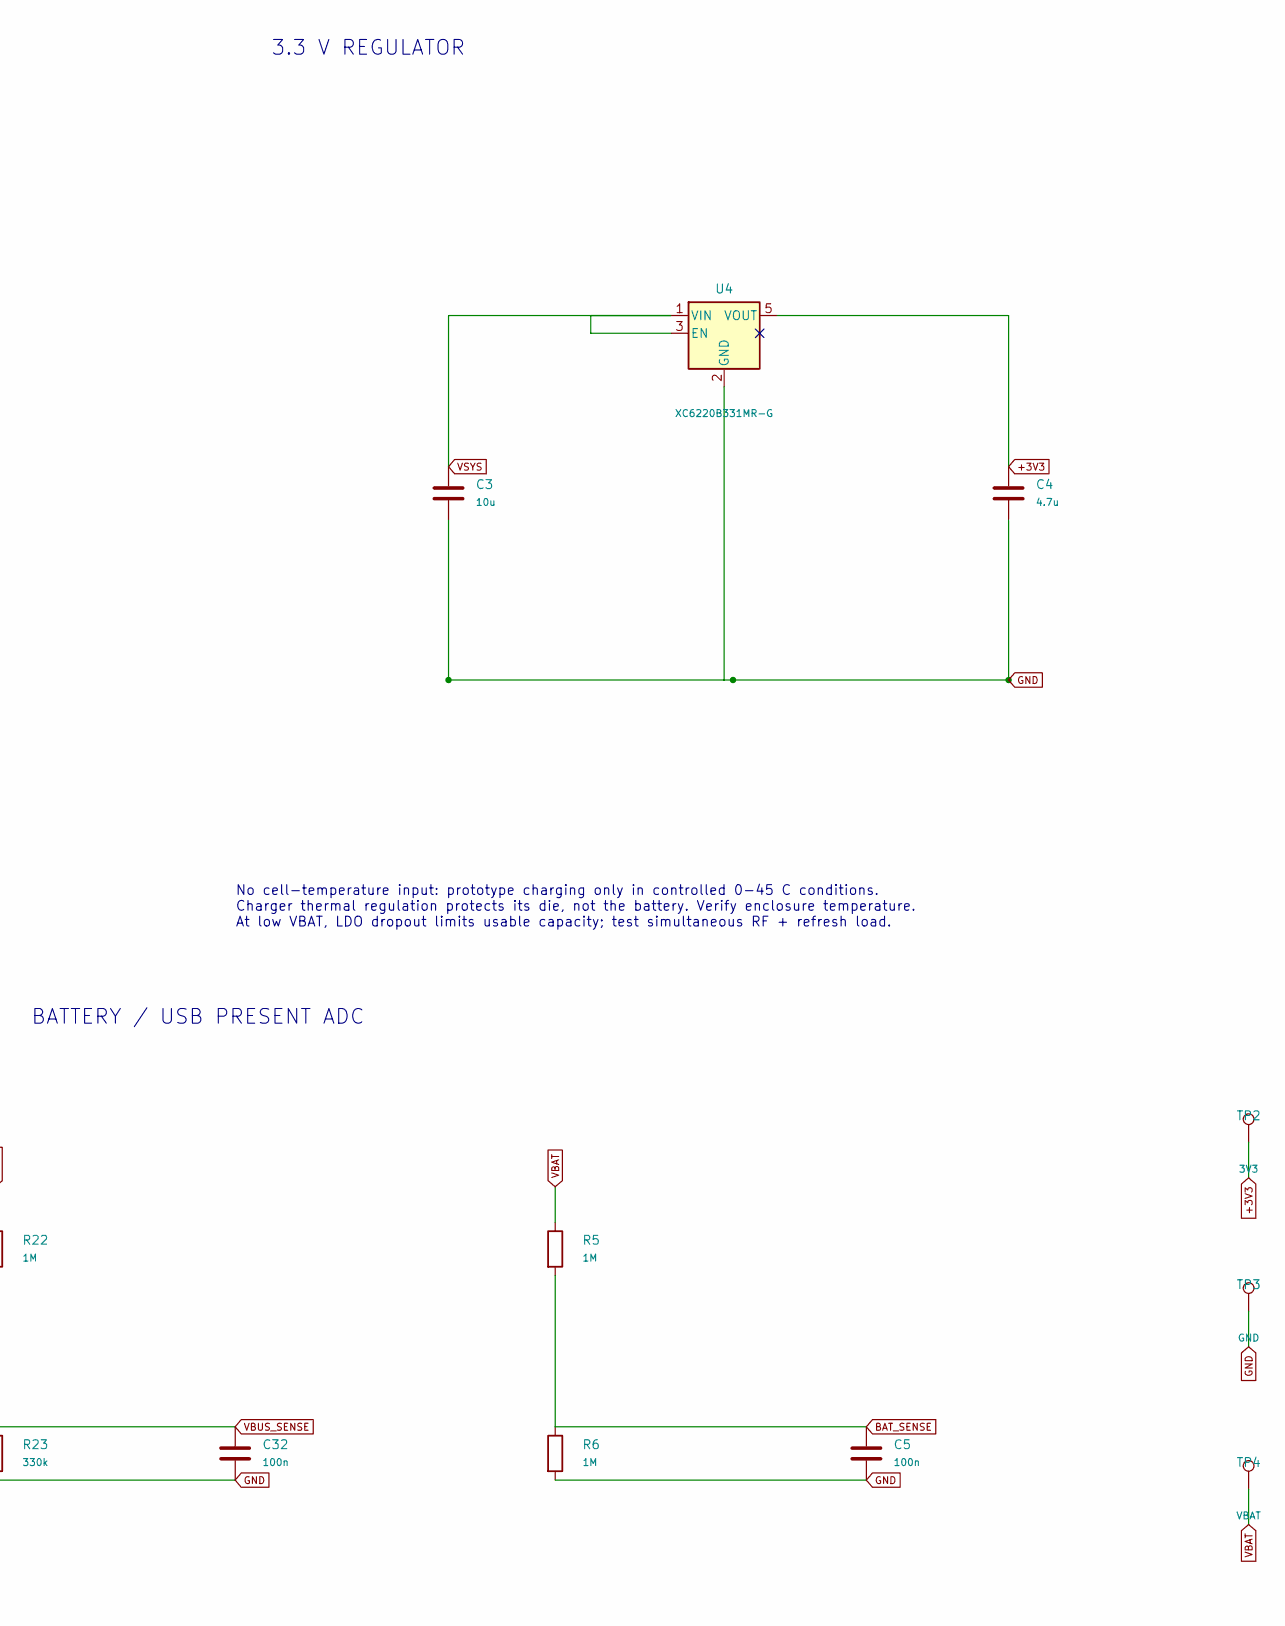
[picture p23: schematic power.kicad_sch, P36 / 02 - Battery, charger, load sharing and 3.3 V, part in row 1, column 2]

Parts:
C2, C4: 4.7u; C_0603_1608Metric
C3: 10u; C_0603_1608Metric
C5, C32: 100n; C_0402_1005Metric
C30: 22u; C_0805_2012Metric
D4: RED; LED_0603_1608Metric
D10: SS14; D_SMA
J2: JST PH2.0 battery; JST_PH_S2B-PH-SM4-TB_1x02-1MP_P2.00mm_Horizontal
Q10: AO3401A; SOT-23
R3: 10k; R_0402_1005Metric
R4: 1k; R_0402_1005Metric
R5, R6, R22: 1M; R_0402_1005Metric
R20: 100k; R_0402_1005Metric
R23: 330k; R_0402_1005Metric
TP2: 3V3; TestPoint_Pad_D1.0mm
TP3: GND; TestPoint_Pad_D1.0mm
TP4: VBAT; TestPoint_Pad_D1.0mm
U3: MCP73831T-2ACI/OT; SOT-23-5
U4: XC6220B331MR-G; SOT-23-5; LCSC C86534

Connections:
+3V3: C4.1, TP2.1, U4.5 (VOUT); also elsewhere on the board
BAT_SENSE: C5.1, R5.2, R6.1; also elsewhere on the board
CHRG_STAT: D4.1 (K), U3.1 (STAT)
GND: C2.2, C3.2, C4.2, C5.2, C30.2, C32.2, J2.1, R3.2, R6.2, R20.2, R23.2, TP3.1, U3.2 (V_{SS}), U4.2 (GND); also elsewhere on the board
LED_CHRG_A: D4.2 (A), R4.2
PROG: R3.1, U3.5 (PROG)
VBAT: C2.1, J2.2, Q10.3 (D), R5.1, TP4.1, U3.3 (V_{BAT})
VBUS: D10.2 (A), Q10.1 (G), R4.1, R20.1, R22.1, U3.4 (V_{DD}); also elsewhere on the board
VBUS_SENSE: C32.1, R22.2, R23.1; also elsewhere on the board
VSYS: C3.1, C30.1, D10.1 (K), Q10.2 (S), U4.1 (VIN), U4.3 (EN)

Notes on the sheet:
USB / BATTERY LOAD SHARING
Adafruit 1578: keyed PH pin 1 = GND, pin 2 = VBAT 500 mAh protected pack; measure incoming polarity and dimensions
MCP73831 CHARGER / 100 mA NOMINAL
3.3 V REGULATOR
BATTERY / USB PRESENT ADC
No cell-temperature input: prototype charging only in controlled 0-45 C conditions. Charger thermal regulation protects its die, not the battery. Verify enclosure temperature. At low VBAT, LDO dropout limits usable capacity; test simultaneous RF + refresh load.

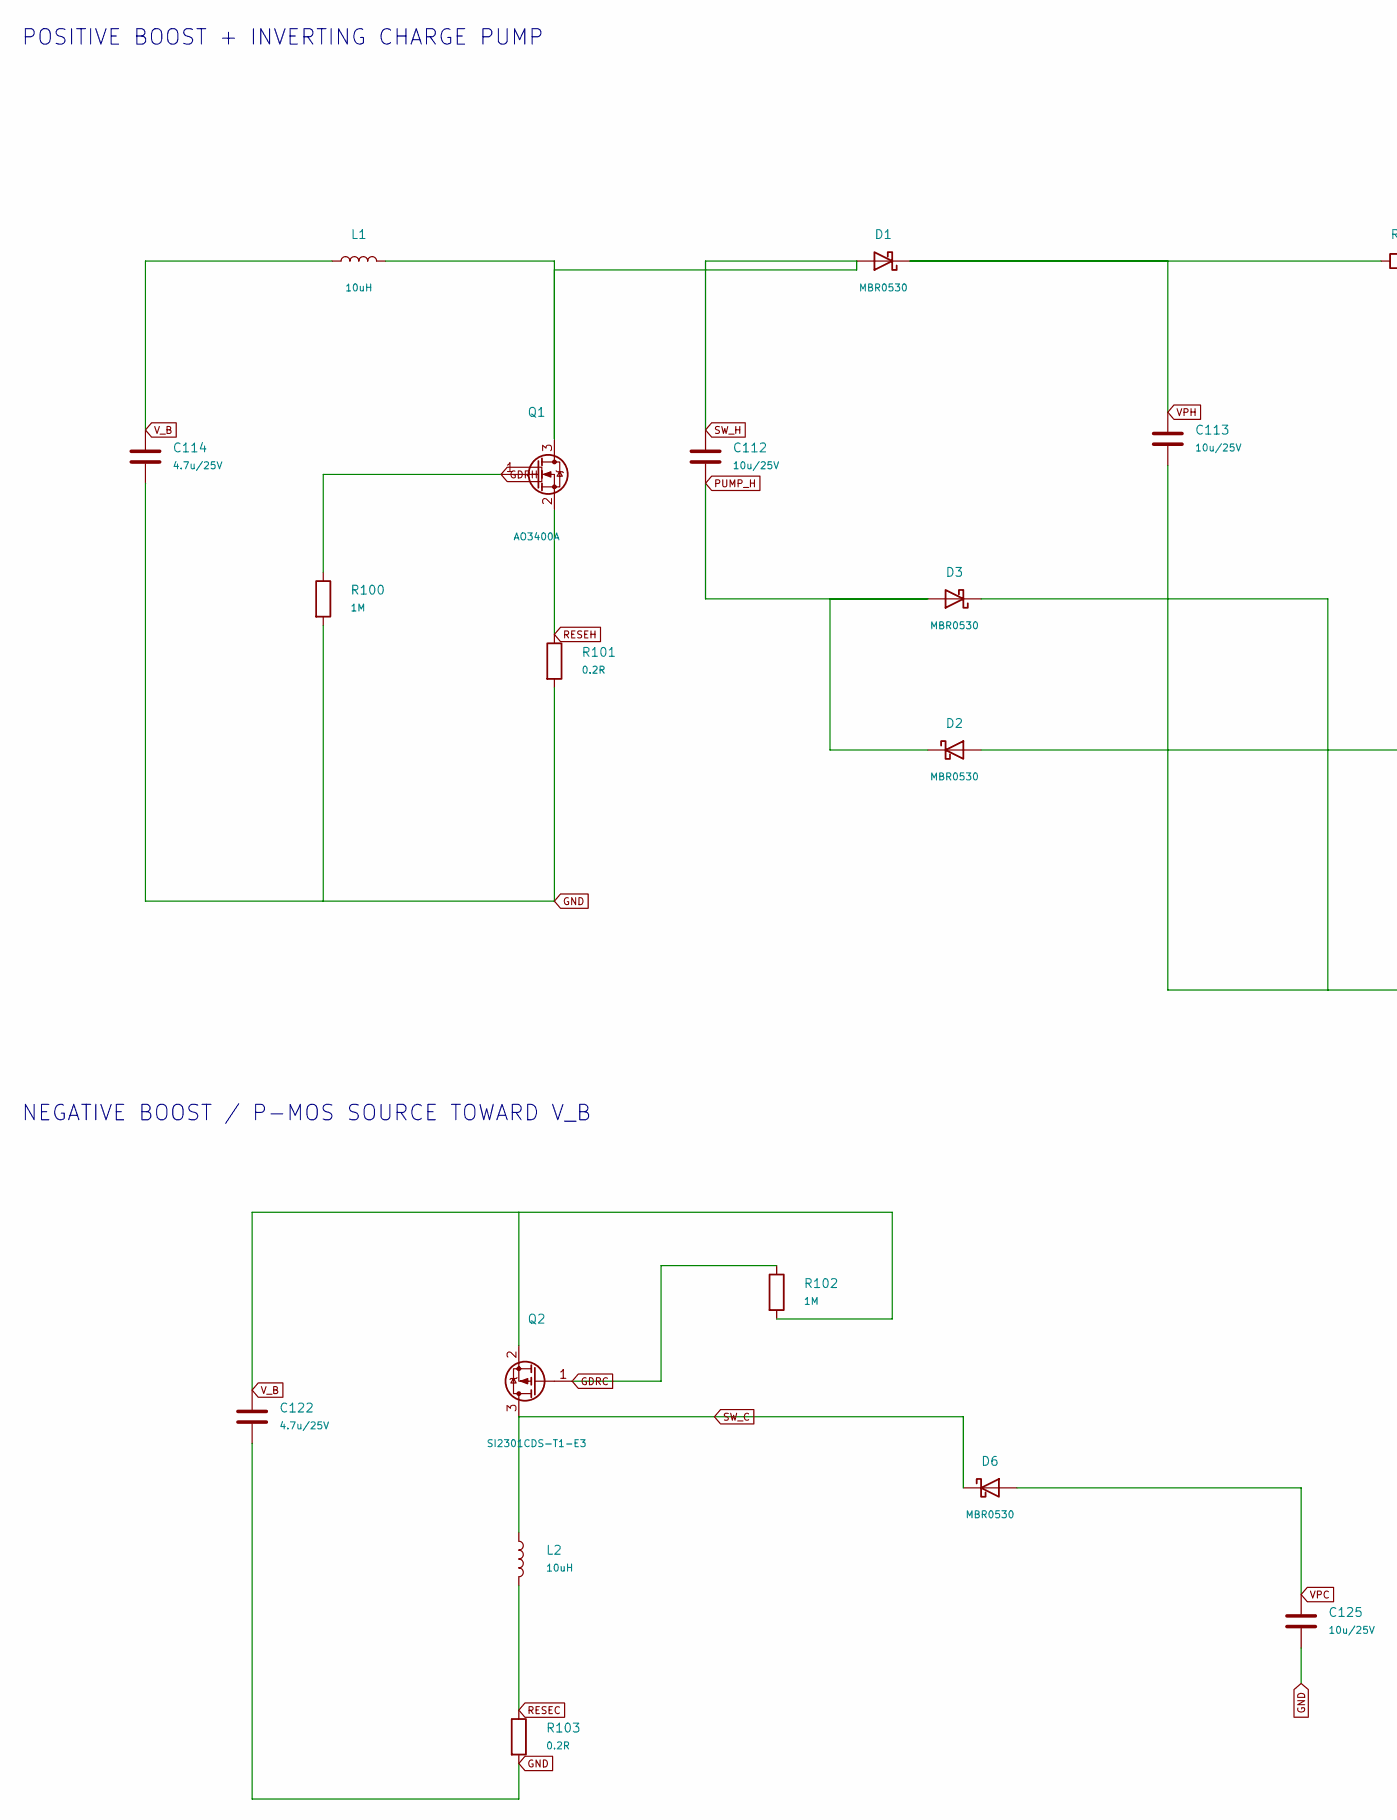
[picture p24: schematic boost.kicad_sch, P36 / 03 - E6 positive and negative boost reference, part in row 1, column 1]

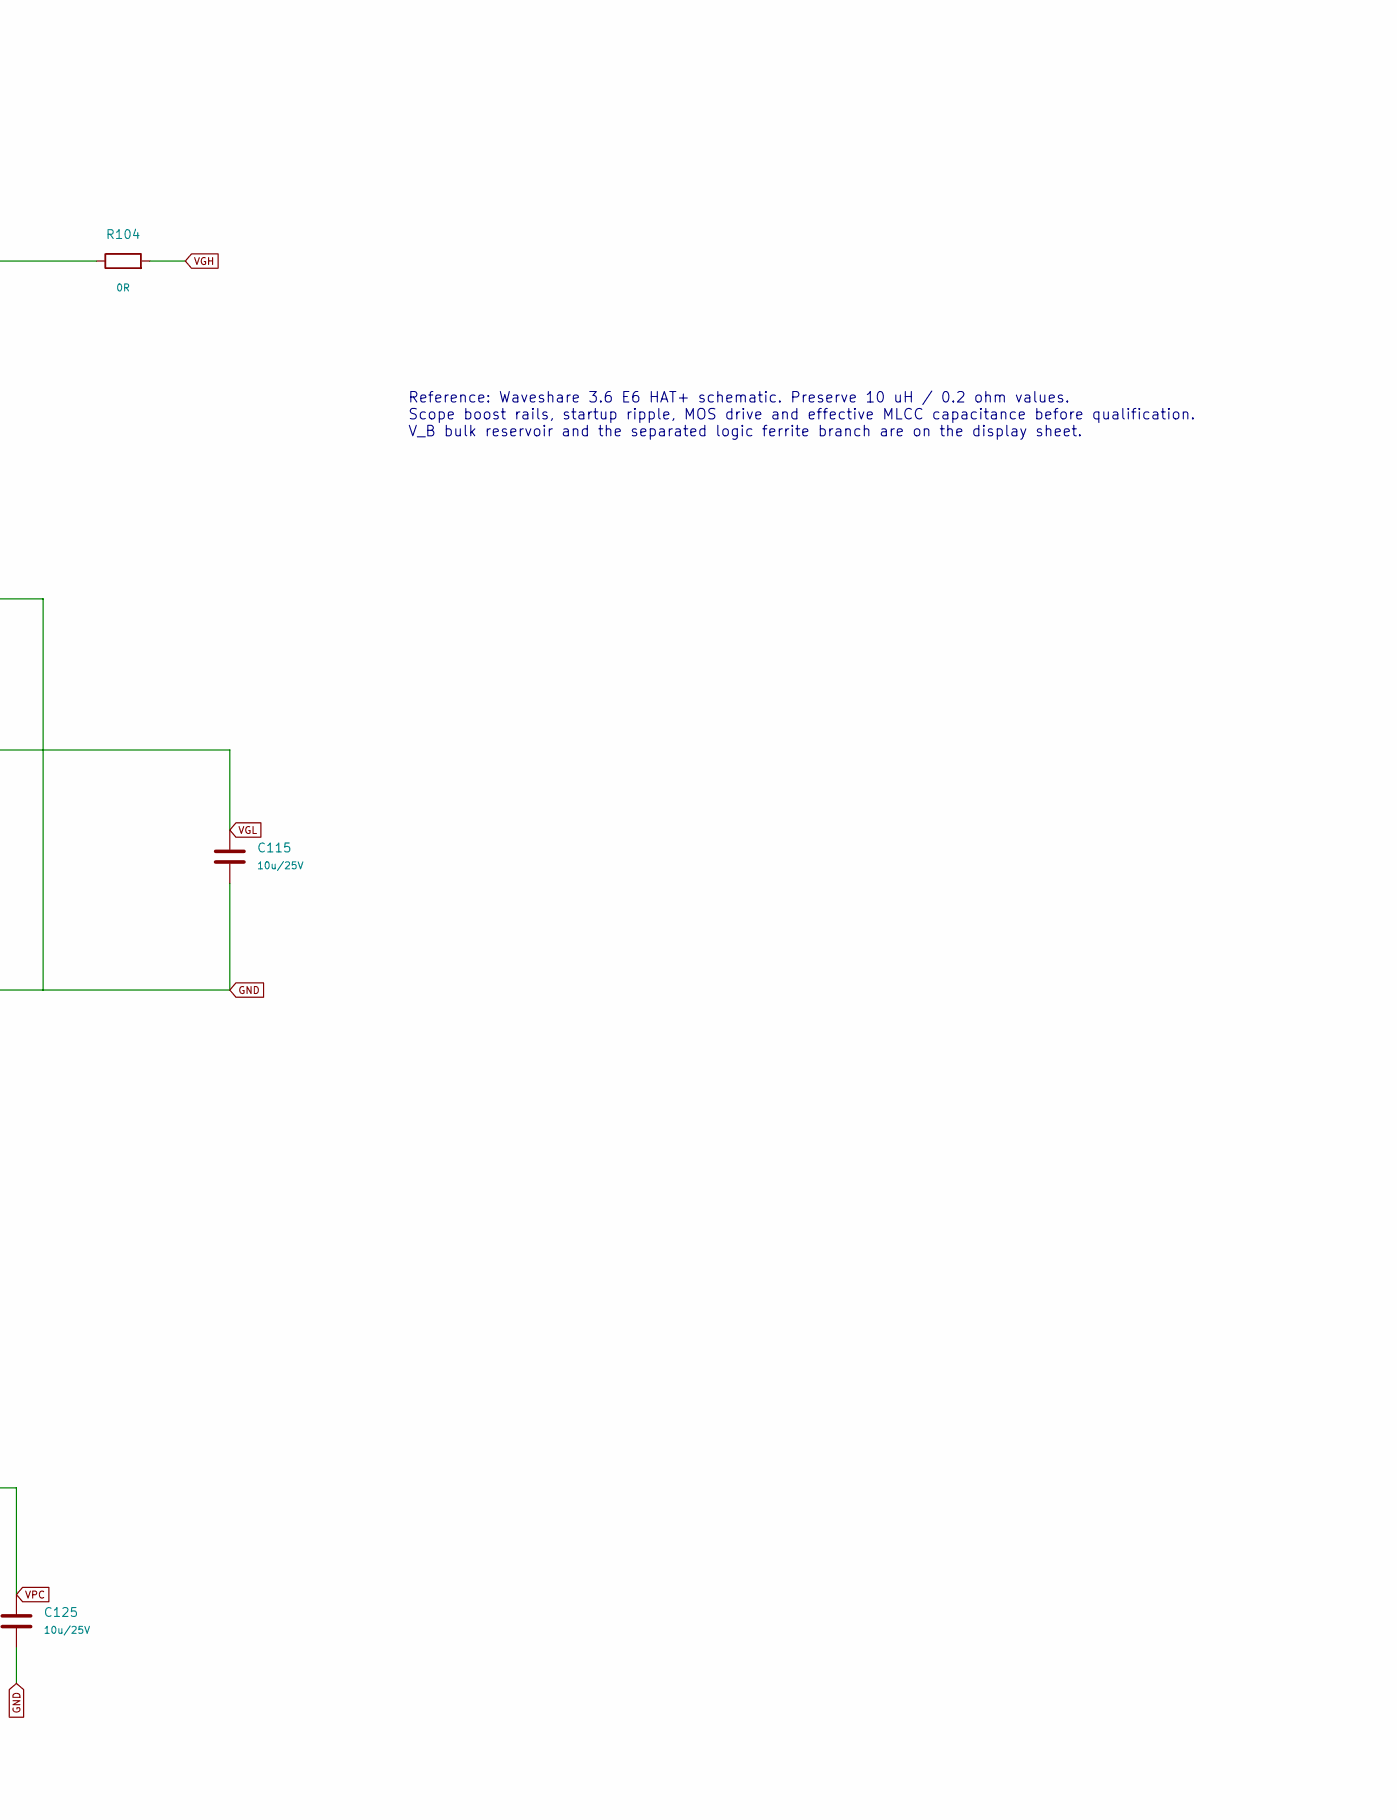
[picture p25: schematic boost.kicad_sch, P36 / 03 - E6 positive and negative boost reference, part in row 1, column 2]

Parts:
C112, C113, C115, C125: 10u/25V; C_0805_2012Metric
C114, C122: 4.7u/25V; C_0805_2012Metric
D1, D2, D3, D6: MBR0530; D_SOD-123
L1, L2: 10uH; L_Changjiang_FNR4018S
Q1: AO3400A; SOT-23
Q2: SI2301CDS-T1-E3; SOT-23
R100, R102: 1M; R_0603_1608Metric
R101, R103: 0.2R; R_0805_2012Metric
R104: 0R; R_0603_1608Metric

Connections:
GDRC: Q2.1 (G), R102.1; also elsewhere on the board
GDRH: Q1.1 (G), R100.1; also elsewhere on the board
GND: C113.2, C114.2, C115.2, C122.2, C125.2, D3.1 (K), R100.2, R101.2, R103.2; also elsewhere on the board
PUMP_H: C112.2, D2.1 (K), D3.2 (A)
RESEC: L2.2, R103.1; also elsewhere on the board
RESEH: Q1.2 (S), R101.1; also elsewhere on the board
SW_C: D6.1 (K), L2.1, Q2.3 (D)
SW_H: C112.1, D1.2 (A), L1.2, Q1.3 (D)
VGH: R104.2; also elsewhere on the board
VGL: C115.1, D2.2 (A); also elsewhere on the board
VPC: C125.1, D6.2 (A); also elsewhere on the board
VPH: C113.1, D1.1 (K), R104.1; also elsewhere on the board
V_B: C114.1, C122.1, L1.1, Q2.2 (S), R102.2; also elsewhere on the board

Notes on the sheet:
POSITIVE BOOST + INVERTING CHARGE PUMP
NEGATIVE BOOST / P-MOS SOURCE TOWARD V_B
Reference: Waveshare 3.6 E6 HAT+ schematic. Preserve 10 uH / 0.2 ohm values. Scope boost rails, startup ripple, MOS drive and effective MLCC capacitance before qualification. V_B bulk reservoir and the separated logic ferrite branch are on the display sheet.

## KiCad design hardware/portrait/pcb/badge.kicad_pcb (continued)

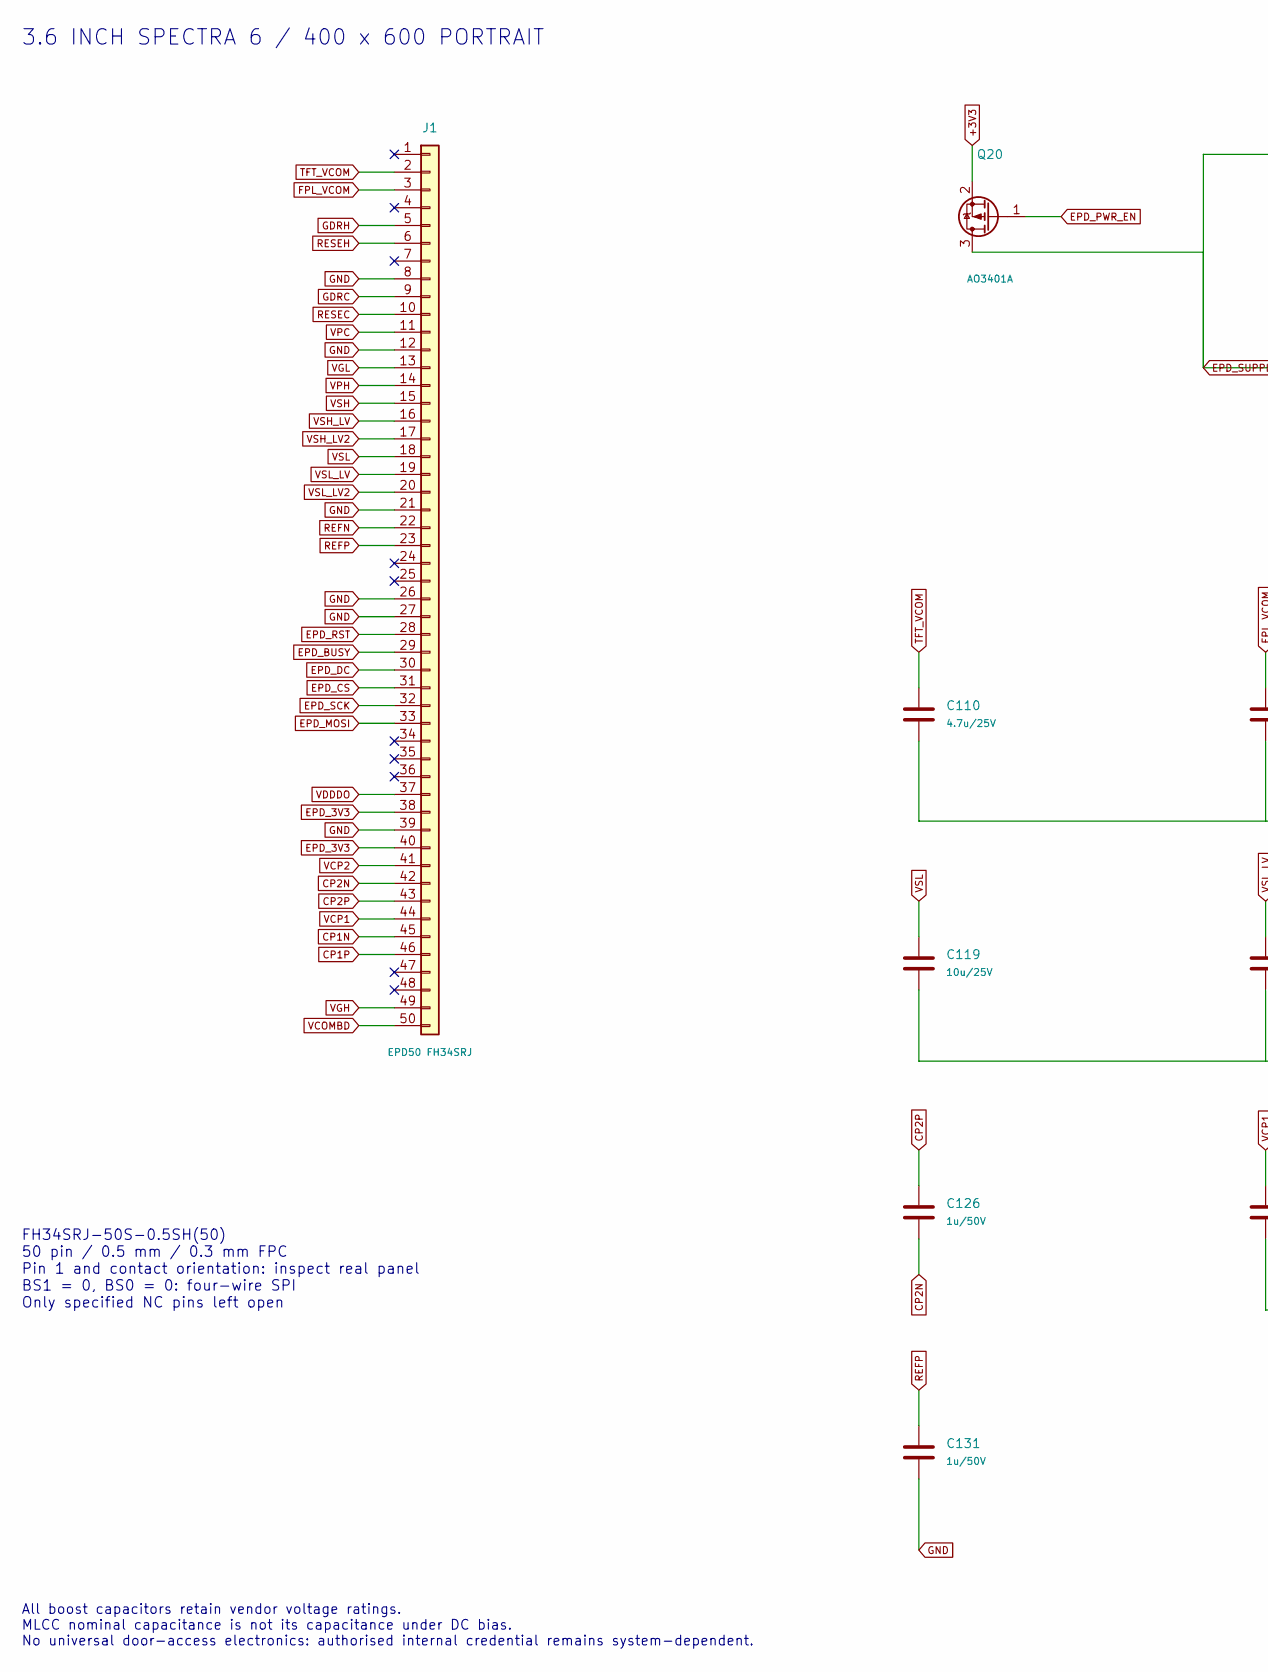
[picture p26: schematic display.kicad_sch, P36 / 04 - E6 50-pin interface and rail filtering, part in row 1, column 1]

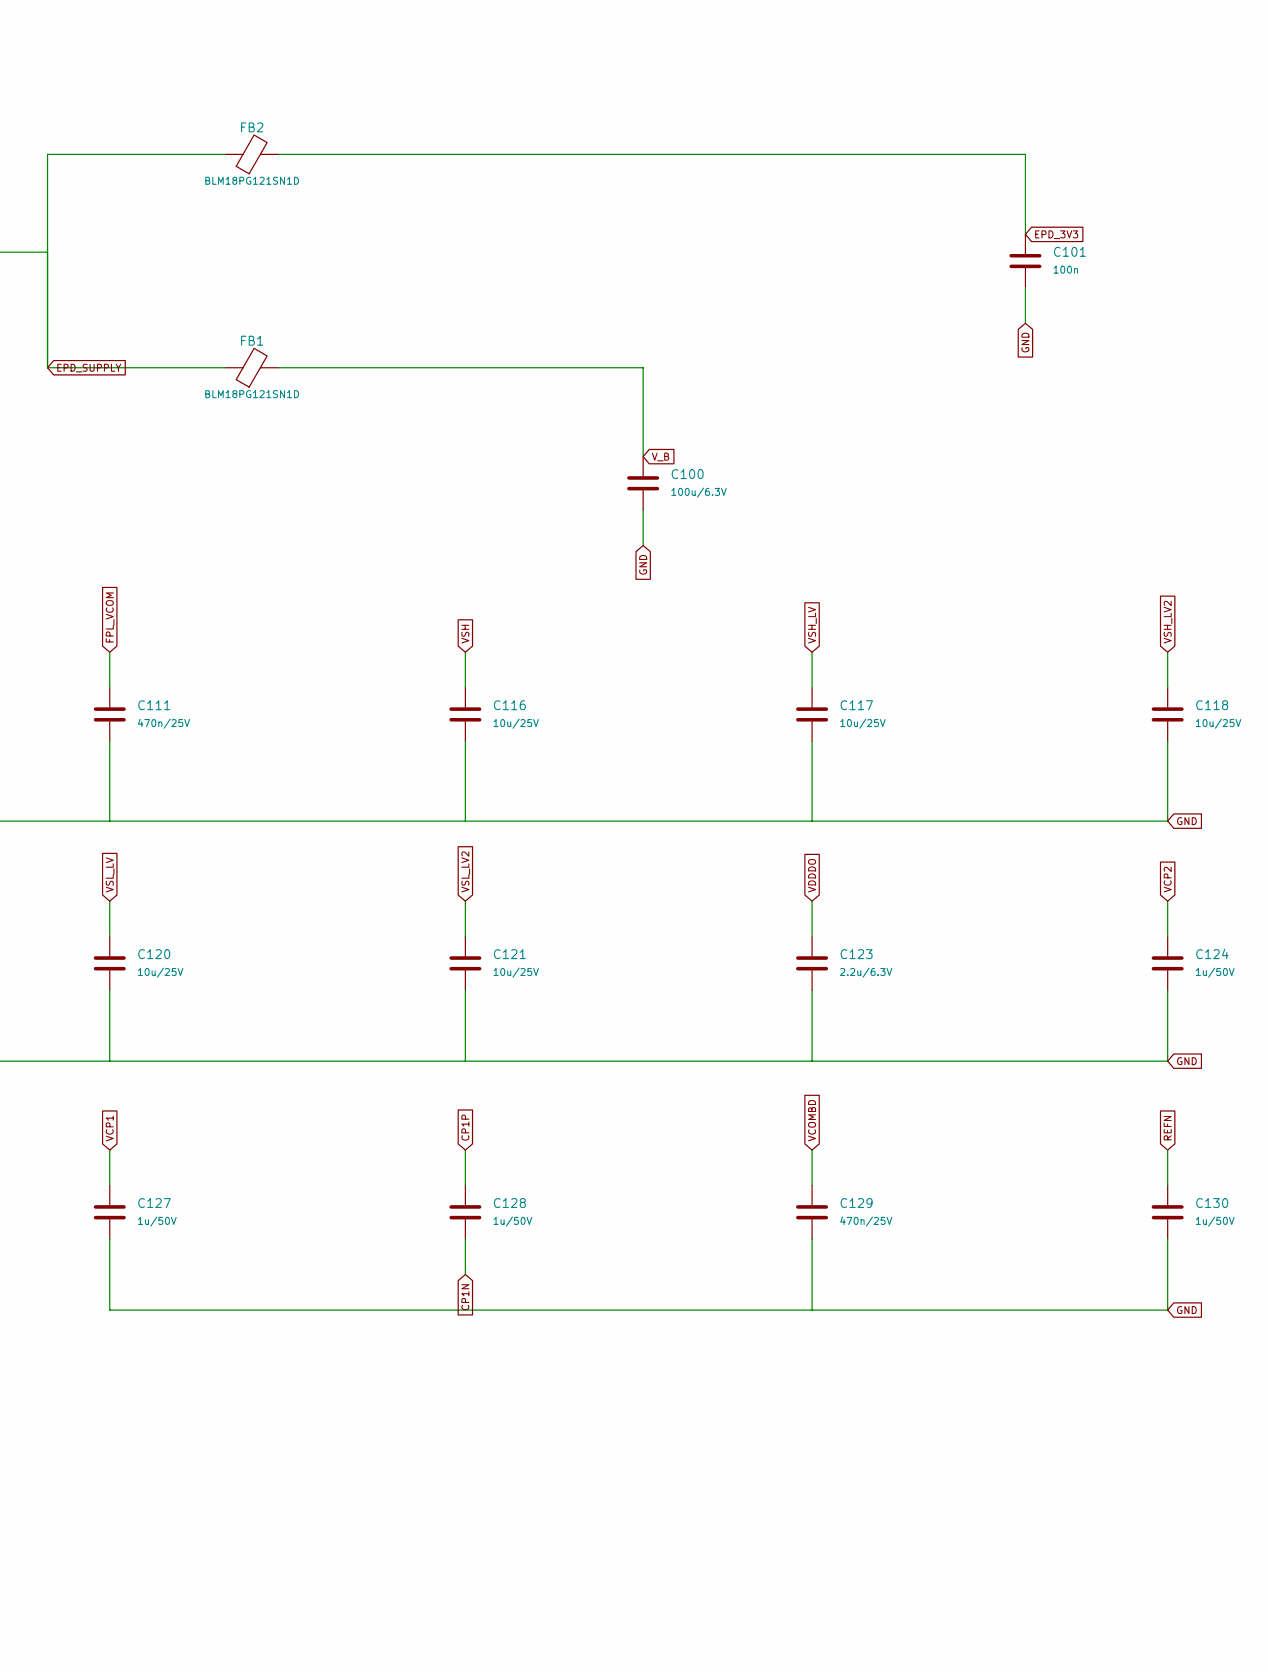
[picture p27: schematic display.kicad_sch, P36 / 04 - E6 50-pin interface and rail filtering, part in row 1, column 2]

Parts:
C100: 100u/6.3V; C_1210_3225Metric
C101: 100n; C_0402_1005Metric
C110: 4.7u/25V; C_0805_2012Metric
C111, C129: 470n/25V; C_0805_2012Metric
C116, C117, C118, C119, C120, C121: 10u/25V; C_0805_2012Metric
C123: 2.2u/6.3V; C_0805_2012Metric
C124, C126, C127, C128, C130, C131: 1u/50V; C_0805_2012Metric
FB1, FB2: BLM18PG121SN1D; L_0603_1608Metric
J1: EPD50 FH34SRJ; FH34SRJ-50S-0.5SH
Q20: AO3401A; SOT-23

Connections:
+3V3: Q20.2 (S); also elsewhere on the board
CP1N: C128.2, J1.45
CP1P: C128.1, J1.46
CP2N: C126.2, J1.42
CP2P: C126.1, J1.43
EPD_3V3: C101.1, FB2.2, J1.38, J1.40
EPD_BUSY: J1.29; also elsewhere on the board
EPD_CS: J1.31; also elsewhere on the board
EPD_DC: J1.30; also elsewhere on the board
EPD_MOSI: J1.33; also elsewhere on the board
EPD_PWR_EN: Q20.1 (G); also elsewhere on the board
EPD_RST: J1.28; also elsewhere on the board
EPD_SCK: J1.32; also elsewhere on the board
EPD_SUPPLY: FB1.1, FB2.1, Q20.3 (D)
FPL_VCOM: C111.1, J1.3
GDRC: J1.9; also elsewhere on the board
GDRH: J1.5; also elsewhere on the board
GND: C100.2, C101.2, C110.2, C111.2, C116.2, C117.2, C118.2, C119.2, C120.2, C121.2, C123.2, C124.2, C127.2, C129.2, C130.2, C131.2, J1.8, J1.12, J1.21, J1.26, J1.27, J1.39; also elsewhere on the board
REFN: C130.1, J1.22
REFP: C131.1, J1.23
RESEC: J1.10; also elsewhere on the board
RESEH: J1.6; also elsewhere on the board
TFT_VCOM: C110.1, J1.2
VCOMBD: C129.1, J1.50
VCP1: C127.1, J1.44
VCP2: C124.1, J1.41
VDDDO: C123.1, J1.37
VGH: J1.49; also elsewhere on the board
VGL: J1.13; also elsewhere on the board
VPC: J1.11; also elsewhere on the board
VPH: J1.14; also elsewhere on the board
VSH: C116.1, J1.15
VSH_LV: C117.1, J1.16
VSH_LV2: C118.1, J1.17
VSL: C119.1, J1.18
VSL_LV: C120.1, J1.19
VSL_LV2: C121.1, J1.20
V_B: C100.1, FB1.2; also elsewhere on the board

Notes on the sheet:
3.6 INCH SPECTRA 6 / 400 x 600 PORTRAIT
FH34SRJ-50S-0.5SH(50) 50 pin / 0.5 mm / 0.3 mm FPC Pin 1 and contact orientation: inspect real panel BS1 = 0, BS0 = 0: four-wire SPI Only specified NC pins left open
All boost capacitors retain vendor voltage ratings. MLCC nominal capacitance is not its capacitance under DC bias. No universal door-access electronics: authorised internal credential remains system-dependent.

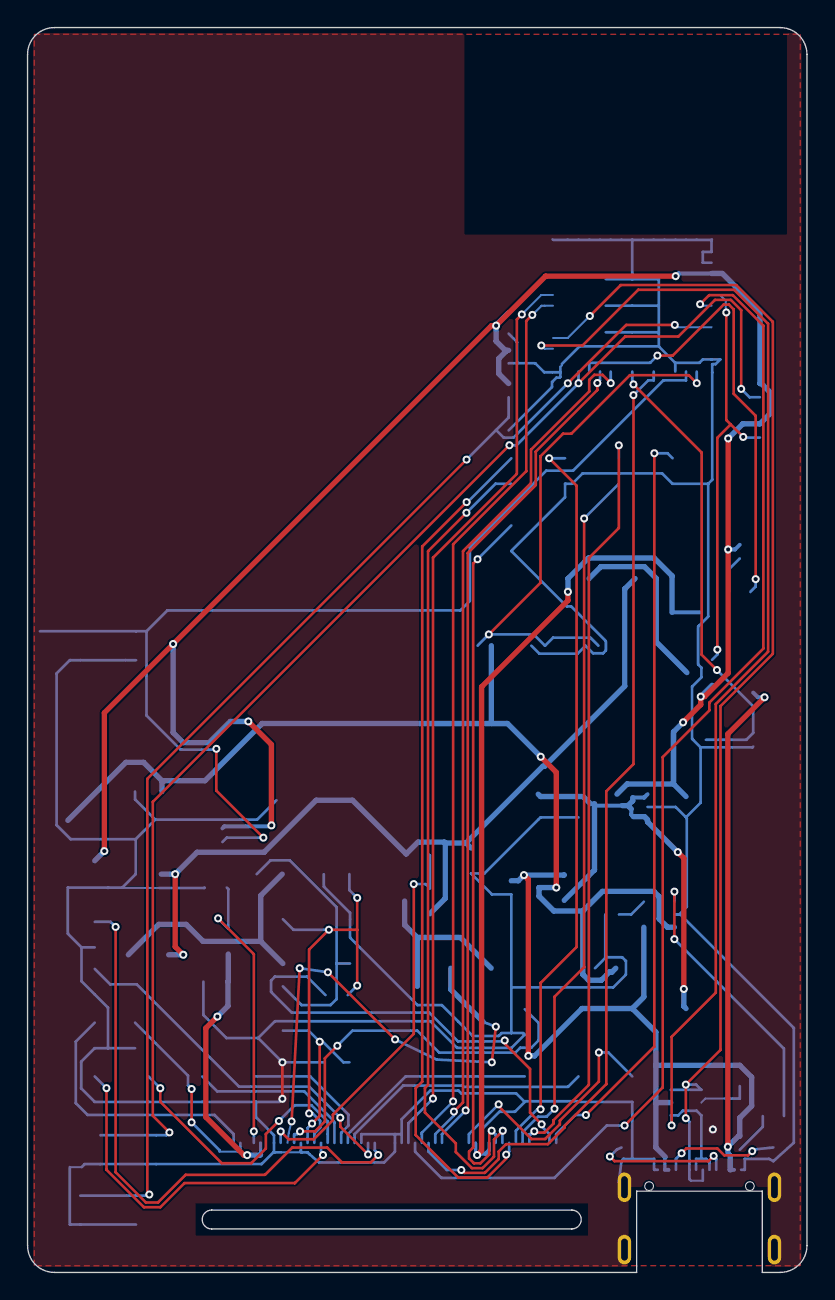
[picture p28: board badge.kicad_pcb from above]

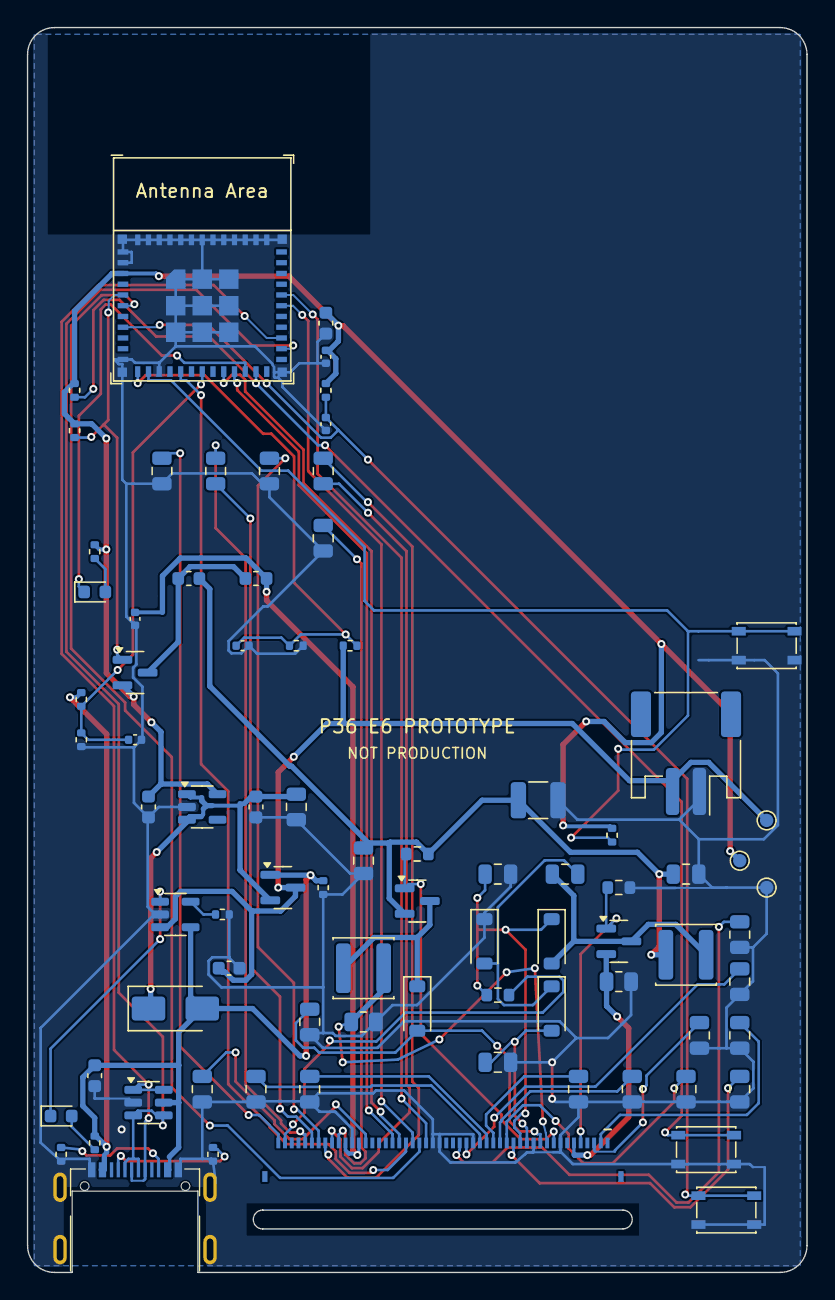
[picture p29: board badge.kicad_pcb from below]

Board: 2 copper layers, 58.0 x 92.6 mm, 81 parts (81 on the bottom side), 58 nets.

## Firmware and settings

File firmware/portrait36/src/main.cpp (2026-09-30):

// SPDX-License-Identifier: MIT
// Isolated USB full-frame diagnostic target; never substitute for H2 firmware.
#include "arduino_io.h"
#include "phone_service.h"
#include "usb_receiver.h"
#include <driver/gpio.h>
#include <esp_heap_caps.h>
#include <esp_sleep.h>
namespace {
epd36::c3::ArduinoIO io;
epd36::Driver driver(io);
epd36::PhonePowerMonitor power;
epd36::PhoneSleepPolicy sleep_policy;
bool display_completed = false;
class SerialSink final : public epd36::UploadSink {
public:
  void reply(const char *line) override {
    Serial.println(line);
    Serial.flush();
  }
  epd36::Result display(const std::uint8_t *frame, std::size_t size) override {
    const auto reading = power.sample(true);
    Serial.printf("POWER VBAT=%umV VBUS_SENSE=%umV USB=%u\n",
                  static_cast<unsigned>(reading.battery_mv),
                  static_cast<unsigned>(reading.vbus_sense_mv),
                  reading.usb_present);
    if (!reading.active_allowed) {
      io.hard_off();
      return epd36::Result::PowerUnsafe;
    }
    const auto result = driver.refresh(frame, size);
    if (result == epd36::Result::Ok)
      display_completed = true;
    return result;
  }
} sink;
epd36::FrameSession frame_session(sink);
epd36::UsbReceiver receiver(sink, frame_session);
epd36::PhoneService phone(frame_session, power);
std::uint8_t *pending_frame =
    nullptr; // one allocation, retained until MCU reset
} // namespace
void setup() {
  io.hard_off();
  gpio_hold_dis(GPIO_NUM_2);
  gpio_deep_sleep_hold_dis();
  io.hard_off();
  Serial.setRxBufferSize(4096);
  Serial.begin(115200);
  delay(100);
  Serial.println("P36 USB + local phone update; rail OFF; no automatic "
                 "refresh. RESET then HELLO.");
  Serial.println("New 50-pin 3.6E panel PCB only; not H2. USB presence is not "
                 "a voltage measurement.");
  Serial.printf(
      "heap_free=%u largest_8bit_block=%u frame_bytes=%u\n",
      static_cast<unsigned>(heap_caps_get_free_size(MALLOC_CAP_8BIT)),
      static_cast<unsigned>(heap_caps_get_largest_free_block(MALLOC_CAP_8BIT)),
      static_cast<unsigned>(epd36::kFrameBytes));
  power.begin();
  phone.begin();
  pending_frame = static_cast<std::uint8_t *>(
      heap_caps_malloc(epd36::kFrameBytes, MALLOC_CAP_8BIT));
  if (!receiver.bind_buffer(pending_frame,
                            pending_frame ? epd36::kFrameBytes : 0)) {
    Serial.println("ERR NO_MEMORY; rail OFF; uploads disabled until restart");
  }
}
void loop() {
  phone.tick(millis());
  // Bound each batch so watchdog/USB tasks and timeout checks keep running.
  for (unsigned i = 0; i < 2048 && Serial.available(); ++i) {
    const int byte = Serial.read();
    if (byte >= 0)
      receiver.feed(static_cast<std::uint8_t>(byte), millis());
  }
  receiver.tick(millis());
  const auto reading = power.sample();
  const auto now = millis();
  if (sleep_policy.should_sleep(now, reading.usb_present, phone.active(),
                                frame_session.state() ==
                                    epd36::FrameState::Receiving,
                                digitalRead(epd36::UpdatePin) == LOW,
                                !reading.active_allowed, display_completed)) {
    // UPDATE is stable HIGH before enabling LOW wake; avoids a reset/wake loop.
    io.hard_off();
    esp_sleep_disable_wakeup_source(ESP_SLEEP_WAKEUP_ALL);
    const auto wake_result = esp_deep_sleep_enable_gpio_wakeup(
        epd36::UpdateWakeMask, ESP_GPIO_WAKEUP_GPIO_LOW);
    if (wake_result == ESP_OK && gpio_hold_en(GPIO_NUM_2) == ESP_OK) {
      gpio_deep_sleep_hold_en();
      Serial.println("SLEEP: screen rail OFF; short UPDATE wakes USB, hold 2s "
                     "for phone. USB insertion alone is not a wake source.");
      Serial.flush();
      esp_deep_sleep_start();
    } else {
      Serial.printf("ERR WAKE_SETUP %d; refusing sleep\n",
                    static_cast<int>(wake_result));
      delay(1000);
    }
  }
  delay(1);
}

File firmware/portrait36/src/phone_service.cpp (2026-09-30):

// SPDX-License-Identifier: MIT
#include "phone_service.h"
#include "phone_page.h"
#include "phone_setup_render.h"
#include "portrait_frame.h"
#include <Arduino.h>
#include <cstdio>
#include <cstring>
#include <esp_heap_caps.h>
#include <esp_system.h>
namespace epd36 {
namespace {

void wipe(char *p, std::size_t n) {
  volatile char *v = p;
  while (n--)
    *v++ = 0;
}
const char *reason(unsigned code) {
  switch (code) {
  case 200:
    return "OK";
  case 202:
    return "Accepted";
  case 400:
    return "Bad Request";
  case 401:
    return "Unauthorized";
  case 403:
    return "Forbidden";
  case 404:
    return "Not Found";
  case 405:
    return "Method Not Allowed";
  case 408:
    return "Request Timeout";
  case 409:
    return "Conflict";
  case 411:
    return "Length Required";
  case 413:
    return "Content Too Large";
  case 415:
    return "Unsupported Media Type";
  case 422:
    return "Unprocessable Content";
  case 431:
    return "Request Header Fields Too Large";
  default:
    return "Service Unavailable";
  }
}
} // namespace
void PhoneService::begin() {
  pinMode(UpdatePin, INPUT);
  WiFi.persistent(false);
  WiFi.mode(WIFI_OFF);
  Serial.println(
      "PHONE: hold UPDATE 2s to replace current image with temporary "
      "WiFi credentials; AP is OFF.");
}
void PhoneService::stop() {
  client_.stop();
  server_.end();
  api_.deactivate();
  if (session_.owner() == UploadSource::Phone)
    session_.reset(UploadSource::Phone);
  WiFi.softAPdisconnect(true);
  WiFi.mode(WIFI_OFF);
  active_ = false;
  success_seen_ = false;
  wipe(password_, sizeof(password_));
  wipe(token_, sizeof(token_));
  wipe(ssid_, sizeof(ssid_));
}
bool PhoneService::enable_from_button(std::uint32_t now) {
  if (session_.state() == FrameState::Receiving || api_.queued()) {
    Serial.println(
        "PHONE ERR Busy: finish/reset upload, release UPDATE and hold again");
    return false;
  }
  if (!power_.sample(true).active_allowed) {
    Serial.println("PHONE ERR PowerUnsafe; WiFi not started");
    return false;
  }
  if (active_)
    stop();
  std::uint8_t *frame = nullptr;
  const auto prep = session_.prepare_local_frame(now, frame);
  if (prep != SessionStatus::Ok) {
    Serial.printf("PHONE ERR %s\n", session_status_name(prep));
    return false;
  }
  const auto before = heap_caps_get_free_size(MALLOC_CAP_8BIT);
  Serial.printf(
      "PHONE heap before WiFi: free=%u largest=%u shared_frame=120000 "
      "parser=%u\n",
      static_cast<unsigned>(before),
      static_cast<unsigned>(heap_caps_get_largest_free_block(MALLOC_CAP_8BIT)),
      static_cast<unsigned>(sizeof(request_)));
  if (before < 65536) {
    session_.reset(UploadSource::Phone);
    Serial.println("PHONE ERR NoMemory before WiFi; USB remains available");
    return false;
  }
  // WiFi.mode(AP) starts the RF driver before esp_fill_random; no STA
  // credentials.
  WiFi.persistent(false);
  if (!WiFi.mode(WIFI_AP)) {
    stop();
    Serial.println("PHONE ERR AP start failed");
    return false;
  }
  std::uint8_t random[36];
  esp_fill_random(random, sizeof(random));
  const char *hex = "0123456789ABCDEF";
  const char *alphabet = "ABCDEFGHJKLMNPQRSTUVWXYZ23456789";
  std::snprintf(ssid_, sizeof(ssid_), "P36-%02X%02X%02X%02X", random[0],
                random[1], random[2], random[3]);
  for (unsigned i = 0; i < 16; ++i) {
    password_[i] = alphabet[random[4 + i] & 31];
    token_[2 * i] = hex[random[20 + i] >> 4];
    token_[2 * i + 1] = hex[random[20 + i] & 15];
  }
  password_[16] = token_[32] = 0;
  for (volatile std::uint8_t &b : random)
    b = 0;
  if (!WiFi.softAPConfig(IPAddress(192, 168, 4, 1), IPAddress(192, 168, 4, 1),
                         IPAddress(255, 255, 255, 0)) ||
      !WiFi.softAP(ssid_, password_, 1, false, 1)) {
    stop();
    Serial.println("PHONE ERR AP configuration failed");
    return false;
  }
  const auto after = heap_caps_get_free_size(MALLOC_CAP_8BIT);
  Serial.printf(
      "PHONE heap after WiFi: free=%u largest=%u\n",
      static_cast<unsigned>(after),
      static_cast<unsigned>(heap_caps_get_largest_free_block(MALLOC_CAP_8BIT)));
  if (after < 24576 ||
      heap_caps_get_largest_free_block(MALLOC_CAP_8BIT) < 8192) {
    stop();
    Serial.println("PHONE ERR NoMemory after WiFi; AP stopped");
    return false;
  }
  std::uint32_t crc = 0;
  if (!phone_render_setup(frame, kFrameBytes, ssid_, password_, token_) ||
      !portrait::frame_crc32(frame, kFrameBytes, crc) ||
      session_.seal_local_frame(crc, millis()) != SessionStatus::Ok) {
    stop();
    Serial.println("PHONE ERR setup frame invalid");
    return false;
  }
  Serial.println("PHONE replacing image with temporary credentials; refresh "
                 "can take about 15s");
  const auto result = session_.show(UploadSource::Phone, crc, millis());
  if (result != SessionStatus::Ok) {
    Serial.printf(
        "PHONE ERR credentials not confirmed visible: %s / %s; AP stopped\n",
        session_status_name(result),
        result_name(session_.last_display_result()));
    stop();
    return false;
  }
  session_.reset(UploadSource::Phone);
  api_.authorize(token_);
  server_.begin();
  server_.setNoDelay(true);
  active_ = true;
  started_at_ = millis();
  Serial.printf("PHONE AP enabled for 10min. SSID=%s password=%s "
                "URL=http://192.168.4.1/#token=%s\n",
                ssid_, password_, token_);
  Serial.println("PHONE display completed without reported error; visually "
                 "verify credentials on the real panel.");
  return true;
}
void PhoneService::reply(unsigned code, const char *type, const char *body,
                         std::size_t size) {
  char head[512];
  const int n = std::snprintf(
      head, sizeof(head),
      "HTTP/1.1 %u %s\r\nContent-Type: %s\r\nContent-Length: %u\r\nConnection: "
      "close\r\nCache-Control: no-store\r\nX-Content-Type-Options: "
      "nosniff\r\nReferrer-Policy: no-referrer\r\nContent-Security-Policy: "
      "default-src 'self'; script-src 'unsafe-inline'; style-src "
      "'unsafe-inline'; img-src 'self' blob: data:; connect-src 'self'; "
      "frame-ancestors 'none'\r\n\r\n",
      code, reason(code), type, static_cast<unsigned>(size));
  if (n <= 0 || static_cast<std::size_t>(n) >= sizeof(head)) {
    client_.stop();
    return;
  }
  client_.write(reinterpret_cast<const std::uint8_t *>(head), n);
  for (std::size_t offset = 0; offset < size && client_.connected();) {
    const auto count = (size - offset) > 1024 ? 1024 : (size - offset);
    const auto sent = client_.write(
        reinterpret_cast<const std::uint8_t *>(body + offset), count);
    if (!sent)
      break;
    offset += sent;
    delay(0);
  }
  client_.stop();
}
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

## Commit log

2026-09-30 Add the P36 color e-ink work badge review candidate.
    Initial import from D:\badge\P36-review-candidate. KiCad lock files and the footprint cache stay local.
    [badge.kicad_pcb, badge.kicad_sch, boost.kicad_sch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]
2026-09-30 Save the KiCad project file rewritten when the board was opened.
    KiCad filled in the missing ERC pin map and schematic defaults in badge.kicad_pro. The automatic backup zip stays local.
